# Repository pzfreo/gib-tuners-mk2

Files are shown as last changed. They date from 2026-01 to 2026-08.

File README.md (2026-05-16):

# gib-tuners

Parametric CAD project for historic guitar tuner restoration using build123d.

## Overview

This project generates 5-gang tuning machine assemblies (right-hand and left-hand variants) based on the engineering specification in `spec.md`. The design uses a "sandwich" assembly approach where all components can be inserted and retained without soldering.

## Installation

```bash
pip install -e .
```

Or for development:

```bash
pip install -e ".[dev]"
```

## Usage

### Build assemblies

```bash
# Production scale (1:1), both hands
python scripts/build_all.py --scale 1.0 --hand both

# 2x prototype for FDM printing
python scripts/build_all.py --scale 2.0 --tolerance prototype_fdm

# Just right-hand at production tolerance
python scripts/build_all.py --hand right

# Validate geometry without building
python scripts/build_all.py --validate-only
```

### Build frame only

```bash
python scripts/build_frame.py
python scripts/build_frame.py --scale 2.0 --hand left
```

### Visualize (requires OCP viewer)

```bash
python scripts/visualize.py
python scripts/visualize.py --component frame
python scripts/visualize.py --component tuner --scale 2.0
```

## Project Structure

```
gib-tuners-mk2/
├── src/gib_tuners/
│   ├── config/          # Dataclasses and parameters
│   ├── components/      # Individual parts (frame, peg_head, etc.)
│   ├── assembly/        # Assemblies (tuner unit, gang assembly)
│   ├── features/        # Reusable CAD operations
│   ├── export/          # STEP/STL export
│   └── utils/           # Mirroring, validation
├── scripts/             # CLI tools
├── tests/               # Test suite
├── reference/           # Reference STEP/DXF files
└── output/              # Generated files (gitignored)
```

## Key Files

- `spec.md` - Master engineering specification
- `7mm-globoid.json` - Gear calculator parameters
- `ARCHITECTURE.md` - Design documentation
- `CLAUDE.md` - Claude Code guidance

## Testing

```bash
pytest tests/
pytest tests/test_validation.py  # Spec Section 9 checks
```

## License

This project is released under the **Open Community License (OCL v1)** — a
non-commercial, share-alike license for open hardware and software. See
[`LICENSE`](./LICENSE) for the full text, or the canonical source at
[OpenCommunityLicence/OpenCommunityLicence](https://github.com/OpenCommunityLicence/OpenCommunityLicence).

In short:

- **Non-commercial users** may freely use, copy, modify, and hack the
  designs and code. If you redistribute your derivatives, you **must**
  release them under OCL or another non-commercial share-alike license
  that grants downstream users the same rights.
- **Commercial / business users** may use and modify the designs solely
  for their own internal production. Replicating, reselling, or
  otherwise commercialising the product or its components (other than
  internal right-to-repair) requires a **separate commercial license**
  from the copyright holder.
- Automated text and data mining of this repository is **not permitted**
  without explicit prior permission.

For commercial licensing enquiries, contact the copyright holder listed
in [`LICENSE`](./LICENSE).

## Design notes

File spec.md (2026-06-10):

# **Master Engineering Specification: Historic Tuner Restoration**

## **1\. System Overview**

* **Product:** 5-Gang Tuning Machine Assembly (Historic Reproduction).
* **Variants:** Right Hand (RH) and Left Hand (LH).
* **Mechanism:** Single-start Worm Drive (Sandwich Assembly).
  * **RH Unit:** Right-Hand (Clockwise) Thread.
  * **LH Unit:** Left-Hand (Counter-Clockwise) Thread.
  * *Goal:* Symmetrical tuning action (turning knobs "up" towards the headstock tip always tightens the string).
* **Manufacturing Strategy:**
  * **Frame:** Subtractive machining from **10.35mm² Brass Box Section** (1.0mm walls).
  * **Peg Head + Worm:** Investment cast as single piece, finish-machined.
  * **String Post:** Swiss Screw Machining (Auto-Lathe).
  * **Wheel:** Custom generated (separate, mates with string post).
* **Repairability:** Fully disassembleable (no soldered lids).
* **Design Constraint:** External frame geometry (outline, cutouts, mounting holes) is fixed to match historic appearance. Internal components (worm, wheel, posts) may be adjusted for function.

---

## **1a\. Parametric Build Configuration**

The build123d script shall support the following parameters:

### **Frame Parameters**
| Parameter | Default | Description |
|---|---|---|
| `box_outer` | 10.0mm | Outer dimension of square tube |
| `wall_thickness` | 1.0mm | Wall thickness (c13-10 production value, set in `config/c13-10/tuner_config.json`) |
| `housing_length` | 16.2mm | Length of each rigid box section |
| `end_length` | 10.0mm | Length from frame end to first/last housing edge (symmetric) |
| `num_housings` | 5 | Number of tuner positions (1 to N) |
| `tuner_pitch` | 27.2mm | Center-to-center spacing between adjacent tuners |
| `total_length` | *computed* | = 2 * end_length + housing_length + (num_housings - 1) * pitch |

**Note:** `total_length` is computed from the other parameters, ensuring symmetric ends regardless of the number of housings.

### **Tolerance Profiles**
| Profile | Bearing Holes | Clearance Holes | Use Case |
|---|---|---|---|
| `production` | +0.05mm (reamed) | +0.20mm | Machined brass, 100N rated |
| `prototype_resin` | +0.10mm | +0.20mm | 1:1 resin print validation |
| `prototype_fdm` | +0.20mm | +0.30mm | 2:1 FDM functional test |

*Bearing holes are derived: shaft diameter + bearing_clearance (0.05mm). Clearance holes: worm entry = shoulder + clearance, wheel inlet (5.1mm).*

### **Scale Parameter**
| Parameter | Default | Description |
|---|---|---|
| `scale` | 1.0 | Geometry scale factor (use 2.0 for FDM prototype) |

*Note: When `scale=2.0`, all dimensions are doubled. The script outputs both RH and LH variants at the specified scale.*

## **2\. Component A: The Reinforced Frame**

* **Material:** CZ121 Brass Box Section (10.0mm x 10.0mm x 1.0mm wall).
* **Total Length:** 145.0mm.
* **Internal Cavity:** 8.0mm x 8.0mm (10.0mm outer - 2×1.0mm walls).
* **End Length:** 10.0mm from frame end to first/last housing edge (symmetric ends).
* **Topology:**
  * **5x Rigid Housings:** 16.2mm long sections of full box profile to resist gear tension.
  * **Connectors:** Walls milled away between housings, leaving only the **Mounting Plate** (1.0mm thick) at Z=0 to connect the unit.
  * **Tuner Pitch:** 27.2mm center-to-center spacing between adjacent tuners.
* **Hand Identification:** "R" or "L" etched on inside surface of mounting plate (3mm tall, 0.3mm deep) near frame end at Y=2mm. Visible from below when looking into mechanism cavity.

### **Coordinate System**

```
     PLAYER'S VIEW (looking down at installed tuner)
     ================================================

        ↑ Posts stick up into air (+Z direction)
        |
   ─────┴─────  Z=0: Mounting plate (TOP, visible from above)
   │ mechanism │     - Mounting screw holes
   │  cavity   │     - Post bearing holes (posts emerge upward)
   │    ●────→ │     - "R"/"L" etching on INSIDE (Z=-1.1 surface)
   └───────────┘  Z=-10.0: Bottom (embedded in headstock)
        |              - Wheel inlet hole ONLY (for assembly)
        ↓
     [WOOD CAVITY]

   Z-axis convention:
   - Z=0        : Mounting plate surface (visible, sits on headstock)
   - Z=-1.0     : Inside surface of mounting plate (where "R"/"L" goes)
   - Z=-9.0     : Inside surface of bottom plate
   - Z=-10.0    : Bottom surface (inside wood cavity)
```

| Item | Z Location | Notes |
|---|---|---|
| Mounting plate surface | Z=0 | Visible from above |
| Mounting holes | Z=0 to Z=-1.1 | Drilled through top plate |
| Post bearing holes | Z=0 to Z=-1.1 | ø = post bearing_diameter + bearing_clearance |
| "R"/"L" etching | Z=-1.1 | Inside surface of mounting plate |
| Worm entry (RH) | RIGHT side (+X) | ø = peg shoulder_diameter + bearing_clearance |
| Peg bearing (RH) | LEFT side (-X) | ø = peg shaft_diameter + bearing_clearance |
| Wheel inlet | Z=-10.0 | Bottom plate, for assembly |

### **Mounting Holes**

* **Quantity:** 6 holes
* **Diameter:** ø3.0mm (clearance for mushroom-head bolts)
* **Location:** Bottom plate, in the gap sections between housings

| Hole # | Y Position (from frame start) | Description |
|---|---|---|
| 1 | 5.0mm | Before Housing 1 (centered in 0-10mm gap) |
| 2 | 31.7mm | Between Housing 1 & 2 |
| 3 | 58.9mm | Between Housing 2 & 3 |
| 4 | 86.1mm | Between Housing 3 & 4 |
| 5 | 113.3mm | Between Housing 4 & 5 |
| 6 | 140.0mm | After Housing 5 (centered in 135-145mm gap) |

### **Housing Positions (Symmetric)**

Housing positions are calculated to ensure symmetric 10mm ends:
- First center = (total_length - (num_housings - 1) * pitch) / 2 = (145 - 108.8) / 2 = 18.1mm

| Housing # | Center Y Position | Description |
|---|---|---|
| 1 | 18.1mm | First tuner |
| 2 | 45.3mm | Second tuner |
| 3 | 72.5mm | Third tuner (frame center) |
| 4 | 99.7mm | Fourth tuner |
| 5 | 126.9mm | Fifth tuner |

### **The "Sandwich" Drilling Pattern (Per Housing)**

To enable assembly without soldering:

1. **Bottom Face (Wheel Inlet):** ø5.1mm through-hole.
   * *Function:* Allows M2 washer/screw access for post retention. Wheel slides in sideways from open frame end.
2. **Top Face (Post Bearing):** bearing_diameter + bearing_clearance through-hole (reamed).
   * *Function:* Acts as the journal bearing for the String Post (5.0mm shaft, +0.05mm clearance).
3. **Side Faces (Worm Axle):** Asymmetric through-holes.
   * **Entry Side:** shoulder_diameter + bearing_clearance (shoulder must clear worm tip).
   * **Bearing Side:** shaft_diameter + bearing_clearance (reamed).
   * *Note:* For RH frame, entry is on RIGHT side (+X). LH frame is mirrored.
   * *Retention:* Cap (8.5mm) sits against frame exterior, cannot pass through entry hole.

## **3\. Component B: The Gear Set**

* **Constraint:** Wheel slides in sideways from open frame end (worm must be installed first for globoid meshing).
* **Module:** **0.6** (M0.6)
* **Pressure Angle:** **20°**

**IMPORTANT:** All gear parameters (ratio, center distance, diameters, tooth counts) are defined in `config/<profile>/worm_gear.json`. The JSON file is the **source of truth** for gear geometry. Do not hardcode gear values in code or tests—always load from the JSON.

### **1\. Worm (Driver) - Integral to Peg Head**

The worm thread is cast/machined as part of the peg head assembly (not a separate gear).

* **Reference geometry:** `config/<profile>/worm_m0.6_z1.step` (for tooth profile)
* **Parameters:** Loaded from `config/<profile>/worm_gear.json` → `worm` section
* **Hand:** Right (LH variant uses left-hand worm)
* **Material:** Brass (cast with peg head)

Key parameters from JSON:
- `tip_diameter_mm` - Outer diameter
- `pitch_diameter_mm` - For center distance calculation
- `type` - Cylindrical or globoid

*Note: Worm STEP file provides reference geometry for machining the thread on the cast peg head shaft.*

### **2\. Worm Wheel (Driven) - Separate Part**

* **Source:** `config/<profile>/wheel_m0.6_z<N>.step` (N = tooth count from JSON)
* **Parameters:** Loaded from `config/<profile>/worm_gear.json` → `wheel` section
* **Bore:** DD cut (from `features.wheel` in JSON)
* **Material:** Brass

Key parameters from JSON:
- `num_teeth` - Tooth count (determines ratio)
- `tip_diameter_mm` - Outer diameter
- `pitch_diameter_mm` - For center distance calculation
- `features.wheel.bore_diameter_mm` - DD cut bore diameter

The wheel is a separate component that slides onto the string post and enables sandwich assembly.

### **DD Cut Bore Interface (Wheel Only)**

DD cut parameters are defined in `config/<profile>/worm_gear.json` → `features.wheel`:
- `bore_diameter_mm` - Bore diameter (mates with string post DD section)
- `anti_rotation` - Type of anti-rotation feature (ddcut)

The DD cut is created by milling two parallel flats on the string post shaft.

### **Center Distance Calculation**

Center distance is defined in `config/<profile>/worm_gear.json` → `assembly.centre_distance_mm`.

Formula: CD = (Worm PD + Wheel PD) / 2 (may vary with profile shift)

### **Assembly Parameters**

All assembly parameters are loaded from `config/<profile>/worm_gear.json` → `assembly` section:
- `centre_distance_mm` - Worm-to-wheel axis distance
- `pressure_angle_deg` - Standard 20°
- `backlash_mm` - Configurable backlash
- `ratio` - Gear ratio (equals wheel tooth count for single-start worm)

## **4\. Component C: The Peg Head Assembly**

The peg head, shaft, and worm thread are cast as a single brass piece, then finish-machined. This provides maximum strength and eliminates the need for a separate worm gear.

### **Peg Head Geometry (from Onshape model)**

| Dimension | Variable | Value | Description |
|---|---|---|---|
| Ring OD | headouterd | 12.5mm | Outer diameter of peg head ring |
| Ring Bore | headinnerd | 9.8mm | Inner bore diameter (finger grip) |
| Ring Width | headthicknessattop | 2.4mm | Width of ring at outer edge (after face cuts) |
| Bore Offset | headinneroffset | 0.25mm | Bore center offset from ring center |
| Chamfer | smoothedges | 0.3mm | Edge chamfer on ring faces |
| Button Diameter | capd | 8.0mm | Decorative end button |
| Button Height | capl | 1.0mm | Height of decorative button |

*Note: The peg head ring is created using a revolved profile construction. The hollow bore (~9.8mm) provides finger grip for fine tuning.*

### **Ring Construction (Reference STEP)**

The peg head geometry is imported from a reference STEP file (`reference/peghead-and-shaft.step`) exported from Onshape, then combined with a new shaft and worm thread.

**Construction steps:**
1. **Import peg head STEP:** Contains ring, pip, join, cap, and shoulder
2. **Cut at Z=0:** Keep only Z ≤ 0 (peg head portion), discard original shaft
3. **Add new shaft:** 4.5mm diameter (bearing section)
4. **Add worm thread:** Import from `config/<profile>/worm_m0.6_z1.step`, position at Z=0
5. **Add M2 tap hole:** At shaft end for retention screw

**Reference STEP orientation:** Shaft along Z, peg head at Z ≤ 0
**Assembly orientation:** Rotated -90° around Y so shaft is along X, pip at -X

### **Integral Shaft + Worm (Combined from STEP files)**

The peg head and worm are combined from reference STEP files with a new shaft section.

| Section | Diameter | Length | Z Position | Description |
|---|---|---|---|---|
| Peg head | - | - | Z ≤ 0 | Imported from STEP (ring, pip, cap, shoulder) |
| Worm thread | 7.0mm OD / 4.5mm shaft | 7.7mm | Z = 0 to 7.7 | From `manufacturing.worm_length_mm` in JSON |
| Bearing shaft | 4.5mm | 1.3mm | Z = 7.7 to 9.0 | Through frame wall to outer face + 0.15mm protrusion (constant 1.3mm) |
| M2 tap hole | 1.6mm | 3mm deep | At Z = 9.0 | Retention screw |

**Total shaft length:** 9.0mm (from Z=0 to Z=9.0)

**Key dimensions:**
- Worm length from `manufacturing.worm_length_mm` in JSON (7.7mm)
- Shaft diameter (4.5mm) < worm root (4.75mm) → worm fits over shaft
- Shaft (4.0mm) fits in peg bearing hole (shaft + clearance) → 0.05mm clearance
- Cap (8.5mm) > worm entry hole (shoulder + clearance) → stops push-in

### **Worm Thread Geometry**

The worm thread is imported from `config/<profile>/worm_m0.6_z1.step`:

All worm parameters are loaded from `config/<profile>/worm_gear.json` → `worm` section:

* **Type:** From `worm.type` (cylindrical or globoid)
* **Outer Diameter (tip):** From `worm.tip_diameter_mm`
* **Pitch Diameter:** From `worm.pitch_diameter_mm`
* **Root Diameter:** From `worm.root_diameter_mm` (shaft must be ≤ this)
* **Shaft Diameter:** 4.5mm (from tuner_config.json, must be < worm root)
* **Length:** From `manufacturing.worm_length_mm` (7.7mm)
* **Lead:** From `worm.lead_mm` (π × module)
* **Lead Angle:** From `worm.lead_angle_deg`

### **Shaft Retention**

* **Push-in prevention:** Cap (8.5mm) sits against frame exterior, cannot pass through entry hole
* **Pull-out prevention:** M2 × 4mm pan head screw + washer on bearing shaft end
  * Washer: 5.5mm OD, 2.7mm ID, 0.5mm thick (larger than peg bearing hole)
  * Screw head OD: ~3.8mm (holds washer in place)
  * Total protrusion: ~1.8mm beyond shaft end

### **Peg Head Assembly Sequence**

1. Cast peg head with integral shaft (rough form)
2. Finish-turn shaft to 4.5mm bearing diameter
3. Machine worm thread (reference STEP geometry)
4. Tap M2 hole in shaft end
5. Insert assembly through frame (worm enters entry hole, shaft exits bearing hole)
6. Place washer (5.5mm OD) on shaft end
7. Thread M2 × 4mm pan head screw into shaft end to retain

### **Disassembly for Repair**

1. Remove M2 screw from shaft end
2. Slide peg head + worm assembly out through entry hole
3. Replace entire peg head assembly if needed
4. Reassemble

### **Manufacturing**

**Investment cast + finish machine:**
1. Investment cast peg head + shaft + rough worm form in brass
2. Finish-turn shaft sections to final dimensions
3. Machine globoid worm thread (single-point or form tool)
4. Tap M2 hole in shaft end

*Note: The worm thread may be cast near-net-shape and only require cleanup, or may be machined from a plain shaft section depending on casting capability.*

## **5\. Component D: The String Post (Vertical)**

* **Manufacturing:** Swiss Sliding Head Lathe (Swiss Auto) or manual lathe.
* **Stock:** 8.0mm round brass/steel bar.
* **Cap:** Decorative 7.5mm cap with 0.25mm fillet edges and 3 concentric V-grooves (0.33mm wide/deep, outer OD 6mm).
* **Top Section:** 6.0mm visible post (runs in the Top Face hole).
* **Frame Bearing:** 5.0mm shaft (runs in ø5.05mm frame hole).
* **Gear Interface:** DD cut section (bore dia minus 0.1mm clearance) for slip-fit rotational location in wheel bore. Compression retention via M2 washer+screw.
* **Retention:** M2 tap bore in bottom of DD section for nut + washer.
* **String Hole:** ø1.5mm cross-hole, centered in visible post (2.75mm from frame top).

### **String Post Dimensions (Bottom to Top)**

| Section | Diameter | Length | Description |
|---|---|---|---|
| DD cut (wheel interface) | bore_dia - `dd_shaft_clearance` | *derived* | = `wheel.face_width` - `dd_cut_clearance` |
| M2 tap bore | ø1.6mm | 4mm deep | Tapped hole in bottom of DD for retention |
| Frame bearing | 5.0mm | *derived* | = `wall_thickness + axial_play` (1.1mm) |
| Visible post | 6.0mm | 5.5mm | Above frame, aesthetic |
| String hole | ø1.7mm | through | Cross-drilled, centered in post (2.75mm from frame) |
| Cap | 7.5mm | 1.0mm | 0.25mm fillet top/bottom, 3× V-grooves (0.33mm, outer OD 6mm) |

**Derived lengths:**
- `bearing_length` = `wall_thickness` (1.0mm) + `post_bearing_axial_play` (0.1mm) = **1.1mm**
- `dd_cut_length` = `wheel.face_width` - `dd_cut_clearance` (e.g. 7.7 - 0.5 = **7.2mm**)

**Total length:** cap + post + bearing + DD = 1.0 + 5.5 + 1.1 + dd_cut_length (e.g. **14.8mm**)

### **DD Cut Shaft Interface**

The string post DD cut section provides rotational location in the wheel's DD bore. The shaft DD is undersized by `dd_shaft_clearance` (0.1mm) for a slip fit; compression from the M2 washer+screw provides retention force. DD bore dimensions are loaded from `features.wheel.bore_diameter_mm` in `worm_gear.json`:

* **Bore diameter:** from JSON `bore_diameter_mm` (e.g. 3.5mm)
* **Shaft diameter:** bore_diameter - `dd_shaft_clearance` (e.g. 3.4mm)
* **Flat depth:** 0.5mm (each side)
* **Shaft across flats:** bore AF - `dd_shaft_clearance` (e.g. 2.4mm)
* **Length:** = `wheel.face_width` - `dd_cut_clearance` (e.g. 7.6 - 0.5 = 7.1mm)
* **Bottom gap:** `dd_cut_clearance` (0.5mm) — compression travel for washer clamping

### **M2 Tap Bore Retention**

The DD section has an M2 tapped hole drilled up from the bottom:

* **Tap drill:** ø1.6mm (for M2 thread)
* **Depth:** 4mm (for standard M2 × 4mm screw)
* **Hardware:** M2 × 4mm machine screw + M2 washer (~5mm OD)

An M2 screw threads into the tap bore from below, with a washer to retain the wheel.

### **String Post Retention**

* **Pull-up prevention:** 7.5mm cap cannot pass through 5.05mm frame hole
* **Pull-down prevention:** M2 screw + washer in tap bore
  * Washer OD: ~5mm (larger than DD bore from JSON)
  * Screw holds washer in place
* **Wheel retention:** Bearing shoulder above wheel, M2 screw + washer below wheel

### **String Post Assembly Sequence**

**Assembly Constraints:**
- Worm MUST be installed first (required for globoid meshing, recommended for cylindrical)
- Wheel OD (from JSON) cannot fit through post bearing hole - insert separately

1. Install peg head (worm) first - secure with M2 screw + washer
2. Slide wheel sideways into cavity from open frame end (meshes with worm)
3. Insert string post from above through bearing hole (ø5.05mm)
4. DD section engages wheel bore, creating the sandwich
5. Tap M2 thread into post (stronger with wheel supporting the DD section)
6. Thread M2 screw + washer through bottom hole (ø5.1mm) into tap bore

## **5a. Post/Wheel/Frame Sandwich Mechanism**

The string post and wheel rotate as a unit. The frame is NOT clamped between them—instead, the frame floats with axial clearance.

### Clamping Mechanism

When the M2 retention screw is tightened:
1. Screw pulls wheel upward toward post
2. Wheel rises until it contacts the **5mm→3.5mm shoulder** on the post
3. Post shoulder (6mm→5mm) rests on frame top surface
4. Frame floats between these two reference points with axial play

### Cross-Section (Y-Z plane through post axis)

```
                    ┌─────────────────┐
                    │   POST (6mm)    │
POST SHOULDER ══════╧═════════════════╧══════  ← rests on frame top (Z=0)
─────────────────────────────────────────────  FRAME TOP SURFACE
░░░░░░░░░░░░░░░░░░░░│░░░░░░░░░░░░░░░░░░░░░░░  wall (1.0mm)
─────────────────────│───────────────────────  CAVITY CEILING (Z=-1.0)
                     │ bearing (5mm Ø)
                     │    ↕ axial_play        ← FREE GAP (frame floats here)
    ─────────────────┼───────────────────────  CLAMP SHOULDER (Z=-1.2)
                     │ DD section (3.5mm)     ↑
                ┌────┴────┐                   │ wheel pulled up by screw
                │  WHEEL  │                   │
                │         │                   │
        ────────┴─────────┴────────           ← CAVITY FLOOR (5.1mm inlet hole)
                     │
                   [M2 screw + washer from below]
```

**Note:** Wheel sits in cavity (wheel OD from JSON > 5.1mm inlet hole). The 5.1mm inlet hole provides access for M2 screw + washer to retain the post. Wheel is constrained by clamp shoulder above and cavity floor below.

### Parametric Constraints

| Parameter | Formula | Value |
|---|---|---|
| `wall_thickness` | design choice | 1.0mm (c13-10, via tuner_config.json) |
| `post_bearing_axial_play` | design choice | 0.1mm |
| `wheel.face_width` | from gear config | 7.7mm |
| `dd_shaft_clearance` | design choice | 0.1mm |
| `dd_cut_clearance` | design choice | 0.5mm |
| `bearing_length` | `wall_thickness + axial_play` | 1.1mm |
| `dd_cut_length` | `wheel.face_width - dd_cut_clearance` | 7.2mm |

**Key points:**
- `axial_play` is a design choice (0.1mm provides free rotation)
- Wheel sits in cavity (wheel OD from JSON > 5.1mm hole); enters sideways from open frame end
- DD cut is 0.1mm shorter than wheel to ensure screw clamps wheel to shoulder
- Bearing length > wall thickness ensures axial play exists

### Why This Works

- **Axial play** allows free rotation without binding
- **Bearing section > wall** positions the clamp shoulder inside cavity
- **DD cut = wheel width** ensures full anti-rotation engagement
- **Frame floats** on the bearing with clearance, never clamped

## **6\. Manufacturing Process (Step-by-Step)**

### **Phase 1: Frame Machining (Mill/Drill)**

1. **Cut Stock:** Cut 10.0mm Box section to 145mm.
2. **Mill Profile:** Clamp stock. Mill away the Top and Side walls in the "Gap" sections to create the 5 isolated boxes.
3. **Drill Vertical:**
   * Drill & ream post bearing holes on Top Face (bearing_diameter + bearing_clearance).
   * Drill **ø5.1mm** wheel inlet holes on Bottom Face (M2 washer access).
   * Drill **ø3.2mm** mounting holes on Bottom Plate at specified Y positions.
4. **Drill Horizontal (Asymmetric):**
   * Drill worm entry holes on one side (shoulder_diameter + bearing_clearance).
   * Drill & ream peg shaft bearing holes on opposite side (shaft_diameter + bearing_clearance).
5. **Finish:** Deburr internal edges.

### **Phase 2: Wheel Production**

The wheel is manufactured from STEP file generated by gear calculator:

* **Source:** `config/<profile>/wheel_m0.6_z<N>.step` (N = tooth count from JSON)
* Tooth count and width from `worm_gear.json`
* DD cut bore from `features.wheel.bore_diameter_mm` (built into STEP)

*Note: Worm is integral to peg head casting - see Phase 3.*

### **Phase 3: Peg Head + Worm Production**

Investment cast peg head with integral shaft and worm thread:

1. Investment cast peg head + shaft + rough worm form in brass
2. Finish-turn shaft to 4.5mm bearing diameter
3. Machine worm thread (reference `config/<profile>/worm_m0.6_z1.step` for geometry)
4. Tap M2 hole in shaft end

*Note: Casting the worm integral with the shaft provides maximum strength.*

### **Phase 4: String Post Production**

1. Turn from **8mm brass/steel bar:**
   * 7.5mm cap (1mm high, 0.25mm fillet, 3× V-grooves)
   * 6mm visible post (5.5mm high)
   * 5mm frame bearing section (1.1mm, through frame + axial play)
   * DD cut gear interface (bore_dia - 0.1mm clearance, slip fit in wheel bore)
   * M2 tap bore (~4mm deep, for screw retention)
2. Mill DD flats on shaft section (undersized for slip fit)
3. Tap M2 hole in bottom
4. Cross-drill ø1.7mm string hole (2.75mm from frame top), chamfer both entries (0.3mm)

### **Phase 5: Assembly (The "Sandwich" Logic)**

**Assembly order: Worm → Wheel → Post** (worm must be in place first for globoid meshing).

1. **Install Peg Head (Worm):** Slide **Peg Head + Worm** through **Entry Hole**. The ø4.0mm shaft passes through opposite **Bearing Hole**.
2. **Secure Peg Head:** Place **5.5mm washer** on shaft end, thread **M2 × 3mm pan head screw** to retain.
3. **Insert Wheel:** Slide **Worm Wheel** sideways into cavity from open frame end. Wheel OD (from JSON) cannot fit through post bearing hole - must insert separately.
4. **Insert Post:** Slide **String Post** from above through **Top Hole**. DD section engages wheel bore.
5. **Tap Post:** Drill and tap M2 hole in post (stronger with wheel supporting DD section).
6. **Secure Post:** Thread **M2 × 3mm screw + washer** through **Bottom Hole** (ø5.1mm) into post tap bore.
7. **Complete:** Peg head secured with M2 screw + washer, post secured with M2 screw + washer.

## **7\. The Left Hand (LH) Variant**

* **Geometry:** The LH Frame is a **Mirror Image** of the RH Frame.  
* **Functional Inversion:**  
  * **Worm:** Uses **Left-Hand (CCW) Thread**.  
  * **Wheel:** Uses **Left-Hand Helix**.  
  * **Result:** Turning the knob in the *symmetrical* direction relative to the headstock produces the *same* tensioning result (tightening). This mimics high-end historic instruments.

## **8\. Derived Dimensions for Manufacture**

* **Center Distance (CD):** Distance from Worm Axis to Post Axis.
  * Loaded from `config/<profile>/worm_gear.json` → `assembly.centre_distance_mm`
  * Formula: CD = (Pitch Dia Worm + Pitch Dia Wheel) / 2 (may vary with profile shift)
* **Vertical Alignment:** (using Section 2 coordinate system: Z=0 at mounting plate)
  * Internal Cavity: Z = -1.0mm (ceiling) to Z = -9.0mm (floor), height = 8.0mm.
  * Worm Axis Height: **Z = -5.0mm** (Centered in cavity).
  * Worm Clearance: 8.0mm cavity - 7.0mm worm OD = **1.0mm total** (0.5mm top/bottom).
  * Wheel Pitch Plane: **Z = -5.0mm** (Must align with worm).
* **Horizontal Hole Offset:**
  * Post Axis (top/bottom holes): X = 0 (centered on frame width).
  * Worm Axis (side holes): Offset from post axis by **CD** (= `assembly.centre_distance_mm` from JSON).
  * *Note:* Frame is 10.0mm wide, internal cavity is 8.0mm. Worm axis at X = CD from post axis places the side holes off-center.

### **Y-Axis Offset for Worm/Wheel Engagement**

The worm and wheel axes are offset from the housing center along Y to achieve proper center distance while centering the mechanism within each housing. This also provides a preload mechanism where string tension takes up backlash.

```
     HOUSING (16.2mm along Y)
     ========================

     Y=0 end (toward nut/bridge)              Y=145 end
     String pulls this way ←
       |                                           |
       |    POST        WORM                       |
       |      │    CD      │                       |
       |      │<---------->│                       |
       |      ●            ●                       |
       |   -CD/2       +CD/2                       |
       |      from housing center                  |
       |                                           |

     String tension pulls post toward -Y.
     Post pivots at top bearing, wheel (at bottom) swings +Y into worm.
```

| Item | Y Position | Notes |
|---|---|---|
| Housing center | housing_y | Computed from frame parameters |
| Post axis | housing_y - CD/2 | Offset toward -Y (nut end) |
| Worm axis | housing_y + CD/2 | Offset toward +Y (bridge end) |
| Center distance (CD) | from JSON | `assembly.centre_distance_mm` in worm_gear.json |
| Extra backlash | configurable | Parameter for additional play beyond gear design |

**Preload mechanism:** String tension pulls the string post toward -Y (toward the nut/bridge). The post pivots at its top bearing, causing the wheel (at the bottom of the post) to swing toward +Y, pushing into the worm and taking up backlash.

**Both RH and LH variants:** Use the same offset directions (post toward -Y, worm toward +Y from housing center).

---

## **9\. Geometry Validation Checklist**

Before manufacturing, verify (values loaded from `worm_gear.json`):

- [x] Worm OD fits within internal cavity height (8.0mm) with clearance
- [x] Worm OD passes through entry hole with clearance
- [x] Peg head shaft (4.5mm) fits in bearing hole (shaft + clearance) ✓ 0.05mm clearance (reamed)
- [x] Wheel OD enters sideways from open frame end (worm first for globoid) ✓
- [x] Post shaft (5.0mm) fits in top bearing hole (5.05mm) ✓ 0.05mm clearance (reamed)
- [x] Post cap (7.5mm) stops pull-through top hole (5.05mm) ✓
- [x] Peg head cap (8.5mm) stops pull-in through entry hole ✓
- [x] M2 screw + washer (5.5mm OD) stops peg pull-out through bearing hole ✓
- [x] Center distance (from JSON) fits within frame geometry ✓
- [x] Sandwich assembly sequence verified ✓
- [x] Worm integral to peg head casting ✓
- [x] DD cut bore in wheel (from JSON) for string post ✓
- [x] M2 thread passes through wheel DD across-flats ✓
- [x] M2 washer retains wheel (larger than DD bore) ✓
- [x] Custom wheel STEP file generated ✓

### **Gear Mesh Validation**

All gear parameters are validated from `config/<profile>/worm_gear.json`:

| Parameter | Check |
|---|---|
| Module | Worm and wheel must match (0.6) |
| Center Distance | Loaded from `assembly.centre_distance_mm` |
| Pressure Angle | Standard 20° |
| Ratio | Equals `wheel.num_teeth` for single-start worm |
| Worm Type | From `worm.type` (cylindrical or globoid) |

### **Hardware List (per tuner)**

| Item | Specification | Qty |
|---|---|-----|
| Peg head + worm | Cast brass, integral worm (type from JSON), 4.5mm shaft | 1 |
| Worm wheel | Custom STEP from `config/<profile>/`, M0.6, params from JSON | 1 |
| Peg retention screw | M2 × 4mm pan head | 1 |
| Peg retention washer | 5.5mm OD, 2.7mm ID, 0.5mm thick | 1 |
| Post retention screw | M2 × 4mm pan head | 1 |
| Post retention washer | M2 washer (~5mm OD, ~2.2mm ID) | 1 |

### **Source Files**

| File | Description |
|---|---|
| `reference/peghead-and-shaft.step` | Complete peg head + shaft reference geometry (from Onshape) |
| `config/<profile>/worm_m0.6_z1.step` | Worm reference geometry (for machining cast shaft) |
| `config/<profile>/wheel_m0.6_z<N>.step` | Worm wheel (N = tooth count from JSON) |
| `config/<profile>/worm_gear.json` | **Source of truth** for all gear parameters |

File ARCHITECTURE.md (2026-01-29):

# Architecture Documentation

## System Overview

This project generates parametric CAD models for historic 5-gang guitar tuning machines. The design uses a "sandwich" assembly approach where all components can be inserted and retained without soldering.

## Component Hierarchy

```
GangAssembly (5 tuners)
├── Frame (single piece)
│   ├── 5x Rigid Housings (full box profile)
│   ├── 4x Connectors (bottom plate only)
│   └── 6x Mounting Holes
│
└── 5x TunerUnit
    ├── PegHead (cast with integral worm)
    │   ├── Ring head (finger grip)
    │   ├── Shaft (3.8mm bearing surface)
    │   ├── Worm thread (globoid, integral)
    │   └── M2 retention screw + washer
    │
    ├── StringPost (Swiss screw machined)
    │   ├── Decorative cap (7.5mm)
    │   ├── Visible post (6.0mm)
    │   ├── Frame bearing (4.0mm)
    │   ├── DD cut interface (3.0mm)
    │   ├── E-clip groove (2.5mm shaft)
    │   └── String hole (1.5mm cross-drilled)
    │
    └── WormWheel (separate, mates with post)
        ├── 12 teeth, M0.5
        ├── DD cut bore (3.0mm)
        └── 6.0mm face width
```

## Data Flow

```
7mm-globoid.json ──┐
                   │
spec.md ───────────┼──► parameters.py ──► components/*.py ──► assembly/*.py ──► export/
                   │         │
tolerances.py ─────┘         │
                             ▼
                      features/*.py
                    (DD cuts, drilling)
```

## Design Decisions

### 1. Frozen Dataclasses

All parameter classes are frozen (`@dataclass(frozen=True)`) to ensure:
- Thread safety
- Hashability for caching
- Clear separation between configuration and CAD operations

### 2. Tolerance Profiles

Three profiles support the manufacturing workflow:
- `production`: +0.05mm holes for machined brass
- `prototype_resin`: +0.10mm for 1:1 resin validation prints
- `prototype_fdm`: +0.20mm for 2:1 FDM functional tests

### 3. Scale Factor

The `BuildConfig.scale` parameter allows generating enlarged prototypes:
- Scale 1.0: Production dimensions
- Scale 2.0: Double-size for FDM printing (easier to print, test fit)

All dimensions are multiplied by scale except tolerances.

### 4. Left/Right Hand Mirroring

The LH variant is a geometric mirror of RH, with:
- Mirrored frame geometry
- Left-hand worm thread (counter-clockwise)
- Left-hand wheel helix

This ensures symmetrical tuning action on the instrument.

### 5. Sandwich Assembly

The design enables full disassembly without soldering:

1. **Peg Head**: Retained by shoulder (pull-in) and M2 screw+washer (pull-out)
2. **String Post**: Retained by cap (pull-up) and E-clip (pull-down)
3. **Wheel**: Slides onto DD cut, retained by E-clip below

### 6. DD Cut Interface

Double-D cuts provide anti-rotation between wheel and string post:
- 3.0mm nominal diameter
- 0.6mm flat depth each side
- 1.8mm across flats

## Frame Geometry

The frame is machined from 10.35mm square brass tube:

```
         ┌─────────────────────────────────────────────────────────────┐
         │  Housing 1    Housing 2    Housing 3    Housing 4    Housing 5  │
         │    15.1mm      42.3mm       69.5mm       96.7mm      123.9mm    │
         │  ┌───────┐   ┌───────┐   ┌───────┐   ┌───────┐   ┌───────┐    │
  Side ──│  │       │   │       │   │       │   │       │   │       │    │── Side
         │  └───────┘   └───────┘   └───────┘   └───────┘   └───────┘    │
         │      ○           ○           ○           ○           ○        │
         │    4.5mm      31.7mm      58.9mm      86.1mm     113.3mm  140.5mm│
         └─────────────────────────────────────────────────────────────┘
                                  Bottom Plate
                              (mounting holes shown)
```

### Per-Housing Drilling Pattern

```
                    Top (ø4.2mm post bearing)
                           │
                    ┌──────┴──────┐
                    │             │
    Entry ──────────│    ○        │────────── Bearing
    (ø6.2mm)        │    │        │           (ø4.0mm)
                    │    │5.5mm   │
                    │    ▼        │
                    └──────┬──────┘
                           │
                    Bottom (ø8.0mm wheel inlet)
```

## Validation (Spec Section 9)

Automated checks verify:
- Component clearances (worm fits in cavity, wheel fits through hole)
- Retention geometry (caps larger than holes)
- Center distance calculation
- Gear mesh compatibility (module, pressure angle)

## File Outputs

```
output/
├── rh/
│   ├── frame.step
│   ├── peg_head.step
│   ├── string_post.step
│   ├── wheel.step
│   └── assembly.step
└── lh/
    ├── frame.step
    ├── peg_head.step
    ├── string_post.step
    ├── wheel.step
    └── assembly.step
```

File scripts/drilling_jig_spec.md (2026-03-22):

# Drilling Jig Specification

## Overview

Two-part clamshell jig for drilling all 26 holes in a 5-gang right-hand brass tuner frame. The clamshell wraps around the frame from the top and sides (inverted U cross-section). A removable base plate closes the bottom and provides guide holes for wheel inlet drilling.

All gear-dependent dimensions (center distance, worm Z position, drill diameters, etc.) are read from the JSON file for the selected gear definition. Uses the same `--gear` argument and config loading as `build.py` (`resolve_gear_config()` + `create_default_config()`).

Example values below are for the **bh11-cd** gear profile (M0.6, 11T, CD=5.6mm, globoid worm).

## Usage

```bash
python scripts/drilling_jig.py --gear bh11-cd
python scripts/drilling_jig.py --gear balanced
python scripts/drilling_jig.py --list-gears
```

## Parts

| Part | Description |
|---|---|
| Clamshell | Solid block with pocket from below. Stepped M14 bushing pockets (blind M14 + smaller bore) on top and sides. Printed mounting hole guides. End walls act as end stops. Extended walls enclose side bushings with 5mm minimum rim. |
| Base plate | Flat plate with raised lip, bolted to clamshell bottom. Lip pushes frame flush against pocket ceiling. Printed guide holes for wheel inlet drilling. |

## Clamshell Dimensions (bh11-cd)

| Parameter | Value | Description |
|---|---|---|
| Width (X) | 40.0mm | Total external width |
| Length (Y) | 155.0mm | Frame length + 2 x 5mm end walls |
| Height (Z) | 30.9mm | 14mm top slab + 16.9mm channel depth |
| Channel width | 10.3mm | 10mm frame + 0.3mm clearance |
| Channel depth | 16.9mm | Frame height (10mm) + wall extension (6.9mm) |
| Channel length | 145.0mm | Matches frame length |
| Side wall thickness | ~14.85mm | (40 - 10.3) / 2 |
| Top slab thickness | 14.0mm | 10mm bushing engagement + 4mm structure |
| End wall thickness | 5.0mm | End stops for frame Y registration |
| Wall extension | 6.9mm | Walls extend below frame to enclose side bushings |

### Wall Extension Derivation

The wall extension ensures 5mm minimum rim below the side bushing bottom edge:

```
bushing_bottom_z = worm_z - BUSHING_OD/2 = -4.9 - 7.0 = -11.9mm
wall_extension = abs(bushing_bottom_z) - frame_outer + BUSHING_RIM
               = 11.9 - 10.0 + 5.0 = 6.9mm
channel_depth = frame_outer + wall_extension = 10.0 + 6.9 = 16.9mm
```

This is computed dynamically per gear profile.

## Base Plate Dimensions (bh11-cd)

| Parameter | Value | Description |
|---|---|---|
| Width (X) | 40.0mm | Matches clamshell |
| Length (Y) | 155.0mm | Matches clamshell |
| Thickness (Z) | 8.0mm | Structural base |
| Lip width (X) | 10.0mm | Matches frame outer, fits inside 10.3mm channel |
| Lip length (Y) | 145.0mm | Matches frame length |
| Lip height (Z) | 6.9mm | Matches wall extension |

The lip fits inside the clamshell pocket and pushes the frame flush against the pocket ceiling. Bolt holes are in the outer flanges (outside the lip).

## Gear Parameters (bh11-cd Profile)

| Parameter | Value | Notes |
|---|---|---|
| Center distance | 5.6mm | Worm-to-wheel axis distance |
| CD/2 | 2.8mm | Axis offset from housing center |
| Worm Z position | -4.9mm | Aligned mode for globoid worm |
| Post axis Y offset | -CD/2 | Toward nut end (-Y) |
| Worm axis Y offset | +CD/2 | Toward bridge end (+Y) |

### Worm Z Derivation

For the bh11-cd globoid profile with virtual hobbing (aligned mode):

```
face_width = 7.6mm (wheel width)
dd_cut_length = face_width - dd_clearance = 7.6 - 0.1 = 7.5mm
bearing_length = wall_thickness + axial_play = 1.1 + 0.1 = 1.2mm
post_z_offset = -(dd_cut_length + bearing_length) = -8.7mm
worm_z = post_z_offset + face_width/2 = -8.7 + 3.8 = -4.9mm
```

## Stepped Bushing Pocket Design

Side bushing pockets use a stepped (blind pocket + bore) design to ensure structural integrity:

```
Side wall cross-section (X direction):
outer face |<-- 10mm M14 pocket -->|<-- 4.85mm bore -->| inner face
X=+/-20    |      dia 14mm         |   dia 7.05/4.05   | X=+/-5.15
```

- **Outer pocket:** dia 14mm x 10mm deep from outer wall face. M14 bushing threads into this pocket.
- **Inner bore:** Drill diameter (7.05mm for worm entry, 4.05mm for peg bearing) through remaining 4.85mm of wall to channel face.

This gives full wall containment around the M14 bushing body. Only the smaller drill bore penetrates to the channel interior.

Top face bushing pockets are through-holes (dia 14mm through 14mm top slab) since the full slab depth exceeds the 10mm bushing engagement.

## Bushing Positions (bh11-cd)

All Y values from frame start (Y=0). Housing centers: 18.1, 45.3, 72.5, 99.7, 126.9mm.

### Post Bearing Bushings (top face, M14, dia 4.05mm bore)

Drill vertically from above through the mounting plate.

| # | X (mm) | Y (mm) | Bore |
|---|---|---|---|
| PB1 | 0 | 15.3 | dia 4.05mm |
| PB2 | 0 | 42.5 | dia 4.05mm |
| PB3 | 0 | 69.7 | dia 4.05mm |
| PB4 | 0 | 96.9 | dia 4.05mm |
| PB5 | 0 | 124.1 | dia 4.05mm |

Y = housing_center - CD/2. Adjacent spacing = 27.2mm.

### Worm Entry Bushings (right wall, M14 stepped, dia 7.05mm bore)

Drill horizontally from +X side through housing wall.

| # | Y (mm) | Z (mm) | Bore |
|---|---|---|---|
| WE1 | 20.9 | -4.9 | dia 7.05mm |
| WE2 | 48.1 | -4.9 | dia 7.05mm |
| WE3 | 75.3 | -4.9 | dia 7.05mm |
| WE4 | 102.5 | -4.9 | dia 7.05mm |
| WE5 | 129.7 | -4.9 | dia 7.05mm |

Y = housing_center + CD/2. Z = worm axis position.

### Peg Bearing Bushings (left wall, M14 stepped, dia 4.05mm bore)

Drill horizontally from -X side. Same Y,Z positions as worm entry.

| # | Y (mm) | Z (mm) | Bore |
|---|---|---|---|
| PeB1 | 20.9 | -4.9 | dia 4.05mm |
| PeB2 | 48.1 | -4.9 | dia 4.05mm |
| PeB3 | 75.3 | -4.9 | dia 4.05mm |
| PeB4 | 102.5 | -4.9 | dia 4.05mm |
| PeB5 | 129.7 | -4.9 | dia 4.05mm |

## Printed Guide Holes

### Mounting Holes (top face, dia 3.0mm)

Drill vertically from above through the mounting plate at gap positions.

| # | X (mm) | Y (mm) |
|---|---|---|
| MH1 | 0 | 5.0 |
| MH2 | 0 | 31.7 |
| MH3 | 0 | 58.9 |
| MH4 | 0 | 86.1 |
| MH5 | 0 | 113.3 |
| MH6 | 0 | 140.0 |

### Wheel Inlet Holes (base plate, dia 5.1mm)

Drill vertically from below through housing bottom wall.

| # | X (mm) | Y (mm) |
|---|---|---|
| WI1 | 0 | 15.3 |
| WI2 | 0 | 42.5 |
| WI3 | 0 | 69.7 |
| WI4 | 0 | 96.9 |
| WI5 | 0 | 124.1 |

Y positions match post bearing holes (at post axis).

## Bushing Clearance (bh11-cd)

| Check | Value | Status |
|---|---|---|
| Top bushing pitch | 27.2mm | 13.2mm gap between M14 bodies |
| Side bushing pitch | 27.2mm | 13.2mm gap between M14 bodies |
| Side bushing Z span | +2.1 to -11.9mm | Fully enclosed by extended walls (wall bottom at -16.9mm) |
| Rim below side bushings | 5.0mm | -16.9 - (-11.9) = 5.0mm minimum rim |
| Rim above side bushings | 2.1mm into 14mm top slab | Bushing top at Z=+2.1, contained within top slab |
| Side wall X containment | 10mm M14 pocket in 14.85mm wall | 4.85mm solid wall behind bushing (bore only) |
| Top slab thickness | 14.0mm | Exceeds 10mm bushing engagement |

## Fastener Layout

### Base Plate to Clamshell (4x M3)

| Bolt | X (mm) | Y (mm) | Notes |
|---|---|---|---|
| B1 | +12.6 | 5.0 | Right flange, near front |
| B2 | +12.6 | 140.0 | Right flange, near rear |
| B3 | -12.6 | 5.0 | Left flange, near front |
| B4 | -12.6 | 140.0 | Left flange, near rear |

- Clamshell: M3 heat-set inserts (dia 5.0mm x 4.0mm deep) in wall bottom faces
- Base plate: M3 clearance holes (dia 3.4mm) with counterbore (dia 5.5mm x 3.5mm deep) from below

Bolt X positions are centered in the outer flanges (outside the base plate lip).

## Coordinate System (bh11-cd)

Same as frame code (`frame.py`):

```
Z = +14.0   Top of clamshell (drill entry for top holes)
Z =  0.0    Pocket ceiling / frame mounting plate (Z=0 datum)
Z = -4.9    Worm/peg axis (side bushing centers)
Z = -10.0   Frame bottom
Z = -16.9   Wall bottoms / pocket opening / lip bottom
Z = -16.9   Base plate top surface
Z = -24.9   Base plate bottom surface

Y = -5.0    Clamshell front face
Y =  0.0    Frame start / pocket start (front end stop)
Y = 145.0   Frame end / pocket end (rear end stop)
Y = 150.0   Clamshell rear face

X = -20.0   Clamshell left face (peg bearing bushings enter from here)
X = -5.15   Left channel wall
X =  0.0    Frame/channel center
X = +5.15   Right channel wall
X = +20.0   Clamshell right face (worm entry bushings enter from here)
```

### Cross-Section (X-Z plane at a side bushing Y position)

```
Z=+14  +------------------------------------------+
       |              TOP SLAB (14mm)              |
Z=0    +--------+                       +----------+  <- pocket ceiling
       |        |      pocket           |          |
       |  LEFT  |    (10.3mm wide)      |  RIGHT   |
       |  WALL  |                       |  WALL    |
       | [bore] |   *bushing center     | [bore]   |  <- Z=-4.9
       |  4.05  |      frame (10mm)     |  7.05    |
Z=-10  |        |  +-----------------+  |          |  <- lip top / frame bottom
       |  5mm   |  |   BASE LIP      |  |  5mm     |
       |  rim   |  |   (6.9mm tall)   |  |  rim     |
Z=-16.9+--------+  |                 |  +----------+  <- wall bottom / lip bottom
       +-----------+                 +-------------+
       |           +-----------------+             |
       |           BASE PLATE (8mm)                |
Z=-24.9+-----------+-----------------+-------------+
```

## Drilling Workflow

### Step 1: Top and Side Holes (clamshell only, no base plate)

1. Place clamshell upside down on bench (pocket opening facing up)
2. Drop brass frame into pocket (mounting plate faces down into pocket ceiling)
3. Flip clamshell right-side up (frame held by gravity + pocket fit)
4. Drill 5x post bearing holes through top bushings (dia 4.05mm, vertical)
5. Drill 6x mounting holes through top guides (dia 3.2mm, vertical)
6. Clamp jig on side, drill 5x worm entry holes through right wall bushings (dia 7.05mm, horizontal)
7. Flip, drill 5x peg bearing holes through left wall bushings (dia 4.05mm, horizontal)

### Step 2: Bottom Holes (with base plate)

8. Bolt base plate to clamshell bottom (4x M3 bolts)
9. Flip jig upside down
10. Drill 5x wheel inlet holes through base plate guides (dia 5.1mm, vertical)

## Hardware BOM (bh11-cd)

| Item | Qty | Description |
|---|-----|---|
| M14 drill bushing, dia 4.05mm bore | 10 | Post bearing (5) + peg bearing (5) |
| M14 drill bushing, dia 7.05mm bore | 5 | Worm entry |
| M3 socket head cap screw (5.5mm head) | 4 | Base plate attachment (through 8mm plate + 6.9mm lip clearance) |
| M3 heat-set insert (dia 5.0mm x 4.0mm) | 4 | In clamshell wall bottoms |

Note: Bushing bore diameters are config-dependent. Values above are for bh11-cd. Use `--gear` to see values for other profiles.

## Manufacturing Notes

- **3D printing (FDM/SLA):** Print clamshell with top face down for best bushing pocket surface finish. Print base plate flat (lip facing up).
- **Bushing installation:** M14 bushings thread into blind pockets from the outer face. For 3D-printed jigs, tap the holes with an M14 tap, or print slightly undersized (13.8mm) for press-fit with Loctite.
- **Stepped pockets:** The blind M14 pocket seats the bushing. The smaller bore behind it guides the drill into the frame. This design keeps the full M14 body enclosed in wall material.
- **Drill bushing bore clearance:** The bushing bore should be 0.05-0.1mm larger than the drill bit for free spinning. Bushing bores listed above are the nominal drill diameters.
- **Air gap:** Between bushing bore exit and brass frame face, there is approximately 4.85mm of unsupported drill length (side walls) or 4mm (top slab). Acceptable for guided drilling and reaming.

## Handedness

This jig is for **right-hand** frames only:
- Worm entry bushings on **+X** (right) wall
- Peg bearing bushings on **-X** (left) wall

A left-hand variant would swap these sides. This can be added as a parameter in a future revision.

## Config Profiles

| Profile | CD (mm) | Worm Z (mm) | Wall Extension (mm) | Worm Bore |
|---|---|---|---|---|
| bh11-cd | 5.6 | -4.9 | 6.9 | dia 7.05mm |
| balanced | 5.9 | -5.0 | 7.0 | dia 7.05mm |

## Comparison with Cutting Jig

| Aspect | Cutting Jig | Drilling Jig |
|---|---|---|
| Purpose | Saw cuts for housings/gaps | Drill all 26 holes |
| Parts | Body + moveable end stop | Clamshell + base plate (with lip) |
| Frame hold-down | Internal plugs in cavity | Clamshell pocket + base plate lip |
| End stops | Fixed plug + moveable stop | Pocket end walls (fixed) |
| Precision features | Saw guide slots (1mm wide) | M14 stepped bushing pockets |
| Channel width | 10.3mm | 10.3mm (same) |
| Channel depth | 10.0mm | 16.9mm (extended for bushing enclosure) |
| Hardware | M3 heat-set + bolt | 15x M14 bushings + 4x M3 |
| Config | Gear-profile driven (--gear) | Gear-profile driven (--gear) |

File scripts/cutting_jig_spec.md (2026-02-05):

# Cutting Jig Specification

Cutting jig for brass frame manufacturing. Holds brass box section stock and guides saw cuts to create the frame housings and gaps.

All frame dimensions (outer size, wall thickness, housing length, pitch, etc.) are read from the JSON for the selected gear definition. Uses the same `--gear` argument and config loading as `build.py`.

## Usage

```bash
python scripts/cutting_jig.py --gear bh11-cd
python scripts/cutting_jig.py --gear balanced
python scripts/cutting_jig.py --list-gears
```

## Overview

The jig consists of two parts:
1. **Main jig body** - U-channel to hold brass, with saw guide slots (open top for saw access)
2. **Moveable end stop** - Adjustable stop with plug to secure brass

The cutting jig has an open top so the slitting saw can reach the brass. Locating plugs fit inside the brass tube's inner cavity to hold it down - one fixed at Y=0 and one on the moveable end stop at Y=frame_length.

Example values below are for the default frame parameters (10mm outer, 1.1mm wall, 5 housings, 145mm length).

## Jig Body Dimensions

| Parameter | Value | Description |
|---|---|---|
| Length | 185mm | Frame (145mm) + end stop (10mm) + travel (30mm) |
| Width | 30mm | Provides ~9.85mm thick side walls |
| Height | 18mm | Channel (10mm) + floor (8mm) |
| Channel width | 10.3mm | Frame outer (10mm) + 0.3mm clearance |
| Channel depth | 10mm | Matches frame outer dimension |
| Floor thickness | 8mm | Solid base for rigidity |
| End stop length | 10mm | Fixed stop at Y=0 |

## Brass Frame Parameters (from config)

| Parameter | Value | Source |
|---|---|---|
| Outer dimension | 10mm | `frame.box_outer` |
| Wall thickness | 1.1mm | `frame.wall_thickness` |
| Inner dimension | 7.8mm | Derived: outer - 2 x wall |
| Frame length | 145mm | Derived: `frame.total_length` |
| Housing length | 16.2mm | `frame.housing_length` |
| Tuner pitch | 27.2mm | `frame.tuner_pitch` |
| Num housings | 5 | `frame.num_housings` |

## Saw Slots

| Parameter | Value | Description |
|---|---|---|
| Slot width | 1mm | For slitting saw blade |
| Saw kerf | 1mm | Material removed by cut |
| Partial cut depth | 8.9mm | Leaves 1.1mm bottom wall (frame_outer - wall) |
| Full cut depth | 10mm | Cuts through entire brass (frame_outer) |

### Gap Computation

Gaps are computed dynamically from housing centers and housing length:

```
housing_centers = [18.1, 45.3, 72.5, 99.7, 126.9]  (from config)
half_housing = 16.2 / 2 = 8.1

gaps = [
    (0.0, 10.0),       # Before first housing
    (26.2, 37.2),       # Gap 1-2
    (53.4, 64.4),       # Gap 2-3
    (80.6, 91.6),       # Gap 3-4
    (107.8, 118.8),     # Gap 4-5
    (135.0, 145.0),     # After last housing
]
```

### Slot Positions (kerf-compensated)

Slots are offset by 0.5mm (half kerf) so the kerf falls into the gap regions, preserving housing dimensions.

| Slot Center | Kerf Start | Kerf End | Purpose | Depth |
|---|---|---|---|---|
| 9.5 | 9.0 | 10.0 | Start of H1 | 8.9mm |
| 26.7 | 26.2 | 27.2 | End of H1 | 8.9mm |
| 36.7 | 36.2 | 37.2 | Start of H2 | 8.9mm |
| 53.9 | 53.4 | 54.4 | End of H2 | 8.9mm |
| 63.9 | 63.4 | 64.4 | Start of H3 | 8.9mm |
| 81.1 | 80.6 | 81.6 | End of H3 | 8.9mm |
| 91.1 | 90.6 | 91.6 | Start of H4 | 8.9mm |
| 108.3 | 107.8 | 108.8 | End of H4 | 8.9mm |
| 118.3 | 117.8 | 118.8 | Start of H5 | 8.9mm |
| 135.5 | 135.0 | 136.0 | End of H5 | 8.9mm |
| 145.5 | 145.0 | 146.0 | Length cut | 10mm |

### Housing Sections (after cutting)

| Housing | Y Start | Y End | Length |
|---|---|---|---|
| H1 | 10.0 | 26.2 | 16.2mm |
| H2 | 37.2 | 53.4 | 16.2mm |
| H3 | 64.4 | 80.6 | 16.2mm |
| H4 | 91.6 | 107.8 | 16.2mm |
| H5 | 118.8 | 135.0 | 16.2mm |

## Fixed End Plug

Located at Y=0 on the jig, extends into brass tube to hold it down.

| Parameter | Value | Description |
|---|---|---|
| Size | 7.7mm x 7.7mm | Fits in 7.8mm inner cavity (0.05mm clearance per side) |
| Length | 3mm | Extends into brass (Y=0 to Y=3) |
| Z position | Z=-5 | Centered in brass inner cavity |

## Moveable End Stop

Sits inside the jig channel on the channel floor, with plug extending into the brass tube.

| Parameter | Value | Description |
|---|---|---|
| Body size (X) | 9.9mm | Fits in 10.3mm channel with clearance |
| Body size (Y) | 25mm | For rigidity |
| Body height | 10mm | Sits on channel floor (Z=-10) to jig top (Z=0) |
| Plug size | 7.7mm x 7.7mm | Fits in brass inner cavity (0.05mm clearance per side) |
| Plug length | 5mm | Extends into brass tube (in -Y direction) |
| Plug Z position | Z=-5 | Centered in brass inner cavity |
| Bolt hole | 3.4mm | M3 clearance, vertical through body |
| Counterbore | 5.5mm x 3.5mm | M3 socket head recess |

## Hardware

| Item | Specification | Location |
|---|---|---|
| Heat-set insert | M3, 5.0mm OD, 4.0mm deep | Jig floor at Y=157.5mm |
| Bolt | M3 socket head cap screw (5.5mm head, 3.0mm tall) | Through end stop, channel floor, into insert |
| Bolt clearance hole | 3.4mm | Through channel floor at Y=157.5mm |

## Coordinate System

- **Y=0**: Fixed end stop face (brass butts against this)
- **Y=145**: Frame end (moveable end stop position)
- **Z=0**: Jig top surface (brass sits flush)
- **Z=-10**: Channel floor (brass bottom)
- **Z=-18**: Jig bottom

## Manufacturing Notes

1. Jig is designed for 3D printing (FDM/SLA)
2. Heat-set insert installed from jig bottom
3. Partial cuts (8.9mm) leave bottom wall for rigidity during cutting
4. Full cut at Y=145.5 separates frame from waste stock

## Files

- `cutting_jig.py` - Parametric CAD script (reads gear definition JSON via --gear)
- `output/{gear}/cutting_jig_prototype.step` - Jig body geometry
- `output/{gear}/cutting_jig_end_stop.step` - End stop geometry

## Comparison: Cutting Jig vs Drilling Jig

| Feature | Cutting Jig | Drilling Jig |
|---|---|---|
| Top | Open (saw access) | Closed (clamshell with drill bushings) |
| Brass hold-down | Internal plugs (7.7mm) | Clamshell pocket + base plate lip |
| Y location | Fixed plug + moveable end stop | Pocket end walls (fixed) |
| Z location | Plugs in brass inner cavity | Lip pushes frame against ceiling |
| Channel depth | 10mm (frame height) | 16.9mm (extended for bushing enclosure) |
| Config | --gear (reads JSON) | --gear (reads JSON) |
| Hardware | M3 heat-set + bolt | 15x M14 bushings + 4x M3 |

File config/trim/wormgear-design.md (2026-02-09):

# Worm Gear Design Specification

## Overview

| Parameter | Value |
|---|---|
| Gear Ratio | 11:1 |
| Module | 0.600 mm |
| Centre Distance | 6.035 mm |
| Hand | right |
| Profile | ZA |
| Worm Type | globoid |
| Pressure Angle | 20.0° |

## Worm Gear (Driving)

| Dimension | Value |
|---|---|
| Number of Starts | 1 |
| Tip Diameter (OD) | 7.000 mm |
| Pitch Diameter | 5.800 mm |
| Root Diameter | 4.300 mm |
| Lead | 1.885 mm |
| Lead Angle | 5.91° |
| Addendum | 0.600 mm |
| Dedendum | 0.750 mm |
| Thread Thickness | 0.942 mm |

**Recommended Length:** 12.0 mm

## Worm Wheel (Driven)

| Dimension | Value |
|---|---|
| Number of Teeth | 11 |
| Tip Diameter (OD) | 8.400 mm |
| Pitch Diameter | 6.600 mm |
| Root Diameter | 5.700 mm |
| Throat Diameter | 7.200 mm |
| Min OD at Throat | 7.500 mm |
| Helix Angle | 84.09° |
| Addendum | 0.900 mm |
| Dedendum | 0.450 mm |
| Profile Shift | 0.500 |

**Recommended Face Width:** 7.2 mm

## Assembly & Performance

| Parameter | Value |
|---|---|
| Centre Distance | 6.035 mm |
| Backlash | 0.000 mm |
| Estimated Efficiency | 65.7% |
| Self-Locking | Yes |

## Manufacturing Notes

- **Profile Type:** ZA (straight flanks - standard for CNC machining)
- **Wheel Generation:** Virtual hobbing (72 steps)
- **Worm Type:** Globoid

## Validation

**Status:** ❌ Design has errors

### Errors

- **CONTACT_RATIO_TOO_LOW**: Calculated contact ratio 0.36 < 1.0. Teeth will not maintain continuous contact.
  - *Suggestion*: Increase wheel teeth count or lead angle for smoother operation. DIN 3975 §7.4 recommends contact ratio >= 1.2
- **GEOMETRIC_INTERFERENCE**: Worm and wheel geometries interfere (clearance: -0.31mm)
  - *Suggestion*: Check calculator inputs - this geometry is impossible

### Warnings

- **TEETH_VERY_LOW**: Wheel has only 11 teeth. This is unusual for worm gears.
  - *Suggestion*: Consider higher ratio or multi-start worm for better contact ratio
- **THROAT_REDUCTION_SMALL**: Throat reduction (0.17mm) is less than 0.3x module (0.18mm)
  - *Suggestion*: May result in minimal hourglass effect and reduced wheel contact
- **WHEEL_BORE_THIN_RIM**: Wheel rim is thin (1.10mm) with bore 3.5mm
  - *Suggestion*: Consider reducing bore for adequate strength

### Information

- Wheel has 11 teeth with profile shift 0.50 to avoid undercut
- Drive is self-locking (backdrive prevented)
- Throat reduction: 0.17mm (0.3x module, hourglass depth ~0.33mm)
- Globoid worm provides better contact area with wheel
- Recommended: wheel width 7.20mm, worm length 11.97mm

## Notes

- All dimensions in millimeters unless otherwise noted
- Efficiency estimate assumes steel worm on bronze wheel with lubrication
- Self-locking determination is approximate - verify with actual materials
- Throat diameter is for enveloping (throated) wheel design
- Recommended dimensions are guidelines based on contact ratio requirements

---
*Generated by Wormgear Calculator*

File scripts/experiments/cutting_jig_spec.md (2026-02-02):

# Cutting Jig Specification

Cutting jig for brass frame manufacturing. Holds brass box section stock and guides saw cuts to create the frame housings and gaps.

## Overview

The jig consists of two parts:
1. **Main jig body** - U-channel to hold brass, with saw guide slots (open top for saw access)
2. **Moveable end stop** - Adjustable stop with plug to secure brass

The cutting jig has an open top so the slitting saw can reach the brass. Locating plugs (7.7mm square) fit inside the brass tube's inner cavity to hold it down - one fixed at Y=0 and one on the moveable end stop at Y=145.

## Jig Body Dimensions

| Parameter | Value | Description |
|---|---|---|
| Length | 185mm | Frame (145mm) + end stop (10mm) + travel (30mm) |
| Width | 30mm | Provides 9.85mm thick side walls |
| Height | 18mm | Channel (10mm) + floor (8mm) |
| Channel width | 10.3mm | Brass (10mm) + 0.3mm clearance |
| Channel depth | 10mm | Brass sits flush with jig top |
| Floor thickness | 8mm | Solid base for rigidity |
| End stop length | 10mm | Fixed stop at Y=0 |

## Brass Frame Parameters

| Parameter | Value | Description |
|---|---|---|
| Outer dimension | 10mm | Square box section |
| Wall thickness | 1.1mm | Brass tube walls |
| Inner dimension | 7.8mm | 10 - 2×1.1mm |
| Frame length | 145mm | Total frame length |

## Saw Slots

| Parameter | Value | Description |
|---|---|---|
| Slot width | 1mm | For slitting saw blade |
| Saw kerf | 1mm | Material removed by cut |
| Partial cut depth | 8.9mm | Leaves 1.1mm bottom wall |
| Full cut depth | 10mm | Cuts through entire brass |

### Slot Positions (kerf-compensated)

Slots are offset by 0.5mm (half kerf) so the kerf falls into the gap regions, preserving housing dimensions.

| Slot Center | Kerf Start | Kerf End | Purpose | Depth |
|---|---|---|---|---|
| 9.5 | 9.0 | 10.0 | Start of H1 | 8.9mm |
| 26.7 | 26.2 | 27.2 | End of H1 | 8.9mm |
| 36.7 | 36.2 | 37.2 | Start of H2 | 8.9mm |
| 53.9 | 53.4 | 54.4 | End of H2 | 8.9mm |
| 63.9 | 63.4 | 64.4 | Start of H3 | 8.9mm |
| 81.1 | 80.6 | 81.6 | End of H3 | 8.9mm |
| 91.1 | 90.6 | 91.6 | Start of H4 | 8.9mm |
| 108.3 | 107.8 | 108.8 | End of H4 | 8.9mm |
| 118.3 | 117.8 | 118.8 | Start of H5 | 8.9mm |
| 135.5 | 135.0 | 136.0 | End of H5 | 8.9mm |
| 145.5 | 145.0 | 146.0 | Length cut | 10mm |

### Housing Sections (after cutting)

| Housing | Y Start | Y End | Length |
|---|---|---|---|
| H1 | 10.0 | 26.2 | 16.2mm |
| H2 | 37.2 | 53.4 | 16.2mm |
| H3 | 64.4 | 80.6 | 16.2mm |
| H4 | 91.6 | 107.8 | 16.2mm |
| H5 | 118.8 | 135.0 | 16.2mm |

## Fixed End Plug

Located at Y=0 on the jig, extends into brass tube to hold it down.

| Parameter | Value | Description |
|---|---|---|
| Size | 7.7mm × 7.7mm | Fits in 7.8mm inner cavity (0.05mm clearance per side) |
| Length | 3mm | Extends into brass (Y=0 to Y=3) |
| Z position | Z=-5 | Centered in brass inner cavity (Z=-8.9 to Z=-1.1) |

## Moveable End Stop

Sits inside the jig channel on the channel floor, with plug extending into the brass tube.

| Parameter | Value | Description |
|---|---|---|
| Body size (X) | 9.9mm | Fits in 10.3mm channel with clearance |
| Body size (Y) | 25mm | For rigidity |
| Body height | 10mm | Sits on channel floor (Z=-10) to jig top (Z=0) |
| Plug size | 7.7mm × 7.7mm | Fits in brass inner cavity (0.05mm clearance per side) |
| Plug length | 5mm | Extends into brass tube (in -Y direction) |
| Plug Z position | Z=-5 | Centered in brass inner cavity |
| Bolt hole | 5.5mm | M5 clearance, vertical through body |

## Hardware

| Item | Specification | Location |
|---|---|---|
| Heat-set insert | M5, 6.4mm OD | Jig floor at Y=157.5mm |
| Bolt | M5 | Through end stop, channel floor, into insert |
| Bolt clearance hole | 5.5mm | Through channel floor at Y=157.5mm |

## Coordinate System

- **Y=0**: Fixed end stop face (brass butts against this)
- **Y=145**: Frame end (moveable end stop position)
- **Z=0**: Jig top surface (brass sits flush)
- **Z=-10**: Channel floor (brass bottom)
- **Z=-18**: Jig bottom

## Manufacturing Notes

1. Jig is designed for 3D printing (FDM/SLA)
2. Heat-set insert installed from jig bottom
3. Partial cuts (8.9mm) leave bottom wall for rigidity during cutting
4. Full cut at Y=145.5 separates frame from waste stock

## Files

- `cutting_jig.py` - Parametric CAD script
- `output/cutting_jig_prototype.step` - Jig body geometry
- `output/cutting_jig_end_stop.step` - End stop geometry

## Comparison: Cutting Jig vs Drilling Jig

| Feature | Cutting Jig | Drilling Jig |
|---|---|---|
| Top | Open (saw access) | Lid (drill bushings) |
| Brass hold-down | Internal plugs (7.7mm) | Lid clamps from above |
| Y location | Fixed plug + moveable end stop | End stops |
| Z location | Plugs in brass inner cavity | Lid pressure |
| Lid thickness | N/A | 10mm (drill bushing depth) |

### Reusable Parameters for Drilling Jig
- Channel width: 10.3mm
- Channel depth: 10mm
- Floor thickness: 8mm
- Side wall thickness: ~10mm
- Heat-set inserts: M5, 6.4mm OD

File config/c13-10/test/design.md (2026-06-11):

# Worm Gear Design Specification

## Overview

| Parameter | Value |
|---|---|
| Gear Ratio | 13:1 |
| Module | 0.500 mm |
| Centre Distance | 6.250 mm |
| Hand | right |
| Profile | ZI |
| Worm Type | cylindrical |
| Pressure Angle | 20.0° |

## Worm Gear (Driving)

| Dimension | Value |
|---|---|
| Number of Starts | 1 |
| Tip Diameter (OD) | 7.000 mm |
| Pitch Diameter | 6.000 mm |
| Root Diameter | 4.750 mm |
| Lead | 1.571 mm |
| Lead Angle | 4.76° |
| Addendum | 0.500 mm |
| Dedendum | 0.625 mm |
| Thread Thickness | 0.785 mm |

**Recommended Length:** 7.7 mm

## Worm Wheel (Driven)

| Dimension | Value |
|---|---|
| Number of Teeth | 13 |
| Tip Diameter (OD) | 7.600 mm |
| Pitch Diameter | 6.500 mm |
| Root Diameter | 5.550 mm |
| Addendum | 0.550 mm |
| Dedendum | 0.475 mm |
| Profile Shift | 0.300 |

**Recommended Face Width:** 7.7 mm

## Assembly & Performance

| Parameter | Value |
|---|---|
| Centre Distance | 6.250 mm |
| Backlash | 0.000 mm |
| Self-Locking | No |

## Manufacturing Notes

- **Profile Type:** ZI
- **Wheel Generation:** Helical approximation
- **Worm Type:** Cylindrical
## Notes

- All dimensions in millimeters unless otherwise noted
- Efficiency estimate assumes steel worm on bronze wheel with lubrication
- Self-locking determination is approximate - verify with actual materials
- Throat diameter is for enveloping (throated) wheel design
- Recommended dimensions are guidelines based on contact ratio requirements

---
*Generated by Wormgear Calculator*

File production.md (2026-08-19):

# Production Build Guide

This document records exactly how to generate the CNC files for the 5-gang tuning machine assembly.

## Build Command

```bash
python scripts/build.py --hand both --gear c13-10 -n 5 --label-frames no
```

| Flag | Value | Reason |
|---|---|---|
| `--hand both` | RH + LH | Generate both variants in one run |
| `--gear c13-10` | c13-10 | Production gear profile (M0.5, 13-tooth, cylindrical worm) |
| `-n 5` | 5 housings | Full 5-gang assembly, 145mm frame |
| `--label-frames no` | No label etch | Omit L/R etch; with labels on, RH and RH frames differ in size |

Output goes to `output/` by default (STEP + STL for each component).

## Output Files

| File | Description |
|---|---|
| `frame_rh_5gang.step` | Right-hand frame |
| `frame_lh_5gang.step` | Left-hand frame (mirror of RH — must be same file size) |
| `peg_head_rh.step` | Right-hand peg head with worm |
| `peg_head_lh.step` | Left-hand peg head (mirrored, left-hand worm helix) |
| `string_post.step` | String post (symmetric — one file for both hands) |
| `wheel_rh.step` | Right-hand worm wheel |
| `wheel_lh.step` | Left-hand worm wheel (mirrored) |

## Validation Before Sending

Run `scripts/check_production.py` to confirm the new build contains exactly the expected changes:

```bash
# After building to output/:
python scripts/check_production.py

# Or against a specific directory:
python scripts/check_production.py --baseline sent/ptype/ --new sent/fixedv2/
```

The script checks each component against the `sent/ptype/` baseline:

| Component | Check |
|---|---|
| frame LH + RH | Identical file sizes (labels off), mounting holes ≈ 3.2mm, volume/bbox unchanged |
| string_post | String hole ≈ 1.7mm, chamfer faces present, volume/bbox unchanged |
| peg_head LH + RH | Pip stalk ≥ 1.4mm (reinforced), volume/bbox unchanged |

Expected output: `RESULT: PASS — all checks passed`

Interactively, `WARN` (a check flagged something) and `SKIP` (a component's file
was missing, so nothing was compared) both exit 0 — they are advisory. Pass
`--strict` to exit non-zero on either, which is how the release workflow gates:
a labelled-frame build surfaces as `WARN`, and a build that emitted no files
surfaces as `SKIP`, and neither may ship.

## Gear Profile: c13-10

Located in `config/c13-10/`. Key parameters:

| Parameter | Value |
|---|---|
| Gear module | M0.5 |
| Worm starts | 1 |
| Wheel teeth | 13 |
| Ratio | 13:1 |
| Pressure angle | 20° |
| Centre distance | 6.25mm |
| Worm type | Cylindrical (ZI) |
| Worm tip diameter | 7.0mm |
| Worm root diameter | 4.75mm |
| Wheel tip diameter | 7.6mm |
| Wheel bore | 3.5mm (DD cut) |
| Peg shaft diameter | 4.5mm (overridden in `tuner_config.json`) |
| Frame wall thickness | 1.0mm (overridden in `tuner_config.json`) |

## What Changed Since First Prototype Send (sent/ptype, Feb 2026)

| Change | Commit | Effect on files |
|---|---|---|
| Pip stalk reinforcement 1.0mm → 1.5mm | PR #76 | `peg_head_*.step` slightly larger |
| String hole 1.5mm → 1.7mm + chamfers | PR (Mar 2026) | `string_post.step` larger |
| Mounting holes 3.0mm → 3.2mm | PR (Mar 2026) | `frame_*.step` slightly changed |

## Cutting a Release

`.github/workflows/release.yml` packages the production geometry and the drawing
suite into a GitHub release. Push a version tag to run it:

```bash
git tag -a v0.2.1 -m "Production pack"
git push origin v0.2.1
```

The workflow runs the test suite, then in parallel:

| Job | Does |
|-----|---|
| `build` | Production build (STEP + STL), asserts every expected file exists, then `check_production.py --strict` against the `sent/ptype` baseline |
| `drawings` | The 5 A3 sheets + `tuner_drawings.pdf` + `drawings_dxf_svg.zip` |
| `release` | Flattens both artifact sets and creates the release (24 assets) |

The release is created as a **draft** so the notes can be reviewed first. Publish it with:

```bash
gh release edit v0.2.1 --draft=false
```

Boilerplate notes live in `.github/release-notes.md`; `--generate-notes` appends
the commit/PR list since the previous tag. To publish automatically instead, drop
the `--draft` flag from the workflow's final step.

`workflow_dispatch` runs the same build and validation from any branch but skips
the release step — use it to dry-run the asset pack before tagging.

The workflow warns (but does not fail) if the tag does not match `version` in
`pyproject.toml`, so bump that in the release commit.

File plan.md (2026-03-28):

# Plan: Add Decorative Engraving to Frame Top Plate

## What
Add a simplified rope-border engraving around all 4 edges of the frame's top surface (Z=0). Based on the original vintage tuner: two thin border lines with a diagonal hatching pattern between them, ~1mm inset from the frame edge.

## Design

### Engraving geometry
- **Inset from edge:** 1.0mm (outer border line center)
- **Border band width:** ~1.5mm (outer line at 1.0mm, inner line at 2.5mm from edge)
- **Groove depth:** 0.2mm (shallow engraving into Z=0 surface)
- **Groove width:** ~0.2mm (V-groove or thin rectangular cut)
- **Rope pattern:** Diagonal hatching lines between the two borders at ~45°, spaced ~1mm apart — reads as a simplified rope/twist at this scale

### Frame top surface coordinates
- X: -5.0 to +5.0 (10mm wide)
- Y: 0 to 145.0 (for 5-gang)
- Z=0 is the top surface

### Engraving path (rectangular loop)
- Outer border: rectangle at X=[-4.0, 4.0], Y=[1.0, 144.0]
- Inner border: rectangle at X=[-2.5, 2.5], Y=[2.5, 142.5]
- Diagonal fills between borders on each of the 4 sides

### Obstacles to avoid
- Mounting holes (6 positions along centerline) — engraving goes around them since border is along the edge, not the center. No conflict.
- Post holes — also on centerline. No conflict with edge border.

## Implementation

### Step 1: Add `EngravingParams` dataclass to `parameters.py`
New frozen dataclass with:
- `inset: float = 1.0` — distance from frame edge to outer border
- `band_width: float = 1.5` — width of decorative band
- `depth: float = 0.2` — groove depth
- `groove_width: float = 0.2` — groove line width
- `hatch_spacing: float = 1.0` — diagonal line spacing
- `enabled: bool = True` — toggle engraving on/off

Add `engraving: EngravingParams` field to `FrameParams`.

### Step 2: Add `_create_engraving()` function in `frame.py`
New private function that:
1. Creates two rectangular groove loops (outer and inner borders) as thin Box cuts
2. Creates diagonal hatch lines between the borders on each of the 4 sides
3. Returns the combined engraving solid to subtract from the frame

For each border line (outer and inner):
- 4 thin Box cuts forming a rectangle (top, bottom, left, right edges)

For diagonal hatching on each side:
- Generate angled line segments between the two borders
- Each line is a thin rotated Box or extruded path
- ~45° angle, spaced by `hatch_spacing`

### Step 3: Integrate into `create_frame()`
- Call `_create_engraving()` after the text label (line ~230)
- Subtract from frame: `frame = frame - engraving`
- Before `check_shape_quality()`

### Step 4: Test and visualize
- Run `python scripts/viz.py -n 1 --gear c13` to verify single-housing appearance
- Run existing tests to confirm no regressions
- Export STEP and verify bounding box unchanged (10×145×10)

## Files modified
1. `src/gib_tuners/config/parameters.py` — add `EngravingParams` dataclass
2. `src/gib_tuners/components/frame.py` — add `_create_engraving()` and call it

## Risk
- Many small boolean cuts could slow OCCT or produce NME edges. If so, we can reduce hatch density or simplify further.
- Diagonal hatches near corners need care to avoid overlapping with the border lines.

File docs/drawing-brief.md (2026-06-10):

# Technical Drawing Session Brief

## What This Is

A session brief for producing fabrication-ready engineering drawings for the **gib-tuners-mk2** parametric CAD project. Use this to resume work after a context reset.

---

## Project: gib-tuners-mk2

Parametric build123d project for historic guitar tuner restoration. Generates 5-gang tuning machine assemblies (RH and LH variants).

**Production gear profile:** `c13-10` — cylindrical worm, M0.5 module, 13-tooth wheel, 20° PA.

**Production build command:**
```bash
python scripts/build.py --hand both --gear c13-10 -n 5 --label-frames no
```

**Key source files:**
- `src/gib_tuners/config/parameters.py` — all component dataclasses
- `src/gib_tuners/config/defaults.py` — `create_default_config()`, `resolve_gear_config()`
- `src/gib_tuners/components/frame.py` — `create_frame(config, label=False)`
- `src/gib_tuners/components/string_post.py` — `create_string_post(config)`
- `src/gib_tuners/components/wheel.py` — `load_wheel(step_path)`
- `src/gib_tuners/components/peg_head.py` — `create_peg_head(config, include_worm=False)`
- `config/c13-10/worm_gear.json` — gear parameters (source of truth for gear dims)

---

## Drawing Goal

One A4 engineering drawing per component, plus one general arrangement (GA). Outputs: SVG (review) and DXF (fabrication).

**Sheets planned:**
| Sheet | Component | DWG# |
|---|---|---|
| GIB-TUN-FR-RH | Frame — 5-gang RH — A3 2:1 | scripts/frame_drawing.py |
| GIB-TUN-SP | String Post — A3 10:1 | scripts/string_post_drawing.py |
| GIB-TUN-WW-RH | Worm Wheel — A3 10:1 | scripts/wheel_drawing.py |
| GIB-TUN-PH-RH | Peg Head (RH) — A3 5:1 | scripts/peg_head_drawing.py |
| GIB-TUN-GA-RH | General Arrangement (1 station) — A3 5:1 | scripts/assembly_drawing.py |
| PDF | All sheets combined | scripts/drawings/make_pdf.py |

**Output directory:** `drawings/`

---

## Drawing Conventions

- A4 landscape (297 × 210 mm), margin 10 mm
- ISO, **third-angle projection** (top above front, right-side to the right)
- Metric, ISO 2768-m general tolerance in title block
- Scale: appropriate per component (frame 1:1, small parts 3:1 or 5:1)
- Black part geometry, blue annotations (two SVG layers)

**View layout (third-angle):**
```
      [TOP VIEW]      [ISO]
[FRONT VIEW] [END VIEW]
```

---

## Architecture: Build from Source, Not STEP Files

**CRITICAL DECISION:** Drawings must be generated from live build123d geometry (`create_frame(cfg)`, `create_string_post(cfg)`, etc.), NOT from exported STEP files. This ensures dimensions stay in sync when parameters change.

Each drawing script follows this pattern:
```python
from gib_tuners.config.defaults import create_default_config, resolve_gear_config
from gib_tuners.config.parameters import Hand
from gib_tuners.components.frame import create_frame

gear_paths = resolve_gear_config("c13-10")
cfg = create_default_config(
    gear_json_path=gear_paths.json_path,
    config_dir=gear_paths.config_dir,
    hand=Hand.RIGHT,
)
part = create_frame(cfg, label=False)
# All dimension values come from cfg, never hard-coded
```

Run scripts with `uv run python scripts/drawings/frame.py`.

---

## MCP Server Setup

The `build123d-mcp` server is configured in `.mcp.json` (project root):

```json
{
  "mcpServers": {
    "build123d-mcp": {
      "command": "uv",
      "args": [
        "tool", "run", "--upgrade", "--python", "3.12",
        "build123d-mcp",
        "--allow-imports", "gib_tuners,dacite"
      ],
      "env": {
        "PYTHONPATH": "/app/workspaces/pzfreo/gib-tuners-mk2/src"
      }
    }
  }
}
```

**After restarting Claude Code**, verify with:
```python
# In MCP execute():
from gib_tuners.config.defaults import create_default_config, resolve_gear_config
from gib_tuners.config.parameters import Hand
from gib_tuners.components.frame import create_frame
gear_paths = resolve_gear_config("c13-10")
cfg = create_default_config(gear_json_path=gear_paths.json_path, config_dir=gear_paths.config_dir)
part = create_frame(cfg, label=False)
show(part, "frame")
print("gib_tuners import OK")
```

---

## Coordinate Systems (DO NOT GUESS — CHECK WITH view_axes())

Always call `view_axes()` before `project_to_viewport()`. Confirmed mappings for each component:

### Frame (bbox: X=10, Y=145, Z=10)
- Z=0: mounting plate (top), Z=-10: bottom
- Y=0: one end, Y=145: other end
- **Front** (from -X, up=Z): `world_Y → page_X ×-1`, `world_Z → page_Y ×+1`
- **Top/plan** (from +Z, up=+X): `world_Y → page_X ×-1`, `world_X → page_Y ×+1`
- **End** (from +Y, up=Z): `world_X → page_X ×-1`, `world_Z → page_Y ×+1`

### String Post (bbox: X=7.5, Y=7.5, Z=14.8)
- Z=0: bottom of DD section, Z=14.8: top of cap
- Shaft axis = Z (vertical in drawing)
- **Front** (from -Y, up=Z): `world_X → page_X ×+1`, `world_Z → page_Y ×+1`

### Peg Head — IMPORTANT: ROTATE FIRST
`create_peg_head()` returns shaft along Z. Apply `part.rotate(Axis.Y, 90)` before projecting.
After rotation: shaft along +X, head at -X.
- **Front** (from -Y, up=Z): `world_X → page_X ×+1`, `world_Z → page_Y ×+1`
- **End** (from -X, up=Z): `world_Y → page_X ×+1`, `world_Z → page_Y ×+1`

---

## Key Dimensions (for reference — always read from cfg)

| Parameter | Value | Source |
|---|---|---|
| Frame outer | 10.0 mm | `cfg.frame.box_outer` |
| Wall thickness | 1.0 mm | `cfg.frame.wall_thickness` (c13-10, via tuner_config.json) |
| Total length (5-gang) | 145.0 mm | `cfg.frame.total_length` |
| Housing length | 16.2 mm | `cfg.frame.housing_length` |
| End length | 10.0 mm | `cfg.frame.end_length` |
| Tuner pitch | 27.2 mm | `cfg.frame.tuner_pitch` |
| Post bearing hole | 5.05 mm | `cfg.frame.post_bearing_hole` |
| Worm entry hole | ~7.2 mm | `cfg.frame.worm_entry_hole` |
| Peg bearing hole | 4.55 mm | `cfg.frame.peg_bearing_hole` |
| Mounting hole | 3.2 mm | `cfg.frame.mounting_hole` |
| Worm Z (c13-10) | -5.0 mm | `calculate_worm_z(cfg)` (centred) |
| Cap diameter (post) | 7.5 mm | `cfg.string_post.cap_diameter` |
| Post diameter | 6.0 mm | `cfg.string_post.post_diameter` |
| Wheel tip diameter | 7.6 mm | `cfg.gear.wheel.tip_diameter` |
| Wheel bore | 3.5 mm | `cfg.gear.wheel.bore.diameter` |
| Wheel face width | 7.7 mm | `cfg.gear.wheel.face_width` |
| Peg head ring OD | 12.5 mm | `cfg.peg_head.ring_od` |
| Peg head cap OD | 8.5 mm | `cfg.peg_head.cap_diameter` |
| Peg head shoulder | 7.0 mm | `cfg.peg_head.shoulder_diameter` |
| Gear module | M0.5 | `cfg.gear.worm.module` |
| Gear teeth | 13 | `cfg.gear.wheel.num_teeth` |

---

## What Works / What Doesn't (lessons learned)

### ✓ What works
- `view_axes()` — essential, use it before every `project_to_viewport()`
- `render_drawing(svg_path, save_to='/tmp/foo.png')` — fast preview
- `Dimension(p1, p2, side, distance, draft, label)` — clean when part is large enough
- `place_dims(specs, draft)` — auto-tiers stacked dims
- `Leader(tip, elbow, label, draft)` — keep to ≤3 per sheet
- `TechnicalDrawing()` — good title block but watch subtitle length (overflows silently)
- `lint_drawing(items)` — catches label-vs-measured errors and leader-through-text

### ✗ Known problems / workarounds

**Scale:** No native scale support. If you scale geometry with `part.scale(N)` before projecting, every Dimension fails lint's label-vs-measured check. **Workaround:** Accept lint warnings for scaled drawings, or wait for issue #147 fix.

**`set_page()` / `annotate()` not in package:** These are MCP session builtins only. Standalone scripts can't use page-bounds checking. **Workaround:** Visual check via `render_drawing()`. Issue #148 filed.

**lint_drawing() false positives for stacked dims:** Checks full bounding boxes including witness lines — flags valid stacked dimensions as overlapping. **Workaround:** Ignore `annotation_overlap` warnings that come from `place_dims()` output; fix real overlaps (leader-through-label, actual label collisions). Issue #149 filed.

**Small parts are tiny at 1:1:** String post (7.5 mm), wheel (7.6 mm) are unreadably small on A4. Need scale. Issue #147 covers this.

**`gib_tuners` not on MCP allowlist by default:** Now fixed in `.mcp.json` — but requires Claude Code restart to take effect.

---

## Issues Filed on build123d-mcp

| # | Title | Status |
|---|---|---|
| [#147](https://github.com/pzfreo/build123d-mcp/issues/147) | Native drawing scale (N:1) support | Open |
| [#148](https://github.com/pzfreo/build123d-mcp/issues/148) | `set_page()` / `annotate()` as package exports | Open |
| [#149](https://github.com/pzfreo/build123d-mcp/issues/149) | lint false positives from witness-line bboxes | Open |
| [#150](https://github.com/pzfreo/build123d-mcp/issues/150) | Project-local packages via PYTHONPATH + allowlist | Open |
| [#151](https://github.com/pzfreo/build123d-mcp/issues/151) | TechnicalDrawing subtitle overflow not caught by lint | Open |

---

## Current State (branch: technical-diagrams)

- Old drawing attempts removed: `scripts/drawings.py`, `scripts/freecad_drawing.py`, `src/gib_tuners/export/drawing_export.py`
- New scripts in `scripts/drawings/`: `frame.py`, `string_post.py`, `wheel.py`, `peg_head.py`
- `build123d-drafting-helpers>=0.2.0` added to `pyproject.toml` dependencies
- SVG outputs in `drawings/` (rough first pass, needs isometrics + scale + lint cleanup)
- `assembly_ga.py` and `make_pdf.py` not yet written

---

## Next Steps (in order)

1. **Restart Claude Code** so the MCP server picks up the new `.mcp.json` (gib_tuners allowlist)
2. **Verify** `gib_tuners` is importable in MCP `execute()` (test snippet above)
3. **Add isometric view** to every sheet — camera at approx `(1, -1, 0.5)` normalised, `up=(0, 0, 1)`, placed top-right of the sheet
4. **Handle scale** — decide approach once issue #147 is addressed, or use `part.scale(N)` and accept lint warnings with a `[N:1]` note in the title
5. **Write `assembly_ga.py`** — 1-gang GA showing all four components in position, centre distance annotated
6. **Write `make_pdf.py`** — assemble all SVGs into a single PDF using `pypdf` or `reportlab`
7. **Commit** everything on `technical-diagrams` branch, open PR

---

## Preferred Workflow (once gib_tuners is importable in MCP)

```
execute() in MCP session:
  → import gib_tuners component
  → build geometry
  → scale if needed (part.scale(N))
  → project_to_viewport() for each view
  → Dimension / Leader annotations
  → set_page() + annotate() (session builtins)
  → lint_drawing() — full check including page bounds
  → export() SVG + DXF

Then: render_drawing(svg_path, save_to='/tmp/preview.png') to eyeball
Then: transcribe to standalone script in scripts/drawings/
```

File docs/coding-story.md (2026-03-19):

# Building the Gib Tuners: A Coding Story

This project set out to create a fully parametric CAD model of a 5-gang worm-drive tuning machine for historic guitar restoration, written entirely in Python using build123d. The goal was to produce manufacturing-ready STEP files for brass components that replicate the look and feel of original 19th-century tuners while being practical to machine in small batches. Almost the entire codebase — 69 merged PRs over two weeks — was written with Claude Code as a coding partner.

## Getting the geometry right

The first challenge was simply getting parts to fit inside a 10mm brass box section. The frame, string post, worm wheel, and peg head all occupy the same tiny cavity, and every dimension is coupled. Change the gear module and the center distance shifts, which moves the worm entry hole, which changes how much wall is left for the M2 tap hole. Early on, we bounced between 10mm and 10.35mm outer dimensions and between 1.0mm and 1.1mm wall thickness before discovering that 1.1mm was non-negotiable — it's what the brass stock actually measures.

Positioning the worm-wheel mesh was fiddly. The worm sits perpendicular to the frame, spanning the full cavity width, while the wheel rotates on the string post axis below it. Getting the center distance, the mesh rotation angle (14.75°), and the Z-alignment right took several iterations with interference checking to validate each step.

## Fighting OCCT's boolean engine

The hardest technical problem was boolean fusion of the peg head. This component is built by unioning four overlapping solids: a reference STEP peg head, a core shaft, a bearing shaft, and a worm STEP imported from an external gear calculator. OCCT's boolean kernel produced degenerate zero-volume artifacts (returning `ShapeList` instead of `Solid`), phantom 734mm³ interference from disjoint compounds, and 29-nanometre non-manifold edges at worm thread termination points. We tried every OCCT healing tool available — `ShapeFix_Shape`, `ShapeFix_Solid`, `BRepBuilderAPI_Sewing`, `ShapeUpgrade_UnifySameDomain`, `BRepAlgoAPI_Defeaturing`, fuzzy booleans, STEP round-trips — and none removed the NME edges without destroying the solid. The solution was pragmatic: filter zero-volume artifacts after fusion, apply `ShapeFix_Shape` for topology repair, and classify NME edges by arc length so sub-micron artifacts are logged silently rather than triggering false warnings.

A subtler boolean bug appeared later: when the core shaft radius exactly equalled the worm root radius (2.375mm), coincident surfaces caused OCCT to consume the worm teeth during fusion, losing 70mm³ of volume. A 0.1mm undercut on the core shaft fixed it.

## The gear profile journey

The gear profile went through a full circle. We started with M0.5/13:1, switched to M0.6/10:1 for a stronger peg shaft, explored globoid worms for better meshing, then came back to cylindrical M0.5/13:1 (the c13 profile) once we found that profile shift +0.3 gave strong enough tooth roots while keeping manufacturing simple. Along the way we generated eleven distinct gear configurations, each with its own STEP files, geometry analysis, and parameter JSON. The external gear calculator tool drove the gear geometry; the CAD code had to adapt to whatever it produced.

## From CAD to workshop

Once the virtual assembly worked, the focus shifted to manufacturing tooling. We designed parametric 3D-printed jigs — a cutting jig for sawing the brass stock to length, and a two-part clamshell drilling jig for all 26 holes in a 5-gang frame. Real-world printing immediately exposed issues: M5 hardware was too large, heat-set inserts fell out of nominal-sized pockets (needed 0.3mm interference), and the frame length tolerance required a clamping plug with 4mm of travel. Each fix came from testing a physical print and feeding the result back into the parametric model.

## What worked about the process

Working with an AI coding partner on a CAD project was surprisingly effective for the exploratory, iterative style this kind of engineering demands. The parametric architecture — frozen dataclasses, derived dimensions, config-driven gear profiles — made it safe to change one parameter and have everything propagate. Interference checking after every build caught problems that would otherwise only surface at the bench. And the ability to spin up new gear profiles, jig variants, or export formats in single sessions kept the design space open rather than locking in too early.

The main friction points were spatial reasoning (positioning components in 3D required explicit coordinate checks rather than trusting intuition) and OCCT's boolean behaviour (which is genuinely unpredictable with complex imported geometry). Both were managed by building incrementally — one component at a time, one housing before five — and never moving forward until the current step was visually verified.

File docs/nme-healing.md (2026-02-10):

# Non-Manifold Edge (NME) Healing

## What are Non-Manifold Edges?

A non-manifold edge is an edge shared by more than two faces. In a valid solid (manifold), every edge is shared by exactly two faces. NMEs make geometry ambiguous for CNC toolpath generation and can cause issues in downstream CAD/CAM software.

## Why NMEs occur in this project

The peg head component is built by boolean-fusing four overlapping solids:

1. Peg head reference STEP (ring, pip, cap, shoulder)
2. Core shaft cylinder
3. Bearing shaft cylinder
4. Worm reference STEP

These parts have overlapping boundaries by design (0.1mm overlap for reliable boolean fusion). OCCT's boolean engine produces 4 non-manifold edges at the worm thread termination points (where the helical thread surface intersects the flat end-faces of the worm). These are ~29nm arc-length circular arcs — numerical noise from the boolean kernel, far below any manufacturing tolerance.

## The healing pipeline

### _heal_shape() in peg_head.py

The `_heal_shape()` function applies two operations:

1. **ShapeList consolidation** — filters out zero-volume degenerate artifacts that OCCT's boolean engine produces alongside the main solid
2. **ShapeFix_Shape** — repairs topology issues (shell orientation, wire defects)

```python
from OCP.ShapeFix import ShapeFix_Shape

fixer = ShapeFix_Shape(shape)
fixer.SetPrecision(0.01)
fixer.Perform()
healed = fixer.Shape()
```

### check_shape_quality() in validation.py

The quality checker distinguishes between:
- **Significant NMEs** (>1 micron arc length) — raises a warning, indicates a real topology problem
- **Degenerate NMEs** (sub-micron arc length) — logged as info only, harmless boolean kernel artifacts

This prevents false alarms from the ~29nm thread termination artifacts while still catching genuine problems.

## Where healing is applied

In `src/gib_tuners/components/peg_head.py`, `_heal_shape()` is called at two points:

1. **After the 4-part fusion** (peg head + core shaft + bearing shaft + worm) — consolidates ShapeList result and fixes topology
2. **After the tap hole subtraction** — handles any artifacts from the boolean cut

## Known residual NMEs

4 degenerate NME edges (~29nm arc length each) persist after healing. These are at:
- Z=0.65mm (worm thread start) — 2 edges
- Z=6.95mm (worm thread end) — 2 edges

These are intrinsic to OCCT's boolean kernel when fusing worm thread geometry and cannot be removed by any standard OCCT healing approach (ShapeFix_Shape, ShapeFix_Solid, BRepBuilderAPI_Sewing, ShapeUpgrade_UnifySameDomain, BRepAlgoAPI_Defeaturing, fuzzy boolean) without destroying solid geometry.

At 29nm, these are:
- 3,400x smaller than the tightest manufacturing tolerance (0.1mm)
- Invisible to any CNC toolpath generator
- Correctly handled by the STL export pipeline (pymeshfix)

## How to verify

Build the peg head and check that no NME **warning** appears:

```bash
python scripts/build.py --gear c13 --hand right --format step --components peg_head
```

The build output should not show "non-manifold edges detected" warnings. The 4 degenerate NMEs are logged silently in the ShapeQualityResult issues list but do not trigger warnings.

```python
from gib_tuners.utils.validation import check_shape_quality

result = check_shape_quality(peg_head_part, "peg_head")
# result.non_manifold_edges == 4 (degenerate, sub-micron)
# No warning is emitted for degenerate edges
```

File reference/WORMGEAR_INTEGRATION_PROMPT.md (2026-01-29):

# Prompt for Worm Gear Project: Add Mesh Alignment Analysis

## Context

When generating worm and wheel STEP files, the wheel teeth have an arbitrary starting orientation. For proper meshing visualization, the wheel needs to be rotated to align teeth with worm thread valleys.

## Feature Request

Add mesh alignment analysis to the worm gear generator that:

1. **Calculates optimal wheel rotation** to minimize interference with the worm
2. **Reports interference volume** at the optimal rotation
3. **Outputs axis markers** for visualization (thin cylinders showing true axis positions)
4. **Includes mesh data in output** (rotation angle, interference volume, tolerance status)

## Algorithm

The mesh alignment algorithm works by:

1. Testing wheel rotations from 0° to one tooth pitch (360°/num_teeth) in 1° steps
2. At each angle, computing the boolean intersection volume between wheel and worm
3. Refining around the minimum with 0.1° steps
4. Returning the angle with minimum (ideally zero) interference

Key insight: The mesh pattern repeats every tooth pitch, so we only need to search within one tooth's angular span.

## Implementation

Here's the core mesh alignment code to integrate:

```python
from dataclasses import dataclass
from build123d import Axis, Location, Part, Cylinder, Align

@dataclass
class MeshAnalysisResult:
    optimal_rotation_deg: float
    interference_volume_mm3: float
    within_tolerance: bool
    tooth_pitch_deg: float
    message: str

def calculate_mesh_rotation(
    wheel: Part,
    worm: Part,
    num_teeth: int,
    coarse_step: float = 1.0,
    fine_step: float = 0.1,
) -> float:
    """Find wheel rotation that minimizes collision with worm.

    Args:
        wheel: Wheel Part centered at origin with axis along Z
        worm: Worm Part positioned at correct center distance (axis along X)
        num_teeth: Number of teeth on the wheel
        coarse_step: Step size for initial search
        fine_step: Step size for refinement

    Returns:
        Optimal rotation angle in degrees
    """
    tooth_angle = 360.0 / num_teeth
    best_rotation = 0.0
    min_interference = float("inf")

    # Coarse search
    for angle in [i * coarse_step for i in range(int(tooth_angle / coarse_step) + 1)]:
        rotated_wheel = wheel.rotate(Axis.Z, angle)
        try:
            intersection = rotated_wheel & worm
            interference = intersection.volume if hasattr(intersection, "volume") else 0
        except Exception:
            interference = 0
        if interference < min_interference:
            min_interference = interference
            best_rotation = angle

    # Fine search around best angle
    fine_range = int(coarse_step / fine_step)
    for d in range(-fine_range, fine_range + 1):
        angle = (best_rotation + d * fine_step) % tooth_angle
        rotated_wheel = wheel.rotate(Axis.Z, angle)
        try:
            intersection = rotated_wheel & worm
            interference = intersection.volume if hasattr(intersection, "volume") else 0
        except Exception:
            interference = 0
        if interference < min_interference:
            min_interference = interference
            best_rotation = angle

    return best_rotation

def find_optimal_mesh_rotation(
    wheel: Part,
    worm: Part,
    center_distance: float,
    num_teeth: int,
    backlash_tolerance_mm3: float = 1.0,
) -> MeshAnalysisResult:
    """Find optimal wheel rotation and analyze mesh quality.

    Args:
        wheel: Wheel Part centered at origin with axis along Z
        worm: Worm Part centered at origin with axis along Z
        center_distance: Distance between axes in mm
        num_teeth: Number of wheel teeth
        backlash_tolerance_mm3: Maximum acceptable interference

    Returns:
        MeshAnalysisResult with rotation and interference data
    """
    tooth_pitch = 360.0 / num_teeth

    # Position worm: rotate -90° Y (axis along X), offset by center_distance in Y
    worm_positioned = worm.rotate(Axis.Y, -90)
    worm_positioned = worm_positioned.locate(Location((0, center_distance, 0)))

    # Calculate optimal rotation
    optimal_rotation = calculate_mesh_rotation(wheel, worm_positioned, num_teeth)

    # Check interference at optimal rotation
    wheel_rotated = wheel.rotate(Axis.Z, optimal_rotation)
    try:
        intersection = wheel_rotated & worm_positioned
        interference = intersection.volume if hasattr(intersection, "volume") else 0.0
    except Exception:
        interference = 0.0

    within_tolerance = interference <= backlash_tolerance_mm3

    if interference == 0.0:
        message = "Perfect mesh - no interference"
    elif within_tolerance:
        message = f"Good mesh - {interference:.4f}mm³ interference"
    else:
        message = f"Warning - {interference:.4f}mm³ exceeds tolerance"

    return MeshAnalysisResult(
        optimal_rotation_deg=optimal_rotation,
        interference_volume_mm3=interference,
        within_tolerance=within_tolerance,
        tooth_pitch_deg=tooth_pitch,
        message=message,
    )

def create_axis_markers(center_distance: float, length: float = 10.0) -> dict[str, Part]:
    """Create axis marker cylinders for visualization.

    These show the true axis positions (important because gear bounding
    boxes shift with rotation due to asymmetric tooth positions).
    """
    wheel_axis = Cylinder(radius=0.2, height=length,
                          align=(Align.CENTER, Align.CENTER, Align.CENTER))

    worm_axis = Cylinder(radius=0.2, height=length,
                         align=(Align.CENTER, Align.CENTER, Align.CENTER))
    worm_axis = worm_axis.rotate(Axis.Y, 90)
    worm_axis = worm_axis.locate(Location((0, center_distance, 0)))

    return {"wheel_axis": wheel_axis, "worm_axis": worm_axis}
```

## Output Format

When generating gears, include mesh alignment data in the output:

```json
{
  "mesh_alignment": {
    "optimal_rotation_deg": 14.0,
    "interference_volume_mm3": 0.0,
    "within_tolerance": true,
    "tooth_pitch_deg": 27.69,
    "message": "Perfect mesh - no interference"
  }
}
```

## Visualization

When exporting STEP files or showing preview, include:

1. **Wheel** rotated by `optimal_rotation_deg` around Z axis
2. **Worm** positioned at `(0, center_distance, 0)` with axis along X
3. **Wheel axis marker** (red cylinder at origin, along Z)
4. **Worm axis marker** (blue cylinder at Y=center_distance, along X)

The axis markers are essential because gear bounding boxes appear to shift when rotated (different teeth define the box limits), but the true axes remain fixed.

## Integration Points

1. **After gear generation**: Run mesh analysis on the generated wheel and worm
2. **STEP export**: Apply optimal rotation to wheel before export, or include rotation in metadata
3. **JSON output**: Add `mesh_alignment` section to output data
4. **Visualization**: Include axis markers in preview/export

## Test Case

For a 13-tooth M0.5 wheel with 1-start worm at 5.75mm center distance:
- Expected tooth pitch: 27.69°
- Expected optimal rotation: ~14° (varies with STEP geometry)
- Expected interference: 0.0mm³ (perfect mesh)

Without rotation, typical interference is ~2mm³ (teeth collide with worm threads).

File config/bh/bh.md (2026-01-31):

# Worm Gear Design Specification

## Overview

| Parameter | Value |
|---|---|
| Gear Ratio | 10:1 |
| Module | 0.600 mm |
| Centre Distance | 5.900 mm |
| Hand | right |
| Profile | ZI |
| Worm Type | globoid |
| Pressure Angle | 25.0° |

## Worm Gear (Driving)

| Dimension | Value |
|---|---|
| Number of Starts | 1 |
| Tip Diameter (OD) | 7.000 mm |
| Pitch Diameter | 5.800 mm |
| Root Diameter | 4.300 mm |
| Lead | 1.885 mm |
| Lead Angle | 5.91° |
| Addendum | 0.600 mm |
| Dedendum | 0.750 mm |
| Thread Thickness | 0.942 mm |

**Recommended Length:** 12.0 mm

## Worm Wheel (Driven)

| Dimension | Value |
|---|---|
| Number of Teeth | 10 |
| Tip Diameter (OD) | 7.200 mm |
| Pitch Diameter | 6.000 mm |
| Root Diameter | 4.500 mm |
| Throat Diameter | 6.600 mm |
| Helix Angle | 84.09° |
| Addendum | 0.600 mm |
| Dedendum | 0.750 mm |

**Recommended Face Width:** 7.2 mm

## Assembly & Performance

| Parameter | Value |
|---|---|
| Centre Distance | 5.900 mm |
| Backlash | 0.000 mm |
| Estimated Efficiency | 64.8% |
| Self-Locking | Yes |

## Manufacturing Notes

- **Profile Type:** ZI
- **Wheel Generation:** Virtual hobbing (72 steps)
- **Worm Type:** Globoid

## Validation

**Status:** ❌ Design has errors

### Errors

- **CONTACT_RATIO_TOO_LOW**: Calculated contact ratio 0.33 < 1.0. Teeth will not maintain continuous contact.
  - *Suggestion*: Increase wheel teeth count or lead angle for smoother operation. DIN 3975 §7.4 recommends contact ratio >= 1.2

### Warnings

- **TEETH_UNDERCUT_RISK**: Wheel has 10 teeth, minimum is 12 for 25.0° pressure angle
  - *Suggestion*: Use profile shift coefficient ≥ 0.18 to avoid undercut (current: 0.00)
- **TEETH_VERY_LOW**: Wheel has only 10 teeth. This is unusual for worm gears.
  - *Suggestion*: Consider higher ratio or multi-start worm for better contact ratio
- **WHEEL_BORE_THIN_RIM**: Wheel rim is thin (0.62mm) with bore 3.2mm
  - *Suggestion*: Consider reducing bore for adequate strength

### Information

- Drive is self-locking (backdrive prevented)
- ZI profile selected - involute helicoid for high precision hobbed gears
- Throat reduction: 0.12mm (hourglass depth ~0.23mm)
- Globoid worm provides better contact area with wheel
- Recommended: wheel width 7.20mm, worm length 11.97mm

## Notes

- All dimensions in millimeters unless otherwise noted
- Efficiency estimate assumes steel worm on bronze wheel with lubrication
- Self-locking determination is approximate - verify with actual materials
- Throat diameter is for enveloping (throated) wheel design
- Recommended dimensions are guidelines based on contact ratio requirements

---
*Generated by Wormgear Calculator*

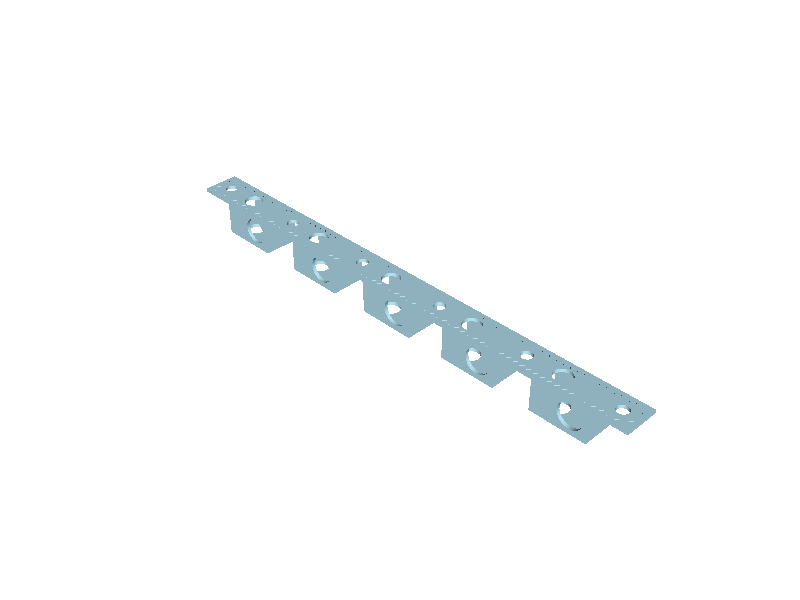
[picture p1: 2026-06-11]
sent/fixedv2/frame_rh_iso.png

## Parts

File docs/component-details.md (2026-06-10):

# Component Details — 5-Gang Instrument Tuning Machines

All dimensions in **mm** | Tolerances in brackets where critical

**Config: c13-10** 

---

## Overview

One tuner set = 1 RH (right-hand) + 1 LH (left-hand) assembly.
Each assembly has **5 tuning stations**.
LH is a mirror of RH.

### Parts per assembly

| Part | Qty | Material | Identical LH/RH? |
|---|-----|---|---|
| Frame | 1 | Brass (CZ121) | No — mirrored |
| String post | 5 | Brass (CZ121) | Yes — same part |
| Peg head + worm | 5 | Brass (CZ121) | thread direction L & R|
| Worm wheel | 5 | Phosphor bronze (PB102) | helix direction L & R|
| M2 x 4mm pan head screw | 10 | Stainless steel | Yes |
| M2.5 washer (5.5mm OD) | 5 | Stainless steel | Yes |
| M2 washer (~5mm OD) | 5 | Stainless steel | Yes |

### Hardware (buy, not manufactured)

| Item | Size | Qty per assembly |
|---|---|---|
| Pan head screw | M2 x 3mm | 10 (5 peg + 5 post) |
| Washer (peg retention) | M2.5 (ID 2.7, OD 5.5, t=0.5) | 5 |
| Washer (post retention) | M2 (ID ~2.2, OD ~5.0, t=0.5) | 5 |
| Mounting bolt | M3 mushroom head | 6 |

---

## 1. Frame

Square brass tube with machined openings. 5 rigid box sections connected by a flat mounting plate (top wall).

### Dimensions

| Parameter | Value |
|---|---|
| Cross-section (outer) | 10.0 x 10.0 |
| Wall thickness | 1.0 |
| Internal cavity | 8.0 x 8.0 |
| Total length | 145.0 |
| Housing length | 16.2 (each box section) |
| End length | 10.0 (solid ends, each side) |
| Tuner pitch | 27.2 (centre-to-centre) |
| Number of housings | 5 |

### Holes (5 of each, one per housing)

| Hole | Face | Diameter | Tolerance |
|---|---|---|---|
| Post bearing | Top | 5.05 | H7 (reamed) |
| Wheel inlet | Bottom | 5.1 | +0.1 |
| Worm entry | Right side (RH) | 7.05 | +0.1 |
| Peg bearing | Left side (RH) | 4.55 | H7 (reamed) |
| Mounting | Bottom plate | 3.2 | +0.1 |

Mounting holes: 6 total, in gaps between housings and at ends.

**LH frame:** Worm entry and peg bearing holes swap sides.

---

## 2. String Post

Turned brass part. Multi-diameter shaft with cap on top. **Same part for RH and LH.**

### Sections (top to bottom)

| Section | Diameter | Length | Notes |
|---|---|---|---|
| Cap | 7.5 | 1.0 | Fillet 0.25R top+bottom, 0.3 chamfer |
| Visible post | 6.0 | 5.5 | String hole here |
| Frame bearing | 5.0 (h7) | 1.1 | Passes through top wall |
| DD section | 3.4 / AF 2.4 | 7.2 | Wheel interface (slip fit in 3.5 / AF 2.5 bore) |
| **Total** | | **14.8** | |

### Features

| Feature | Detail |
|---|---|
| String hole | 1.7 dia, cross-drilled, 2.75 from bearing shoulder |
| DD flats | 2 flats, 0.5 deep, across-flats = 2.4 |
| M2 tap hole | Bottom of DD, 1.6 drill, 4.0 deep |
| Cap grooves | 3 concentric V-grooves, 0.33 wide x 0.33 deep, outer at 6.0 dia |

---

## 3. Peg Head + Worm

Decorative ring with integral worm shaft. **RH and LH have opposite thread direction.**

### Key dimensions

| Feature | Dimension |
|---|---|
| Ring outer diameter | 12.5 |
| Ring bore | 9.8 (offset 0.25 from centre) |
| Cap diameter | 8.5 |
| Cap length | 1.0 |
| Shoulder diameter | 7.0 |
| Shaft diameter | 4.5 (h7) |

### Worm thread

| Parameter | Value |
|---|---|
| Module | 0.5 |
| Type | Cylindrical |
| Starts | 1 |
| Pitch diameter | 6.0 |
| Tip diameter | 7.0 |
| Root diameter | 4.75 |
| Lead (axial advance per rev) | 1.571 |
| Lead angle | 4.76 deg |
| Worm length | 7.7 |
| Pressure angle | 20 deg |

### Shaft sections (from ring outward)

| Section | Diameter | Length | Notes |
|---|---|---|---|
| Worm | 7.0 tip / 4.75 root | 7.7 | Threaded |
| Bearing | 4.5 (h7) | 1.3 | Passes through frame wall |
| **Total shaft** | | **9.0** | |

### Features

| Feature | Detail |
|---|---|
| M2 tap hole | End of shaft, 1.6 drill, 3.0 deep |
| Pip (decorative) | 2.1 dia x 1.2 long, on ring face |
| Edge chamfer | 0.3 all edges |

Worm thread is integral to the peg shaft. No pins or setscrews used. Shaft must be concentric to worm pitch diameter within 0.01mm.

### Procedural peg head geometry

A parametric alternative to the STEP-imported head geometry exists in
`src/gib_tuners/components/peg_head_procedural.py`. It builds the ring, pip,
cap, shoulder, and gear shaft entirely from build123d revolve/spline/boolean
operations — no STEP file dependency.

This produces the **head body only** (Z=0 at shoulder datum, shaft in +Z,
ring/pip in -Z). The worm, bearing shaft, and tap hole are added separately
by the existing peg head pipeline.

Origin: reverse-engineered from `reference/peghead7mm.step` via the
`step-fingerprint` project. Validated by 43 geometric fingerprint tests
(`tests/test_peg_head_procedural.py`) covering volume, surface area, bbox,
inertia, face inventory, 20 cross-sections, and 15x12 radial profiles.

Known intentional differences from the reference STEP:
- Ringshaft uses a smooth spline (reference used cone+cylinder)
- No small boss cylinder on shaft tip (replaced by worm in assembly)
- Pip fillets drawn as arcs in the 2D revolve profile (exact torus surfaces)

## 4. Worm Wheel

Gear with DD bore. **RH and LH have opposite helix direction.**

### Dimensions

| Parameter | Value |
|---|---|
| Module | 0.5 |
| Number of teeth | 13 |
| Pitch diameter | 6.5 |
| Tip diameter | 7.6 |
| Root diameter | 5.55 |
| Face width | 7.7 |
| Profile shift | +0.3 |
| Pressure angle | 20 deg |

**Tip reduction (0.2): Tooth tips shortened 0.2mm to prevent interference with
  worm root. Already applied — the 7.6 tip diameter includes this reduction.**

### Bore (DD cut)

| Parameter | Value |
|---|---|
| Bore diameter | 3.5 |
| Across flats | 2.5 |
| Flat depth | 0.5 (each side) |

---

## 5. Assembly — Gear Mesh

| Parameter | Value |
|---|---|
| Centre distance | 6.25 |
| Gear ratio | 13:1 |
| Worm axis to wheel axis | 90 deg, offset 6.25 |
| Worm Z position (in frame) | -5.0 (below frame top) |

---

## 7. Critical Tolerances

| Feature | Tolerance | Why |
|---|---|-----|
| Post bearing dia (5.0) | h7 (-0 / -0.012) | Must rotate freely in frame |
| Peg shaft dia (4.5) | h7 (-0 / -0.012) | Must rotate freely in frame |
| Frame bearing holes | H7 (+0.012 / +0) | Match shaft tolerances |
| DD flats (post + wheel) | +/- 0.02 | Anti-rotation fit |
| Housing pitch (27.2) | +/- 0.05 | Alignment across 5 stations |
| Worm pitch diameter (6.0) | +/- 0.02 | Gear mesh quality |
| Centre distance (6.25) | +/- 0.02 | Gear mesh quality |

---

## 8. File List

| File | Description |
|---|---|
| `frame_rh_5gang.step` | Right-hand frame |
| `frame_lh_5gang.step` | Left-hand frame |
| `string_post.step` | String post (same for both hands) |
| `peg_head_rh.step` | Peg head + worm, right-hand thread |
| `peg_head_lh.step` | Peg head + worm, left-hand thread |
| `wheel_rh.step` | Worm wheel, right-hand helix |
| `wheel_lh.step` | Worm wheel, left-hand helix |

STL versions also available (same names, `.stl` extension).

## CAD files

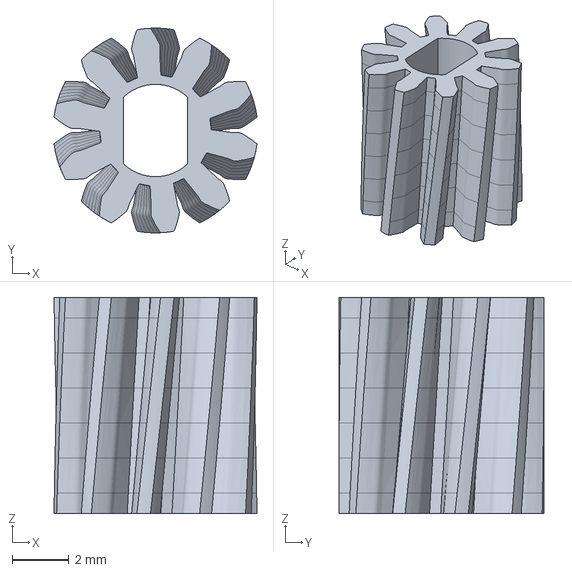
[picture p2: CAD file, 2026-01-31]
config/balanced/wheel_m0.6_z10.step
7.14 x 7.20 x 7.60 mm

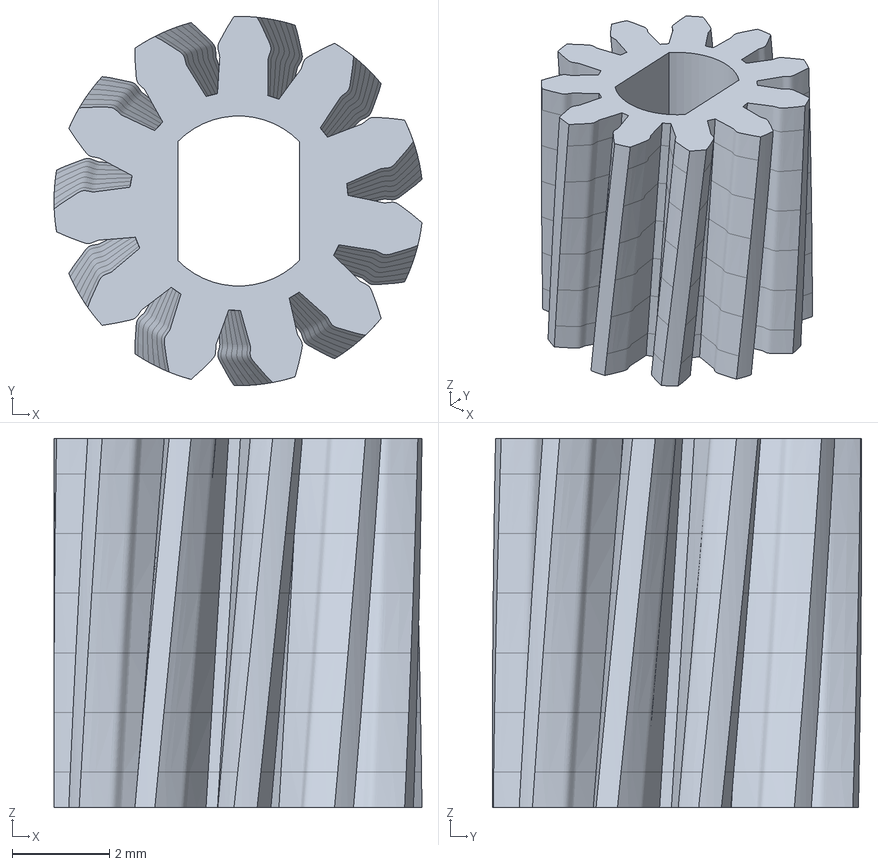
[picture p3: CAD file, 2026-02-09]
config/c11/wheel_m0.6_z11.step
7.57 x 7.60 x 7.60 mm

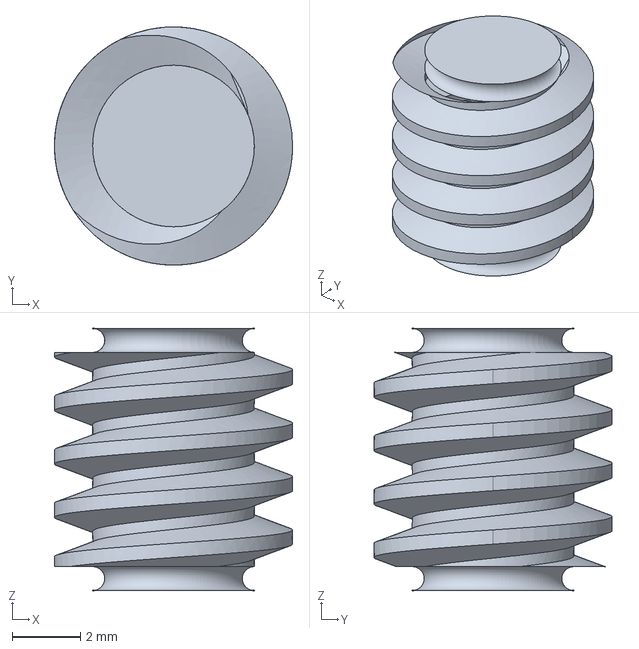
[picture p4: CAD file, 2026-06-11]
config/c13-10/test/worm_m0.5_z1.step
7.00 x 7.00 x 7.70 mm

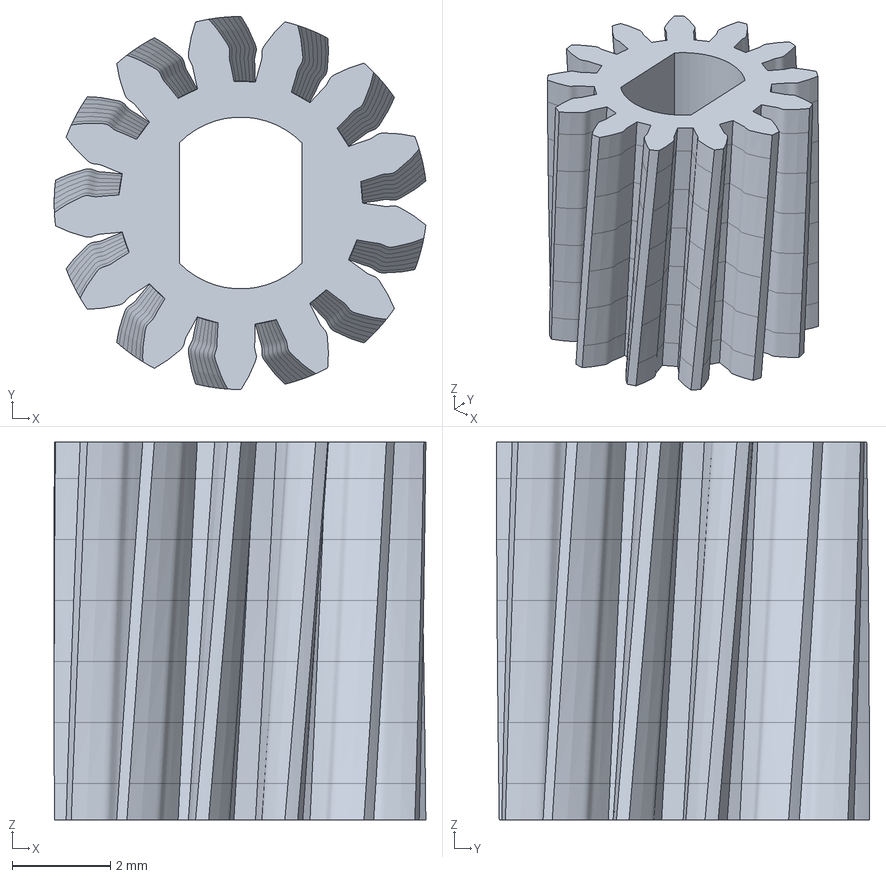
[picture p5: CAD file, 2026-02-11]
config/c13-10/wheel_m0.5_z13.step
7.57 x 7.60 x 7.70 mm

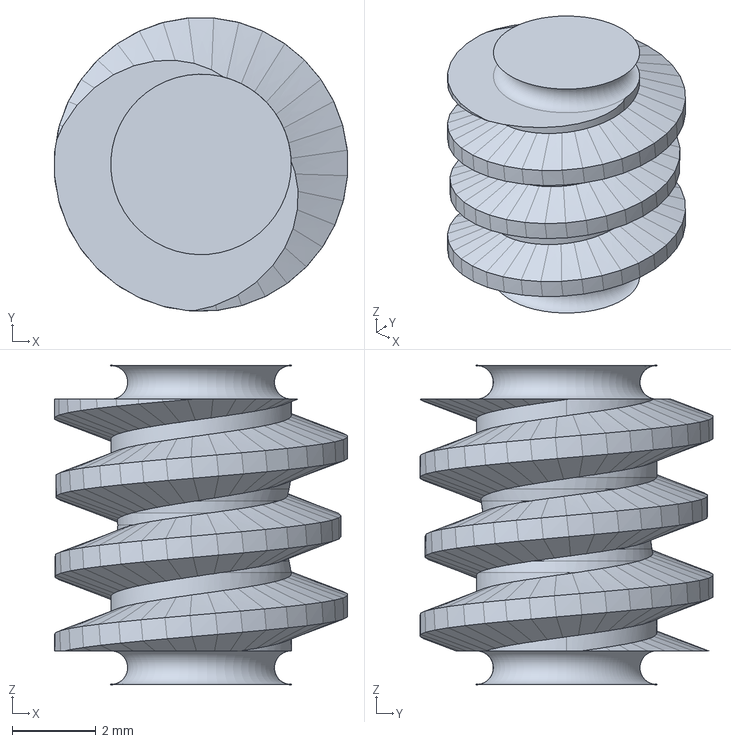
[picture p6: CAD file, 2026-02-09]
config/trim/worm_m0.6_z1.step
6.99 x 6.99 x 7.60 mm

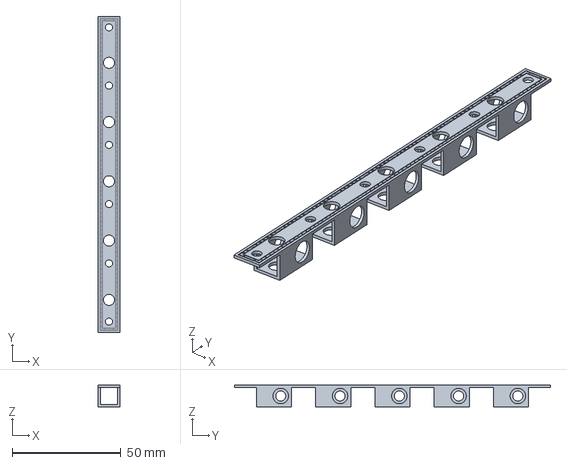
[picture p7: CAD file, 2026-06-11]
sent/fixedv2/frame_rh_5gang.step
10.0 x 145.0 x 10.0 mm

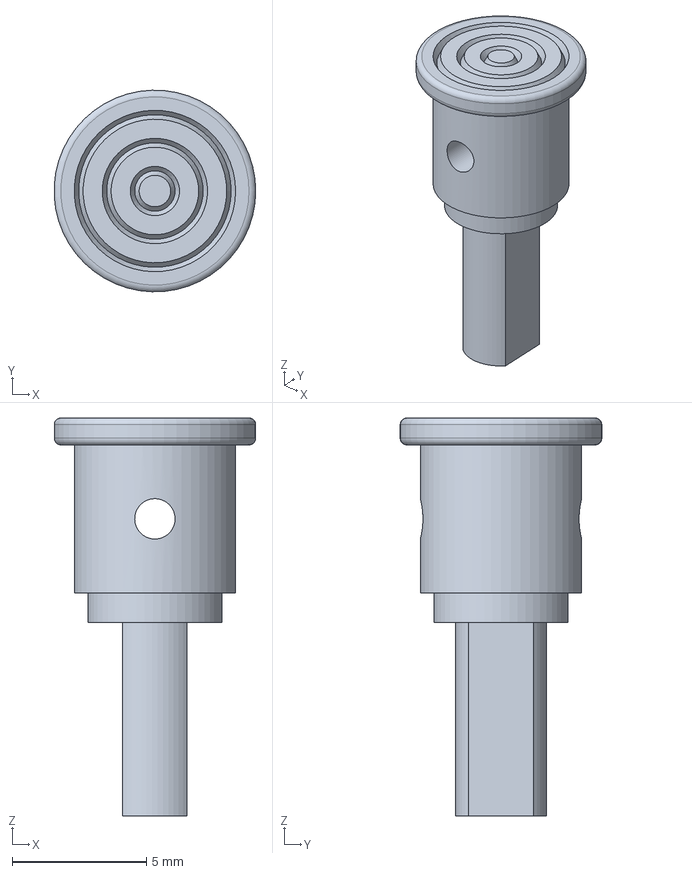
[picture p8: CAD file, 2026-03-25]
sent/ptype/string_post.step
7.49 x 7.50 x 14.8 mm

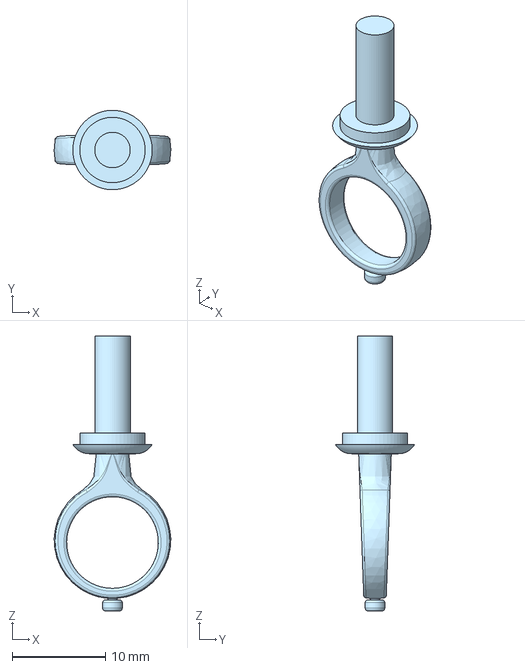
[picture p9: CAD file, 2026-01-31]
reference/peghead7mm.step
12.5 x 8.50 x 29.4 mm

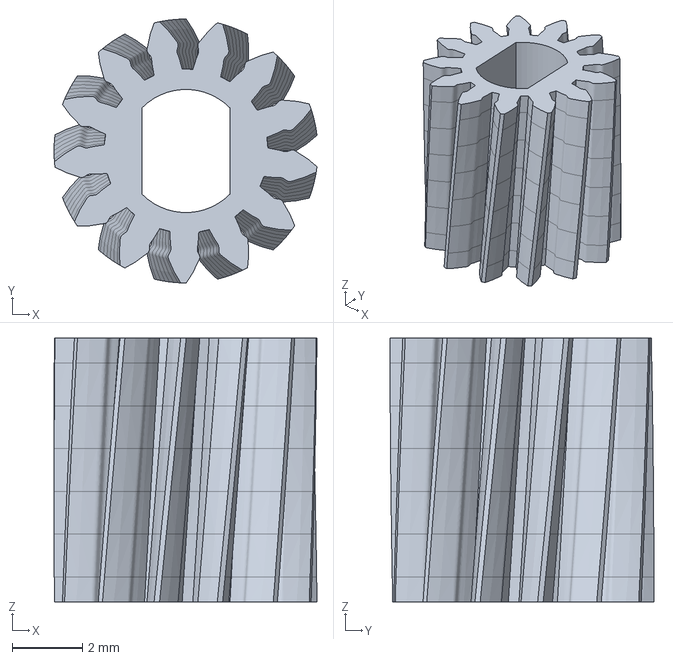
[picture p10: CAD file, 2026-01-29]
reference/wheel_m0.5_z13.step
7.47 x 7.50 x 7.50 mm

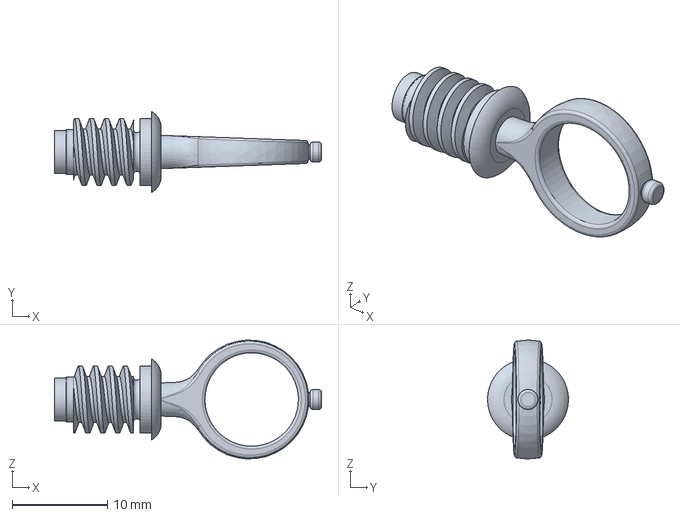
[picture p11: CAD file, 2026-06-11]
sent/fixedv2/peg_head_rh.step
28.0 x 8.50 x 12.5 mm

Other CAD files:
sent/fixedv2/senttomeicy/wheel_rh.step
config/c13-10/test/wheel_m0.5_z13.step
sent/fixedv2/senttomeicy/frame_lh_5gang.step
sent/fixedv2/wheel_lh.step
sent/ptype/frame_rh_5gang.step
sent/fixedv2/senttomeicy/peg_head_lh.step
sent/ptype/wheel_lh.step
config/archive/bh/worm_m0.6_z1.step
config/archive/bh11-cd/worm_m0.6_z1.step
config/archive/bh11/worm_m0.6_z1.step
config/archive/c13/wheel_m0.5_z13.step
config/bh/worm_m0.6_z1.step
config/bh11-cd-fx/worm_m0.6_z1.step
config/bh11-cd/worm_m0.6_z1.step
config/bh11/worm_m0.6_z1.step
config/c13-10/test/wheel_m0.5_z13.3mf
config/c13-10/test/wheel_m0.5_z13.stl
config/c13-10/test/worm_m0.5_z1.stl
config/c13/wheel_m0.5_z13.step
reference/peg.dxf
reference/peghead-and-shaft.step
reference/pegsmall.dxf
reference/rhframe.step
reference/worm.step
reference/worm_m0.5_z1.step
sent/fixedv2/frame_lh_5gang.step
sent/fixedv2/peg_head_lh.step
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

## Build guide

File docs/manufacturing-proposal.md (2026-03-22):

# Manufacturing Proposal: 10–20 Pairs of 5-Gang Tuners

**Constraint:** Frames, posts, and pegs must be brass or look like brass.

**Recommended gear profile: c13** (`config/c13/`). Cylindrical worm, M0.5, 13-tooth wheel, 20° pressure angle, profile shift +0.3. Every component falls into standard job-shop territory — no 5-axis milling, no investment casting required.

| Parameter | Value |
|---|---|
| Gear module | M0.5 |
| Worm type | Cylindrical |
| Wheel teeth | 13 |
| Ratio | 13:1 |
| Pressure angle | 20° |
| Centre distance | 6.25mm |
| Wheel profile shift | +0.3 |
| Wheel rim thickness | 1.02mm |

Key advantages of c13 over earlier profiles (cyl11, bh11-cd-fx):
- **Finer pitch (M0.5 vs M0.6):** smoother feel, finer adjustment resolution
- **13:1 ratio:** higher reduction for more precise tuning
- **1.02mm rim thickness:** significantly more robust than cyl11's 0.8mm, reducing hobbing risk
- **Profile shift +0.3:** stronger tooth roots, better load distribution
- **Standard manufacturing:** all components machinable with conventional CNC and hobbing

---

## Bill of Materials (per pair = 1 RH + 1 LH)

| Component | Per pair | 10 pairs | 20 pairs | Notes |
|---|---|---|---|---|
| Frame | 2 | 20 | 40 | 1 RH + 1 LH (mirrored) |
| Peg head + worm | 10 | 100 | 200 | 5 RH-thread + 5 LH-thread |
| Worm wheel | 10 | 100 | 200 | 5 RH-helix + 5 LH-helix |
| String post | 10 | 100 | 200 | Symmetric — identical for both hands |
| M2 x 4mm pan head screw | 20 | 200 | 400 | Peg + post retention |
| M2.5 washer (5.5mm OD) | 10 | 100 | 200 | Peg shaft retention |
| M2 washer (~5mm OD) | 10 | 100 | 200 | Post retention |
| Mounting bolts (mushroom head) | 12 | 120 | 240 | 6 per frame |

**Total custom parts: 32 per pair, 640 for 20 pairs.**

---

## Component 1: Frame — CNC Mill from Stock Box Section

**The easiest component. The stock material does most of the work.**

- **Material:** CZ121 (CW614N) free-machining brass box section, 10mm x 10mm, 1.1mm wall
- **Stock length:** 145mm per frame (cut from 1m or 2m bars)
- **Tooling cost:** Nil beyond standard cutters + one soft-jaw fixture

### Operations (single-setup on 4-axis mill or 3-axis with indexing)

1. Cut bar to 145mm (saw)
2. Mill away top + side walls between housings, leaving 5 rigid boxes connected by the 1.1mm mounting plate
3. Drill + ream 5x post bearing holes — top face, ø5.05mm (H7)
4. Drill 5x wheel inlet holes — bottom face, ø5.1mm
5. Drill 5x worm entry holes — one side face, ø7.1mm
6. Drill + ream 5x peg bearing holes — opposite side face, ø4.55mm (H7)
7. Drill 6x ø3.2mm mounting holes in bottom plate (in gaps between housings)
8. Engrave "R" or "L" on inside surface (laser or engraving cutter)
9. Deburr all edges

**LH frame** is the same program with entry/bearing holes swapped sides. Same fixture, flip the workpiece.

**Critical tolerances:** Reamed bearing holes ±0.01mm, housing pitch 27.2mm ±0.05mm.

**Estimated cycle:** ~15–20 min per frame once fixtured.

**Recommendation:** Straightforward job-shop CNC work. Any precision machining house with 3-axis mills can do this. The box section provides outer dimensions and wall thickness for free.

---

## Component 2: String Post — Swiss Screw Machining

**Classic multi-diameter turned part. A Swiss lathe shop will barely blink at this.**

- **Material:** CZ121 brass round bar, ø8mm
- **All 200 posts are identical** (symmetric for both hands)

### Dimensions (bottom to top)

| Section | Diameter | Length |
|---|---|---|
| DD cut (wheel interface) | ø3.5mm, AF 2.5mm | 7.1mm |
| Frame bearing | ø5.0mm | 1.2mm |
| Visible post | ø6.0mm | 5.5mm |
| Cap | ø7.5mm | 1.0mm |
| **Total** | | **14.8mm** |

### Operations

1. **Swiss lathe (primary):** Turn all 4 diameters, form cap fillet (0.25mm R), part off
2. **Secondary ops (transfer or bench mill):**
   - Mill 2x DD flats (0.5mm deep, forming AF 2.5mm)
   - Cross-drill ø1.7mm string hole (2.75mm from bearing shoulder), chamfer both entries (0.3mm)
   - Tap M2 blind hole from bottom (4mm deep)
   - Cut 3x concentric V-grooves on cap face (0.33mm wide/deep, outer ø6mm)

**Critical tolerances:** ø5.0mm bearing h7 (−0/−0.012mm), DD flats ±0.02mm.

**Estimated cycle:** ~2 min on Swiss lathe + 3–4 min secondary ops.

**Recommendation:** Send to a Swiss-lathe house. At 100–200 qty the setup cost amortises well. The DD flats and cross-hole require a secondary op station or a separate milling setup. V-grooves on the cap could be done on the lathe with a form tool. Same part regardless of gear profile.

---

## Component 3: Peg Head + Worm — CNC Lathe + Mill

**A cylindrical worm thread can be single-point cut on a standard CNC lathe. This opens up a pure-machining route, eliminating investment casting.**

- **Material:** CZ121 free-machining brass, ø14mm bar
- **Geometry source:** `reference/peghead-and-shaft.step` (ring) + cylindrical thread from worm_gear.json
- **Two variants needed:** RH worm (50–100 pcs) and LH worm (50–100 pcs)

### Key Dimensions

| Feature | Dimension |
|---|---|
| Shaft (bearing section) | ø4.5mm |
| Shoulder (entry hole interface) | ø7.0mm |
| Worm pitch diameter | 6.0mm |
| Worm tip diameter | 7.0mm |
| Worm root diameter | 4.75mm |
| Worm length | 7.6mm |
| Worm thread | M0.5, single-start, lead 1.57mm |
| Cap | ø8.5mm (must be > 7.1mm entry hole) |

**Process (CNC lathe with live tooling, or lathe + mill):**

1. **Lathe — main profile:** Turn shaft ø4.5mm, shoulder, and outer ring envelope from ø14mm bar
2. **Mill — ring features:** Mill the offset bore (ø9.8mm, 0.25mm offset), pip, and cap using live tooling or transfer to mill
3. **Lathe — worm thread:** Single-point cut cylindrical worm, M0.5, single-start, 7.6mm long. Standard threading cycle on CNC lathe.
4. **Drill + tap:** M2 hole in shaft end, 4mm deep
5. **Finish:** Chamfer edges (0.3mm), light polish

**Critical tolerances:**
- Shaft ø4.5mm: h7 (−0/−0.012mm)
- Worm pitch diameter 6.0mm: ±0.02mm
- Cap ø8.5mm: ±0.1mm (must be > 7.1mm entry hole)

**Estimated cycle:** ~8–12 min per piece.
**Estimated cost:** £8–15 per piece (pure CNC, no casting tooling).

---

## Component 4: Worm Wheel — Standard Gear Hobbing

**With a cylindrical worm, the wheel has involute teeth that can be cut with an off-the-shelf M0.5 hob.**

- **Material:** Phosphor bronze PB102 (C51000) — recommended for wear; or CZ121 brass
- **Key dims:** 13 teeth, M0.5, 7.6mm OD, 7.6mm face width, ø3.5mm DD bore, profile shift +0.3
- **Two variants:** RH-helix and LH-helix (reverse hob rotation)

**Process:**
1. Turn blank from ø10mm bar: face to 7.6mm width, bore ø3.5mm with DD flats
2. **Hob teeth** with standard M0.5 gear hob on a hobbing machine (set hob for +0.3 profile shift)
3. Deburr tooth edges

**Alternative methods (all viable for cylindrical teeth):**
- **Wire EDM:** Cut tooth profiles from pre-bored blanks. Good accuracy, no hob needed.
- **CNC gear milling:** Single end mill, indexing each tooth gap. Slower but no special tooling.

**Rim thickness:** 1.02mm (root ø5.55mm to bore ø3.5mm). Robust for bronze at guitar tuner loads. Comfortable margin for hobbing.

**Estimated cost:** £2–5 per piece (hobbed), £3–5 per piece (wire EDM).

---

## Manufacturing Strategy Summary

| Component | Process | Material | Qty (20 pairs) | Est. unit cost |
|---|---|---|---|---|
| Frame | CNC mill from box section | CZ121 brass box 10x10x1.1 | 40 | £20–30 |
| String post | Swiss lathe + secondary ops | CZ121 brass bar ø8mm | 200 | £5–8 |
| Peg head + worm | CNC lathe + live tooling | CZ121 brass bar ø14mm | 200 | £8–15 |
| Worm wheel | Gear hobbing (M0.5 hob) | PB102 phosphor bronze | 200 | £2–5 |
| Hardware | Buy-in | Stainless/brass | ~800 pcs | £0.10–0.30 ea |

---

## Rough Cost Estimate (20 pairs)

| | Unit cost | Qty | Subtotal |
|---|---|-----|---|
| Frames | £25 | 40 | £1,000 |
| String posts | £6.50 | 200 | £1,300 |
| Peg heads | £12 | 200 | £2,400 |
| Wheels | £3.50 | 200 | £700 |
| Hardware | £0.20 | 800 | £160 |
| Setup/tooling (amortised) | | | ~£800 |
| **Total** | | | **~£6,360** |
| **Per pair** | | | **~£320** |

For 10 pairs: ~£400/pair.

---

## Recommended Execution Plan

### Phase 0 — Prototype Validation (before committing to batch)

1. Build 2x-scale FDM prints for fit checking (`python scripts/build.py --gear c13 --scale 2.0 --tolerance prototype_fdm`)
2. Build 1x-scale resin prints for dimensional validation
3. CNC 1 pilot peg head to validate lathe program and worm thread
4. Machine 2–3 pilot string posts to validate Swiss lathe program
5. Hob 2–3 pilot wheels to validate tooth mesh with pilot worm
6. CNC 1 pilot frame to validate fixturing and hole positions
7. Assemble 1 complete pilot unit — verify fit, rotation, backlash

### Phase 1 — Material Procurement

- CZ121 brass box section 10x10x1.1mm wall (~3m for 20 pairs)
- CZ121 brass bar ø8mm (~4m for 200 posts)
- CZ121 brass bar ø14mm (~4m for 200 peg heads)
- PB102 phosphor bronze bar ø10mm (~2m for 200 wheels)
- M0.5 gear hob (off-the-shelf, or verify gear shop has one)

### Phase 2 — Parallel Production

- **Stream A:** Frame machining (CNC shop, 2–3 weeks)
- **Stream B:** String post turning (Swiss lathe shop, 1–2 weeks)
- **Stream C:** Peg head turning + worm threading (CNC lathe shop, 2–3 weeks)
- **Stream D:** Wheel blanking + hobbing (gear shop, 1–2 weeks)

**Total lead time: ~3–4 weeks** (all streams in parallel, no casting bottleneck).

### Phase 3 — Assembly & QC

- Assembly per spec Section 6 (worm → wheel → post sandwich; order flexible with cylindrical)
- Function test each unit (smooth rotation, no binding, backlash check)
- Pair and package RH + LH sets

---

## Key Risks and Mitigations

| Risk | Impact | Mitigation |
|---|---|---|
| Zero backlash with manufacturing variation | Tight spots, rough feel | Add 0.02–0.05mm backlash in JSON; verify on pilot |
| Box section wall variation | Bearing hole tolerance blown | Source measured/certified stock; verify incoming dims |
| DD fit too tight or loose | Wheel slips or won't assemble | Validate with pilot parts before full batch |
| Peg head ring complexity on CNC | Poor surface finish in bore | May need casting for ring only; worm still CNC |
| LH worm thread | Left-hand threading less common | Most CNC lathes support it; verify with shop |
| M0.5 hob availability | Delays if not in stock | Source early; M0.5 is standard metric, widely available |

---

## Brass Appearance Options

The spec calls for brass on all visible parts. For the wheels specifically:

1. **Phosphor bronze (PB102)** — Recommended. Warm golden colour, superior wear against brass worm (dissimilar metals reduce galling). Virtually indistinguishable from brass when installed. Standard in watchmaking and precision gear applications.

2. **CZ121 brass** — Same material as frame and posts. Visually identical. Slightly worse wear (brass on brass) but acceptable at guitar tuner loads (~80N string tension).

3. **Nickel silver (NS106)** — Silver-brass appearance. Only for instruments with nickel hardware. Not recommended for historic brass-look reproduction.

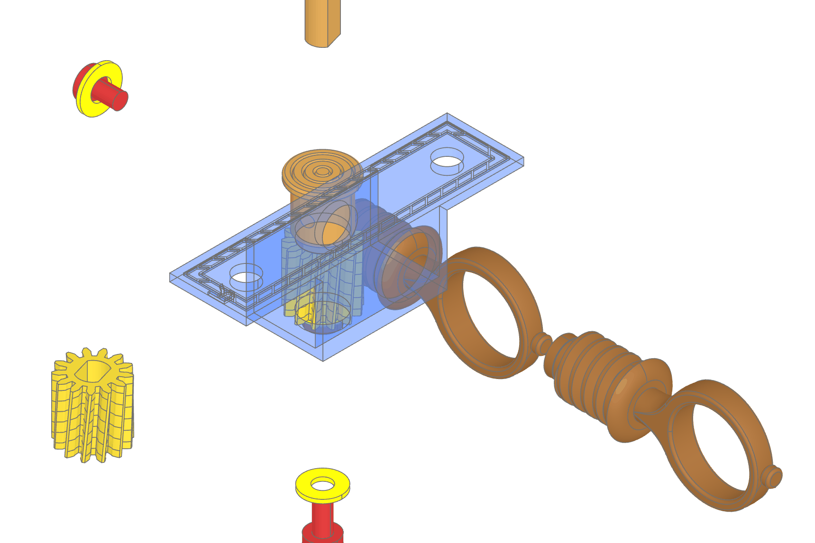
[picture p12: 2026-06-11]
assembly.gif

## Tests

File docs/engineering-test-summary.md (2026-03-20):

# Engineering Validation Tests: Summary for Engineers

This document describes the geometric and physical validation tests applied to the parametric tuner model. It is written for engineers evaluating the design, not for software developers. All tests operate on the 3D solid model or the parametric configuration and verify that the design meets manufacturing and functional requirements.

The test suite currently contains **114 tests** across 10 test modules. All pass on the c13 gear profile.

---

## What is Being Tested

The CAD model generates a 5-gang worm-drive tuning machine assembly from parametric inputs. The test suite verifies that:

- Components fit together with correct clearances
- No two solid parts occupy the same space
- Gear geometry is consistent and meshes correctly
- Rotating components clear the frame at all angles
- Wall thicknesses are sufficient after all machining operations
- Retention hardware provides adequate engagement and overlap
- The assembly can be physically built in the intended sequence
- LH and RH variants are exact mirrors of each other

The tests fall into six categories: **clearance and fit**, **gear engagement**, **rotation clearance**, **wall thickness and structural integrity**, **retention hardware**, and **LH/RH symmetry**.

---

## 1. Clearance and Fit

These verify that shafts fit through their respective holes with the designed bearing clearance, and that retention features (caps, washers) are larger than the holes they must not pass through.

| Check | What is verified | Acceptance |
|---|---|---|
| Post bearing in frame | 5.0mm shaft through 5.05mm hole | 0.05mm diametral clearance |
| Peg shaft in bearing hole | 4.0mm shaft through 4.05mm hole | 0.05mm diametral clearance |
| Worm tip through entry | Worm OD through entry hole | Entry hole > worm OD + 0.04mm |
| DD shaft in wheel bore | Post DD (2.4mm AF) in wheel DD (2.5mm AF) | 0.1mm across-flats clearance |
| M2 tap through DD bore | 1.6mm tap drill inside 2.5mm AF | Tap drill < across-flats |
| Washer through wheel inlet | 4.9mm washer through 5.1mm hole | 0.2mm clearance |
| Post cap vs bearing hole | 7.5mm cap, 5.05mm hole | Cap cannot pull through |
| Peg cap vs entry hole | 8.5mm cap, 7.2mm entry | Cap prevents push-in |
| Washer vs peg bearing | 5.5mm washer, 4.05mm hole | Washer prevents pull-out |

### Component Position Tests

These build the full 3D assembly and measure bounding box positions to verify that components are placed at the correct coordinates.

| Check | What is verified | Tolerance |
|---|---|---|
| Frame centre | Bounding box centre matches expected (X~0, Y~total_length/2, Z~-box_outer/2) | 0.5mm |
| String post Y-position | Post at housing_y - CD/2 | 0.5mm |
| Wheel Y-position | Wheel co-axial with post | 1.0mm |
| Peg head Y-position | Peg at housing_y + CD/2 | 2.0mm (asymmetric cap shifts bbox) |
| Peg head Z-position | Peg shaft at worm axis height | 2.0mm |

### Component Containment Tests

These verify that internal parts stay within the frame cavity boundaries.

| Check | What is verified | Tolerance |
|---|---|---|
| Wheel X-extent | Wheel bbox within +/- half cavity width | 0.1mm |
| Wheel Z-extent | Wheel below mounting plate ceiling, above frame floor | 0.1mm |

### Pairwise Non-Intersection (Interference Check)

Every pair of solid components in the assembly is tested for geometric interference using boolean intersection. If the intersection volume exceeds the threshold, the test fails.

| Pair type | Threshold | Rationale |
|---|---|---|
| General pairs | 0.01 mm^3 | Components must not occupy the same space |
| Gear mesh (wheel + peg/worm) | 0.1 mm^3 | Tiny contact volume acceptable at theoretical mesh point |
| Intentional overlaps (DD shaft in wheel, hardware on shafts) | Skipped | These are designed to mate |

For a 5-gang assembly, pairwise interference is checked across all housings. Total interference must remain below 0.5 mm^3.

### Boolean Operation Verification

These confirm that machining operations (drilling, milling, DD cutting) actually remove material from the solid model.

| Check | What is verified | Acceptance |
|---|---|---|
| Frame drilling | Drilled frame volume < solid box volume | >30% volume reduction (cavity + all holes) |
| DD flat cuts | DD flats remove positive volume from cylindrical shaft | Flat depth > 0, removal > 0.1mm^3 |

### Frame Geometry Tests

| Check | What is verified | Acceptance |
|---|---|---|
| Z-orientation | Mounting plate at Z=0, bottom at Z=-10mm | Within 0.01mm |
| Wheel inlet holes | At least 5 holes penetrate the bottom face (one per housing) | Face count at Z=-box_outer >= 5 |

---

## 2. Gear Engagement and Centre Distance

These tests validate that the worm and wheel mesh correctly and that the centre distance is consistent throughout the assembly.

### Worm Engagement

| Check | What is verified | Acceptance |
|---|---|---|
| Worm length vs face width | Worm thread length >= wheel face width | Full tooth contact across entire face |
| Worm axis Z-alignment | Worm axis Z-position aligns with wheel centre Z | Offset < half wheel height (geometric, from assembled model) |

The worm is integral to the peg head casting, so the geometric check verifies that the worm axis (computed from config) falls within the wheel's Z-extent in the assembled model. This ensures the thread covers the full tooth face.

### Centre Distance

| Check | What is verified | Acceptance |
|---|---|---|
| Effective CD consistency | Assembly effective_cd matches config CD minus extra_backlash | Within 0.01mm |
| Post Y-position from assembly | String post bbox centre Y matches expected housing_y - CD/2 | Within 0.5mm |
| Post hole within housing | Post bearing hole Y-position within housing Y-extent | For all 5 housings |
| Worm entry within housing | Worm entry hole edges within housing Y-extent | For all 5 housings |
| CD in reasonable range | Centre distance from JSON within 4-8mm | Sanity check |
| CD vs pitch diameters | CD consistent with (worm_PD + wheel_PD) / 2 | Within 1mm (profile shift) |

### Wheel in Cavity

| Check | What is verified | Acceptance |
|---|---|---|
| Wheel OD vs cavity width | wheel.tip_diameter < frame.box_inner | >= 0.3mm clearance |
| Wheel OD vs cavity (diagonal) | Wheel fits even on square cavity diagonal | OD < box_inner (always true for circle in square) |

---

## 3. Rotation Clearance

These tests verify that all rotating components can turn freely without fouling the frame or adjacent parts.

### Wheel Rotation

| Check | What is verified | Acceptance |
|---|---|---|
| Tip circle vs cavity X | Wheel tip diameter < cavity width | Parametric |
| Tip circle vs cavity Z | Wheel tip diameter < cavity height | Parametric |
| Swept volume (geometric) | Wheel rotated at 45-degree increments, boolean intersection with frame | < 0.05 mm^3 at every angle |

The geometric swept-volume test builds a 1-gang assembly, then rotates the wheel solid about its axis (the string post Z-axis) at 45-degree increments through 360 degrees. At each position, the boolean intersection volume with the frame is computed. This catches cases where individual teeth might clip the cavity wall even though the tip circle fits.

### Worm Rotation

| Check | What is verified | Acceptance |
|---|---|---|
| Clearance per side | (cavity - worm_OD) / 2 | >= 0.2mm per side |
| Clears top and bottom plates | Worm top edge below cavity ceiling, bottom edge above cavity floor | Worm centred at -box_outer/2 |

For a cylindrical worm the tip diameter is constant, so a parametric check is sufficient. The test verifies the worm centred at frame midpoint does not touch the inner surfaces of the top or bottom plates.

### Peg Cap Clearance

| Check | What is verified | Acceptance |
|---|---|---|
| Clears adjacent housing | Cap swept circle does not overlap the next housing | Gap >= 0 for all adjacent pairs |
| Clears frame end (last peg) | Last peg cap edge does not extend beyond frame total_length | cap_y + radius <= total_length |
| Clears frame start (first peg) | First peg cap edge does not extend before Y=0 | cap_y - radius >= 0 |

The peg head cap (8.5mm diameter) sits outside the frame on the worm entry side. When rotated, it sweeps a circle. These tests verify the swept circle does not intrude into the next housing or beyond the frame ends. This matters because the connector sections between housings have their side walls milled away and the cap must not catch on the remaining structure.

### Multi-Gang Spacing

| Check | What is verified | Acceptance |
|---|---|---|
| Housing centre spacing | All inter-housing Y-spacings equal tuner_pitch | Within 0.01mm (parametric) |
| Assembly component spacing | String post Y-spacings in 5-gang assembly match tuner_pitch | Within 0.5mm (geometric, from bbox) |

---

## 4. Wall Thickness and Structural Integrity

These tests verify that sufficient material remains after all machining operations (drilling, milling, DD cutting). Wall thickness failures can lead to part breakage under string tension or during assembly.

### DD Section (Most Marginal)

| Check | What is verified | Acceptance |
|---|---|---|
| Wall to tap bore | (across_flats - tap_bore_diameter) / 2 | >= 0.4mm **(currently 0.45mm)** |
| Advisory margin | Warn if wall drops below 0.5mm | Warning only (currently fires) |
| Diameter exceeds tap bore | DD full diameter > tap drill diameter | Concentricity requirement |

The DD section of the string post is the most structurally marginal dimension in the entire design. A 3.5mm shaft has two 0.5mm flats milled off it (leaving 2.5mm across flats), and a 1.6mm M2 tap bore runs axially through the centre. The remaining wall between the flat surface and the tap bore is only **0.45mm** — just 0.05mm above the hard minimum of 0.4mm.

### Worm Entry Hole

| Check | What is verified | Acceptance |
|---|---|---|
| Wall above and below hole | (box_outer - entry_hole) / 2 | >= 1.0mm per side |
| Does not breach plates | Hole top edge below top plate inner surface | Hole at frame midpoint Z |

The worm entry hole (7.2mm) is the largest hole drilled through a 10mm housing side face, leaving only 1.4mm per side. The test verifies the hole does not break through into the top or bottom plates.

### Other Hole Walls

| Check | What is verified | Acceptance |
|---|---|---|
| Peg bearing hole wall | (box_outer - 4.05mm) / 2 | >= 2.5mm per side |
| Post bearing hole wall | (box_outer - 5.05mm) / 2 | >= 2.0mm per side |

### Gear Component Walls

| Check | What is verified | Acceptance |
|---|---|---|
| Wheel hub (bore to root) | (root_diameter - bore_diameter) / 2 | >= 0.5mm |
| Worm root to shaft | shaft_diameter <= worm.root_diameter | Thread form complete at transition |

The wheel hub wall check verifies there is enough material between the DD bore and the base of the teeth. The worm root check ensures the bearing shaft diameter does not exceed the thread root — otherwise the thread form would be incomplete where the worm transitions to the bearing section.

### Housing Integrity After Drilling

| Check | What is verified | Acceptance |
|---|---|---|
| Frame volume vs analytical | Actual frame volume > 50% of hollow shell estimate | Holes not overlapping |
| Hole area vs face area | Each hole area < 50% of its face area | No single hole dominates a face |

These catch the case where two holes drilled from different faces might break through into each other inside the housing, creating an unintended passage and weakening the structure.

---

## 5. Retention Hardware

These tests verify that the M2 screws and washers provide adequate mechanical retention for the peg head and string post assemblies.

### Thread Engagement

| Check | What is verified | Acceptance |
|---|---|---|
| String post M2 engagement | thread_length >= 2 * M2 diameter (2D rule) | >= 4.0mm **(currently 4.0mm — at minimum)** |
| Peg head M2 engagement | tap_depth vs 2D rule | Advisory warning **(currently 3.0mm, below 4.0mm rule)** |
| Thread within DD section | thread_length <= dd_cut_length | Thread does not extend beyond DD |

The 2D rule of thumb states that thread engagement should be at least twice the major diameter for reliable retention in brass. The string post meets this exactly at 4.0mm. The peg head is below the rule at 3.0mm, but this is acceptable because string tension provides the primary retention force for the peg — the screw only prevents the peg from sliding out when no string is installed.

### Washer Overlap

| Check | What is verified | Acceptance |
|---|---|---|
| Peg washer overlap | (washer_OD - bearing_hole) / 2 | >= 0.4mm per side |
| Post washer vs bore | Standard M2 washer OD > wheel DD bore | Washer cannot fall through bore |
| Washer fits on shaft | Washer ID clears shaft for assembly | Assembly constraint |
| Screw captures washer | Screw head OD > washer ID | Washer retained by screw |

---

## 6. LH/RH Mirror Symmetry

These tests verify that the left-hand variant is an exact geometric mirror of the right-hand variant, with no dimensional distortion introduced by the mirroring process.

### Configuration

| Check | What is verified | Acceptance |
|---|---|---|
| LH hand setting | LH config has Hand.LEFT | Exact |
| LH worm hand | LH worm is left-hand thread | Exact |
| Dimension preservation | All non-hand dimensions identical (frame, post, peg, CD, wheel) | Exact |

### Frame Geometry

| Check | What is verified | Acceptance |
|---|---|---|
| Bounding box sizes match | RH and LH frame X, Y, Z extents identical | Within 0.01mm |
| Volume preserved | Mirror does not change frame volume | Within 0.1 mm^3 |
| X-coordinates reflected | LH min.X = -RH max.X, LH max.X = -RH min.X | Within 0.01mm |
| Y, Z unchanged | Mirror does not affect Y or Z coordinates | Within 0.01mm |

### Assembly Components

| Check | What is verified | Acceptance |
|---|---|---|
| All component sizes match | Each mirrored component has same bbox dimensions as RH original | Within 0.1mm per axis |

This tests every component in a 1-gang assembly (frame, string post, wheel, peg head, washers, screws) to verify that the YZ-plane mirror preserves all dimensions.

---

## 7. Gear Mesh Validation (with STEP Files)

When reference STEP files for the worm and wheel are available, more detailed mesh checks are performed using boolean operations on the imported gear geometry.

| Check | What is verified | Acceptance |
|---|---|---|
| Mesh interference volume | Boolean intersection of positioned worm and wheel | Within manufacturing tolerance |
| Optimal mesh rotation | Wheel rotation angle that minimises interference | Deterministic (repeatable) and within one tooth pitch (0 to 360/num_teeth degrees) |
| Interference at optimal rotation | Residual interference after rotation optimisation | Within backlash or manufacturing tolerance |

---

## 8. Spec Section 9 Validation

A consolidated validation function checks all items from the engineering specification Section 9 checklist:

- Worm OD fits within cavity (7.8mm) with >= 0.4mm clearance
- Worm passes through entry hole
- All shaft/hole clearances correct
- Centre distance within 4-8mm range
- CD consistent with pitch diameter calculation (within 1mm, allowing for profile shift)
- Gear modules match (worm and wheel)
- M2 thread fits through DD bore
- Washer retains wheel

The validation produces a structured pass/fail report with at least 10 individual checks.

---

## Coordinate System Reference

All geometric tests use the player's-view coordinate system defined in the specification:

```
Z=0         Mounting plate (top, visible surface)
Z=-1.1      Inside surface of top plate (cavity ceiling)
Z=-8.9      Inside surface of bottom plate (cavity floor)
Z=-10.0     Bottom surface (inside headstock cavity)

X=0         Frame centreline (post axis)
+X          Worm entry side (RH variant)
-X          Peg bearing side (RH variant)

Y=0         Frame start
Y=145       Frame end (5-gang)
```

Post axis is at `housing_y - CD/2` (toward Y=0).
Worm axis is at `housing_y + CD/2` (toward Y=145).

---

## Known Marginal Dimensions

These parameters are within tolerance but have minimal margin. The test suite flags them with advisory warnings. Any parameter changes should be checked against these:

| Dimension | Current value | Minimum acceptable | Margin | Test advisory |
|---|---|---|---|---|
| DD section wall (AF to tap bore) | 0.45mm | 0.40mm | 0.05mm | Warning fires |
| Worm cavity clearance (per side) | 0.4mm | 0.2mm | 0.2mm | Passes |
| Post bearing clearance | 0.05mm | 0.04mm | 0.01mm | Passes |
| Peg bearing clearance | 0.05mm | 0.04mm | 0.01mm | Passes |
| Peg tap engagement (M2) | 3.0mm | 4.0mm (2D rule) | -1.0mm (below rule of thumb) | Warning fires |
| String post tap engagement (M2) | 4.0mm | 4.0mm (2D rule) | 0.0mm (at minimum) | Passes |
| Peg washer overlap | 0.475mm | 0.40mm | 0.075mm | Passes |

The two advisory warnings that fire during a test run are:
1. **DD wall thickness** — 0.45mm is marginal; recommended >= 0.5mm
2. **Peg tap depth** — 3.0mm is below the 2D rule of 4.0mm; acceptable because string tension provides primary retention

---

## Test Execution

All tests run via pytest. The full suite takes approximately 45 minutes due to expensive 3D boolean operations in the assembly and interference tests.

```bash
# Full suite (114 tests, ~45 min)
pytest tests/ -v --gear c13

# Fast parametric checks only (~30 sec)
pytest tests/test_wall_thickness.py tests/test_retention.py tests/test_parameters.py tests/test_validation.py -v

# Gear engagement and rotation clearance (~5 min)
pytest tests/test_gear_engagement.py tests/test_rotation_clearance.py -v --gear c13

# LH/RH symmetry (~3 min)
pytest tests/test_symmetry.py -v --gear c13

# Assembly interference (slow, builds full 3D assemblies, ~15 min)
pytest tests/test_assembly_validation.py tests/test_assembly.py -v --gear c13

# Frame and component geometry (~2 min)
pytest tests/test_frame.py -v
```

The `--gear` flag selects the gear profile. The default is `c13-10` (M0.5, 13-tooth, cylindrical worm). Different profiles may have different clearances and should each be validated independently.

### Test Modules

| Module | Tests | Type | Time |
|---|---|---|---|
| `test_parameters.py` | 17 | Parametric (no CAD) | Fast |
| `test_validation.py` | 17 | Parametric + STEP mesh | Medium |
| `test_wall_thickness.py` | 11 | Parametric + frame build | Medium |
| `test_retention.py` | 7 | Parametric | Fast |
| `test_gear_engagement.py` | 7 | Parametric + assembly build | Medium |
| `test_rotation_clearance.py` | 10 | Parametric + assembly build | Medium |
| `test_symmetry.py` | 7 | Assembly build + mirror | Medium |
| `test_frame.py` | 10 | Component build | Medium |
| `test_assembly_validation.py` | 16 | Full assembly + boolean ops | Slow |
| `test_assembly.py` | 4 | Full assembly + STEP export | Slow |

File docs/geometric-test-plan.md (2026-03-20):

# Geometric Test Plan: Proposed Additional Tests

This document describes new geometric and engineering validation tests to add to the test suite, grouped by engineering concern. Each entry describes the physical property being verified, the acceptance criterion, and the test approach.

## 1. Gear Engagement and Centre Distance

### 1.1 Worm Engagement Length vs Wheel Face Width

**What:** The worm thread must overlap the wheel's tooth face for the full face width. If the worm is shorter than the wheel, tooth contact is incomplete and load capacity drops.

**Criterion:** `worm.length >= wheel.face_width`

**Test approach:** Pure parametric check from config values. Also verify in the assembled geometry that the worm bounding box Y-extent overlaps the wheel bounding box Y-extent by at least `wheel.face_width - 0.5mm`.

### 1.2 Centre Distance Consistency (Parametric vs Geometric)

**What:** The actual Y-distance between the string post axis and peg head axis in the assembled model must match `gear.center_distance` from JSON.

**Criterion:** Measured axis-to-axis distance within 0.05mm of config CD (tighter than the current 2mm bbox-based tolerance).

**Test approach:** Instead of using bounding box centres (which are skewed by asymmetric features like the peg cap), extract the centre of cylindrical bearing faces. For the string post, use the bearing section cylinder centre. For the peg head, use the shaft bearing cylinder centre. Measure Y-distance between these two points.

### 1.3 Centre Distance Fits Within Frame Geometry

**What:** Both the post hole and worm entry hole must physically land within the housing walls, not extend beyond the frame width.

**Criterion:**
- Post axis at `housing_y - CD/2`: the post bearing hole (5.05mm) must not extend beyond the housing Y-extent (housing_center +/- housing_length/2).
- Worm axis at `housing_y + CD/2`: the worm entry hole (7.2mm) must not extend beyond the housing Y-extent.

**Test approach:** For each housing, compute the hole edge positions and verify they fall within `[housing_center - housing_length/2, housing_center + housing_length/2]`.

### 1.4 Gear Module Match

**What:** Worm and wheel modules must be identical for proper meshing.

**Criterion:** `worm.module == wheel.module` (already tested, but listed for completeness).

### 1.5 Wheel OD Fits in Cavity

**What:** The wheel tip diameter must be smaller than the internal cavity dimension so the wheel can rotate freely.

**Criterion:** `wheel.tip_diameter < frame.box_inner` with at least 0.3mm clearance.

**Test approach:** Parametric check. Also verify in assembled geometry that the wheel bounding box in X and Z stays within cavity inner walls.

## 2. Rotation and Clearance

### 2.1 Wheel Rotation Clearance (Swept Volume)

**What:** The wheel must be able to rotate through its full range without clipping the frame cavity walls at any angle. The wheel is not circular -- it has teeth -- so the tip circle may come close to cavity walls at certain orientations.

**Criterion:** At every 1-degree increment through 360 degrees, the rotated wheel must not intersect the frame solid by more than 0.01mm^3.

**Test approach:** Build a 1-gang assembly. For each rotation angle (0 to 360 in 5-degree steps for speed, then 1-degree steps near any close calls), rotate the wheel about its axis (Z-axis through the post centre), compute boolean intersection with the frame, and verify volume < 0.01mm^3.

**Simplified alternative:** Verify the wheel tip circle diameter + 2*tooth_addendum is less than the cavity dimension in both X and Z axes. This is a conservative bounding check that avoids expensive boolean operations.

### 2.2 Worm Rotation Clearance

**What:** The worm must rotate freely within the cavity. The cylindrical worm has a constant tip diameter, so it suffices to check that the worm tip circle clears the cavity in Z (vertical).

**Criterion:** `frame.box_inner - worm.tip_diameter >= 0.4mm` (0.2mm per side).

**Test approach:** Parametric check. For extra confidence, in the assembled model, rotate the peg head + worm by 90-degree increments about its axis and verify no intersection with the frame.

### 2.3 Peg Head Rotation Clearance (Cap vs Frame)

**What:** The peg head cap sits outside the frame and must not foul against adjacent housings or the frame end when rotated.

**Criterion:** The peg cap swept circle (8.5mm diameter) must not overlap with any adjacent housing structure or frame end section.

**Test approach:** Compute the peg cap centre position and verify that `cap_diameter/2` is less than the distance to the nearest frame wall or adjacent housing edge.

### 2.4 Multi-Gang Uniform Spacing

**What:** In a 5-gang assembly, all tuner-to-tuner spacings must be equal to `tuner_pitch`.

**Criterion:** For each adjacent pair of housings, the Y-distance between equivalent component centres equals `tuner_pitch` within 0.01mm.

**Test approach:** Build a 5-gang assembly. For each pair of adjacent string posts, measure Y-distance between bounding box centres. Verify all four spacings equal `tuner_pitch`.

## 3. Wall Thickness and Structural Integrity

### 3.1 Minimum Wall Around Post Bearing Hole (Top Plate)

**What:** The post bearing hole (5.05mm) is drilled through the 1.1mm top plate. The remaining annular ring of the mounting plate around the hole must have sufficient material.

**Criterion:** The frame outer dimension minus the hole diameter, divided by 2, gives the minimum wall: `(box_outer - post_bearing_hole) / 2 >= 2.0mm`. This should be at least 2mm for structural integrity.

**Test approach:** Parametric check from config values.

### 3.2 Minimum Wall Around Worm Entry Hole (Side Wall)

**What:** The worm entry hole (7.2mm) is drilled through a 10mm x 10mm side face. The remaining material above and below the hole is critical for frame rigidity.

**Criterion:** `(box_outer - worm_entry_hole) / 2 >= 1.0mm`. The hole must leave at least 1mm of material above and below.

**Test approach:** Parametric check. Also verify geometrically that the hole doesn't break through the top or bottom plates by checking `worm_entry_hole/2 + wall_thickness <= box_outer/2`.

### 3.3 Minimum Wall Around Peg Bearing Hole (Opposite Side Wall)

**What:** The peg bearing hole (4.05mm) on the opposite side wall. This is a smaller hole so less critical, but should still be checked.

**Criterion:** `(box_outer - peg_bearing_hole) / 2 >= 2.5mm`.

**Test approach:** Parametric check.

### 3.4 DD Section Wall Thickness (String Post)

**What:** The DD section of the string post has an M2 tapped hole (1.6mm drill) running axially through a 3.5mm diameter shaft with 0.5mm flats cut into it. The minimum wall between the tap bore and the flat surface is critical.

**Criterion:** `(dd_cut.across_flats - tap_bore_diameter) / 2 >= 0.4mm`. Currently: (2.5 - 1.6) / 2 = 0.45mm. This is marginal.

**Test approach:** Parametric check. Flag a warning if wall drops below 0.5mm.

### 3.5 DD Section Wall Thickness (Wheel Bore)

**What:** The wheel has a DD bore (3.5mm diameter with 0.5mm flats). The minimum wall between the DD bore flat and the wheel root circle determines whether the wheel hub is structurally sound.

**Criterion:** `(wheel.root_diameter - wheel.bore.diameter) / 2 >= 0.5mm`. The hub wall from bore OD to tooth root must have sufficient material.

**Test approach:** Parametric check from gear JSON values.

### 3.6 Worm Thread Root to Shaft Core

**What:** The worm thread is cut into the peg head shaft. The root diameter defines the remaining core. The shaft bearing section must not be larger than the root diameter or the thread form would be incomplete at the bearing transition.

**Criterion:** `peg_head.shaft_diameter <= worm.root_diameter`. Currently 4.0mm <= 4.3mm.

**Test approach:** Parametric check.

### 3.7 Housing Wall Integrity After All Drilling

**What:** Each housing has four holes drilled through it (top, bottom, two sides). After all boolean operations, the housing walls must still form a continuous rigid box. No two holes should overlap or break through into each other.

**Criterion:** Build a single-housing frame and verify it has at least 6 distinct face groups (top, bottom, 4 sides minus holes). Verify the frame volume is within expected range (solid box minus expected hole volumes minus cavity).

**Test approach:** Build the frame, compute volume, compare against analytical estimate. The analytical volume = outer_box - inner_cavity - holes. If the actual volume is less than expected by more than 5%, a hole is cutting through a wall.

## 4. Retention and Assembly Constraints

### 4.1 Screw Thread Engagement Depth (String Post)

**What:** The M2 screw into the string post tap bore must have sufficient thread engagement for reliable retention under string tension.

**Criterion:** `thread_length >= 2 * thread_major_diameter`. For M2: engagement >= 4mm (2 * 2.0mm). Currently 4.0mm -- exactly at minimum.

**Test approach:** Parametric check.

### 4.2 Screw Thread Engagement Depth (Peg Head)

**What:** The M2 screw into the peg head tap bore.

**Criterion:** `peg_head.tap_depth >= 2 * 2.0mm = 4.0mm`. Currently 3.0mm -- below the 2D rule of thumb. Flag as a note (acceptable because string tension provides the primary retention force for the peg, not the screw).

**Test approach:** Parametric check with advisory warning.

### 4.3 Washer Coverage Over Bearing Hole

**What:** Retention washers must overlap the bearing hole edge sufficiently to prevent pull-through under load.

**Criterion:**
- Peg washer: `(washer_od - peg_bearing_hole) / 2 >= 0.5mm`. Currently (5.5 - 4.05) / 2 = 0.725mm.
- Post washer: washer OD > wheel bore diameter.

**Test approach:** Parametric check.

## 5. LH/RH Symmetry

### 5.1 Mirror Geometry Verification

**What:** The LH assembly must be an exact mirror of the RH assembly. All bounding box dimensions must match; only X-coordinates should be negated.

**Criterion:** For each component, `LH.bbox.size == RH.bbox.size` within 0.01mm. LH component X-centres should equal `-1 * RH component X-centres`.

**Test approach:** Build both RH and LH 1-gang assemblies. Compare bounding box dimensions for each part. Verify X-coordinate reflection.

## Priority Order for Implementation

1. **3.4 DD section wall thickness** -- most critical, currently marginal at 0.45mm
2. **1.2 Centre distance (geometric)** -- tighten the existing 2mm tolerance test
3. **3.2 Wall around worm entry hole** -- large hole in small section
4. **2.1 Wheel rotation clearance** -- functional correctness
5. **1.1 Worm engagement length** -- gear performance
6. **3.7 Housing wall integrity** -- structural validation
7. **1.3 CD fits within housing** -- layout check
8. **2.4 Multi-gang spacing** -- manufacturing accuracy
9. **4.1-4.3 Retention checks** -- assembly robustness
10. **5.1 LH/RH symmetry** -- variant correctness
11. **2.2-2.3 Worm and peg rotation** -- less critical (mostly parametric)
12. **3.1, 3.3, 3.5, 3.6** -- supplementary wall checks

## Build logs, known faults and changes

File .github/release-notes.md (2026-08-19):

Parametric CAD outputs for the 5-gang tuning machine, gear profile `c13-10`
(cylindrical worm, M0.5, 13-tooth wheel, 20° pressure angle, 6.25mm centre distance).

Built with:

```
python scripts/build.py --hand both --gear c13-10 -n 5 --label-frames no --format both
```

Validated against the `sent/ptype` baseline by `scripts/check_production.py`.

## Artifacts

**Assemblies** (all parts positioned)
- `assembly_5gang_rh.step` / `assembly_5gang_lh.step`
- `assembly_5gang.glb` — coloured, for 3D viewers

**Components** (STEP + STL)
- Frame RH/LH, 5-gang, unlabelled for CNC
- String post (symmetric — one part for both hands)
- Peg head RH/LH
- Wheel RH/LH

**Engineering drawings** (A3, RH shown — LH is the mirror image)
- `tuner_drawings.pdf` — all 5 sheets
- Per-sheet PDFs, plus `drawings_dxf_svg.zip` with the DXF/SVG sources

All dimensions 1:1 scale, production tolerance.

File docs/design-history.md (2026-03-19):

# Design History: Gib Tuners Mk2

## Phase 1: Foundation (Jan 29, 2026)

**PR #1 — Initial parametric frame**
- Established coordinate system: Z=0 at mounting plate, frame extends into -Z
- Parametric 1–N housing support with symmetric 10mm ends
- RH default: worm entry on +X, peg bearing on -X; LH is mirror

**PR #2 — String post redesign & 7.5mm wheel**
- Replaced E-clip groove retention with M2 tap bore from bottom (screw retention)
- Adopted 7.5mm OD wheel, 13-tooth, M0.5, 5.75mm center distance
- Frame set to 10x10x1mm box section
- Added DD (double-D) section on string post for wheel engagement

**PR #3 — Peg head construction & gear consistency**
- Peg head built by importing reference STEP, cutting at Z=0, adding new 3.5mm shaft
- Worm positioned butted against shoulder at Z=0
- Shaft: worm(7.8mm) + gap(0.2mm) + bearing wall(1.0mm) + clearance(0.1mm) = 9.1mm
- Frame adjusted to 10.35mm outer, 1.1mm wall

**PR #5 — Worm-wheel mesh positioning**
- Post/wheel axis at Y=0, worm axis at Y=+5.75mm (center distance)
- Worm centered in 8.15mm cavity with 0.175mm clearance each side

**PR #7 — Mesh rotation optimization**
- 14.75° worm rotation eliminates gear mesh interference at assembly Z-offset

**PR #9 — Frame dimensions corrected**
- Reverted to 10mm box outer, 1mm wall (eliminated all 1-gang interference)

## Phase 2: Gear Profile Evolution (Jan 30 – Feb 1, 2026)

**PR #13 — Globoid worm support**
- Added Z-axis alignment modes: AUTO (centered for cylindrical, aligned for globoid)
- New enums: WormType (CYLINDRICAL, GLOBOID), WormZMode (AUTO, CENTERED, ALIGNED)

**PR #16 — Bearing tolerances tightened for string tension**
- Bearing clearance reduced from +0.2mm to +0.05mm (reamed holes)
- Post bearing: 4.2→4.05mm, peg bearing: 4.0→3.85mm
- Reduced post tilt under 100N load from ~11° to ~3°

**PR #17 — Switch to M0.6 balanced profile**
- Gear module M0.5→M0.6, ratio 13:1→10:1
- Peg shaft increased 3.5→4.0mm for stronger M2 tap wall (0.95→1.2mm)
- All bearing holes now derived from component dimensions + 0.05mm clearance
- Switched to M2.5 washer with M2 screw (3x better peg retention, 0.25→0.75mm overlap)

**PR #20 — Axial play & retention mechanism**
- Post bearing axial play: 0.2mm (frame floats between clamping surfaces)
- Peg bearing axial play: 0.2mm
- DD cut clearance: 0.1mm (M2 screw clamps wheel to shoulder)
- Wall thickness declared fixed manufacturing constraint at 1.1mm

**PR #25 — Tighter post bearing play**
- Post bearing axial play reduced 0.2→0.1mm, bearing length 1.3→1.2mm

## Phase 3: Manufacturing Refinement (Feb 1–2, 2026)

**PR #27 — Wall thickness fixed at 1.1mm**
- Corrected from 1.0mm — this is the brass box section stock dimension, non-negotiable

**PR #31 — M2 tap depth optimized**
- Reduced M2 tap from 4mm to 3mm depth
- Improved worm wall thickness: 0.59→0.75mm (safety factor 8.1x→10.9x)
- String tension pulls worm into frame, so screw just holds in place when unloaded

**PR #32 — Wheel inlet hole redesigned**
- Reduced from 8mm to 5.1mm (4.9mm M2 washer + 0.2mm tolerance)
- Key insight: wheel enters sideways from open frame end, not through bottom hole
- Assembly order: Worm first → Wheel (sideways) → Post (DD engages wheel bore)

**PR #34 — BH11-CD gear configuration**
- M0.6 globoid worm, 11-tooth, hobbed profile

## Phase 4: Jig Design (Feb 4–6, 2026)

**PR #35 — Cutting jig**
- U-channel (10.3x10mm) with saw guide slots and kerf compensation
- Fixed locating plug + moveable end stop with M5 heat-set inserts

**PR #39 — Drilling jig**
- 2-part clamshell for drilling all 26 holes in an N-gang frame
- M14 stepped bushing pockets with 5mm minimum rim
- Dynamic wall extension per gear profile

**PR #41 — Hardware downsized M5→M3**
- Bolt clearance 5.5→3.4mm, insert OD 6.4→5.0mm
- Heat-set insert depth matched to actual insert height (4mm)

**PR #43 — Prototype drilling mode**
- Prototype: simple through-holes, 30mm wide, 8mm slab (for marking positions)
- Production: M14 stepped bushing pockets, 40mm wide, 14mm slab

**PR #44 — Heat-set insert interference fit**
- Pocket diameter reduced 5.0→4.7mm (0.3mm interference for knurling grip)
- Inserts were falling out at nominal 5.0mm

**PR #46 — Clamping plug end stop**
- Cavity extended 4mm past nominal frame length
- 10x10mm plug seats in channel, accommodates up to 4mm length variation

## Phase 5: String Post Detail & DD Fit (Feb 6–7, 2026)

**PR #47 — String post cap detail**
- Added 0.25mm fillet to cap top and bottom edges
- 3 decorative concentric V-grooves on cap top (0.33x0.33mm, outer OD 6mm)
- String post bearing increased 4.0→5.0mm; frame hole auto-derives to 5.05mm

**PR #50 — BH11-CD-FX gear profile**
- Positive profile shift (+0.3), worm relief groove
- Center distance 5.6→6.2mm, shallower teeth, stronger roots

**PR #54 — DD slip fit for compression retention**
- DD shaft undersized 0.1mm for slip fit (3.4/2.4mm AF vs 3.5/2.5mm bore)
- Bottom gap increased 0.1→0.5mm for compression travel
- Wheel positioned in clamped state: top against bearing shoulder, gap at bottom
- Washer+screw now clamps wheel via compression, not tight interference

## Phase 6: C13 Gear Profile (Feb 9, 2026)

**PR #55 — Three new gear profiles with manufacturing proposal**
- c11: Cylindrical, 25° pressure angle (standard)
- cyl11: Cylindrical, 20° pressure angle (optimized for batch production)
- trim: Globoid with virtual hobbing (premium option)
- Recommended CZ121 brass (machining), PB102 phosphor bronze (wheels)

**PR #57 — C13 adopted as preferred profile**
- M0.5, 13-tooth, 20° pressure angle, cylindrical worm
- Centre distance 6.25mm
- 1.02mm rim thickness (vs 0.8mm for cyl11) — more robust for hobbing
- Profile shift +0.3 for stronger tooth roots

**PR #58 — C13 shaft diameter override**
- Peg shaft set to 4.5mm (matches c13 worm root diameter for smooth transition)

**PR #60 — Manufacturing proposal rewritten for c13**
- Single recommended path (removed globoid A/B options)
- Finer pitch M0.5 = smoother feel, 13:1 ratio = finer tuning resolution

## Phase 7: Final Refinements (Feb 9–11, 2026)

**PR #62 — C13-10 configuration & core shaft fix**
- C13 gears with 1.0mm wall thickness and 7.7mm gear width for manufactured frames
- Core shaft undercut 0.1mm to prevent coincident surfaces eating worm teeth

**PR #64 — Decorative frame engraving**
- Rope-border inspired engraving on top plate
- Two border grooves (1mm and 2mm from edge) with 45° diagonal hatching
- Chevron pattern where short-end diagonals meet at centerline

**PR #65 — Swept worm peg head**
- Regenerated c13-10 STEP files from swept worm tool (cleaner geometry vs 36-section loft)
- Relief groove at bearing end filled for stronger M2 tap region
- Washer clearance (0.1mm) added to shaft protrusion beyond frame wall

## Key Design Decisions Summary

| Decision | Early | Final |
|---|---|---|
| Gear module | M0.5 → M0.6 → **M0.5 (c13)** | Back to finer pitch |
| Gear ratio | 13:1 → 10:1 → **13:1 (c13)** | Back to finer resolution |
| Worm type | Cylindrical → Globoid → **Cylindrical** | Simpler manufacturing |
| Frame box | 10→10.35→**10mm**, wall 1.0→**1.1mm** | Stock dimension fixed |
| Peg shaft | 3.5→4.0→**4.5mm** | Matches worm root |
| Retention | E-clip → **M2 screw + compression DD** | Simpler assembly |
| Wheel entry | Through bottom hole → **Sideways from open end** | Smaller hole, stronger frame |
| Bearing clearance | +0.2mm → **+0.05mm** | Tighter for string load |
| Jig hardware | M5 → **M3** | Proportionate to jig size |
| Jig insert fit | Nominal → **0.3mm interference** | Knurling needs grip |

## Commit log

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2026-01-28 Update spec for custom gears with DD cut bores
    Replace off-the-shelf gear modification approach with custom generated gears:
    - Globoid worm (7mm long, 2.5mm DD bore)
    - 12-tooth wheel (6mm wide, 3mm DD bore)
    - 25° pressure angle (was 20°)
    - Frame bearing hole reduced to 2.7mm for 2.5mm peg shaft
    DD cut bores eliminate need for broaching - flats milled on shafts instead.
    Different bore sizes (2.5mm vs 3mm) prevent incorrect assembly.
    Add gear STEP files and calculator parameters.
    [worm_m0.5_z1.step]
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2026-01-29 Fix frame orientation: mounting plate at Z=0, frame extends into -Z
    - Flip Z coordinate system so Z=0 is the mounting plate surface (visible
    from above when installed) and frame extends into -Z (into headstock)
    - Fix worm entry/bearing sides: RH tuner now has entry on RIGHT (+X),
    bearing on LEFT (-X), matching physical assembly orientation
    - Move R/L etching to inside surface of mounting plate (Z=-wall)
    - Fix wheel inlet holes to penetrate bottom surface (was 0.1mm short)
    - Add regression tests for Z orientation and wheel inlet holes
    - Document coordinate system convention in spec.md and CLAUDE.md
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2026-01-29 Fix wheel STEP loader to handle Solid return type
    import_step() can return Part, Solid, Compound, or list depending on
    the STEP file content. Handle all cases to fix CI failure.
2026-01-29 Redesign string post for M2 tap bore retention, update to 7.5mm wheel
    - Redesigned string post with M2 tap bore from bottom for screw retention
    (replaces previous E-clip groove design)
    - Updated gear parameters for 7.5mm wheel (13T, 5.75mm center distance)
    - Updated frame to 10×10×1mm box section (standard, pending real measurements)
    - Fixed R/L engraving to read correctly when viewed from below
    - Added post_wheel_assembly module for combined post+wheel geometry
    - Added visualization scripts for incremental assembly verification:
    - visualize_post.py: String post with color-coded sections
    - visualize_post_wheel.py: Post + wheel + hardware assembly
    - visualize_single_h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
    [wheel_m0.5_z13.step]
2026-01-29 Fix tuner_unit.py for M2 tap bore retention (removes E-clip references)
    Updated tuner_unit.py and hardware.py to work with the new string post
    design that uses M2 tap bore retention instead of E-clip groove:
    - Added create_wheel_retention_washer() and create_wheel_retention_screw()
    - Updated post positioning for new coordinate system (DD at Z=0)
    - Fixed worm Z position for frame orientation (Z=0 at top, -Z into cavity)
    - Replaced wheel_eclip with wheel_washer and wheel_screw
    - Updated debug_assembly.py to match new post layout
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2026-01-29 Update spec.md with Onshape peg head construction details
    Documented the ring/cap construction from Onshape JSON:
    - Ring created by revolve, then hollowed (headthicknessattop/2 = 1.2mm wall)
    - Bore cut at headjoinl + headouterd/2 + headinneroffset position
    - Updated dimensions to match Onshape variables
    Clarified peg head structure from outside to inside frame:
    - Button (8mm × 1mm) - decorative end
    - Ring (12.5mm OD) - finger grip
    - Join (3.5mm × 3mm) - connects ring to shaft
    - Cap (8mm × 1mm) - sits against frame, stops push-in
    - Entry shaft (6mm × 1.2mm) - through worm entry hole (6.2mm = 6.0 + 0.2 clearance)
    - Worm (6mm OD × 7mm) - in cavity
    - Bearing shaft (3.8mm × 2.4mm) - throug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
2026-01-29 Implement peg head using reference STEP file + new shaft
    Replace programmatic hollow sphere construction with STEP-based approach:
    - Import peghead-and-shaft.step, cut at Z=0 to keep ring/pip/cap/shoulder
    - Add new 3.5mm shaft (fits inside worm root 3.75mm)
    - Position worm STEP at Z=0 (butted against shoulder)
    - Add M2 tap hole (1.6mm × 4mm) at shaft end
    - Rotate -90° around Y for assembly orientation
    Shaft breakdown (9.1mm total from shoulder):
    - Worm zone: 7.8mm (0.1mm clearance each side in 8mm cavity)
    - Gap to frame end: 0.2mm
    - Bearing wall: 1.0mm
    - Washer clearance: 0.1mm
    [peghead-and-shaft.step]
2026-01-29 Fix spec/code consistency and regenerate gears at 7.8mm
    Consistency fixes:
    - Frame: box_outer 10.0→10.35mm, wall_thickness 1.0→1.1mm
    - Worm: docstring "globoid"→"cylindrical", length 7.8mm
    - spec.md: worm length 7mm→7.8mm, center distance calc 5.5→5.75mm
    Gear updates:
    - Add 7.5mm-cyl.json gear calculator config
    - Add scripts/regenerate_gears.py for STEP regeneration
    - Regenerate worm at 7.8mm (was 7.0mm)
    - Regenerate wheel with 3.5mm DD-cut bore
    [wheel_m0.5_z13.step]
2026-01-29 Fix failing tests after parameter updates
    - Update test expectations for frame dimensions (10.35mm, 1.1mm walls)
    - Handle ShapeList return from import_step in peg_head.py
    - Update validation.py to use shaft_diameter instead of bearing_diameter
    - Update worm length to 7.8mm in all JSON files and constants
2026-01-29 Fix peg head assembly positioning for correct worm-wheel mesh
    - Fix tuner_unit.py: position peg head with correct X (worm centered in
    cavity) and Y (center_distance from post) offsets
    - Fix tuner_unit.py: correct peg screw orientation so head is outside
    and shank threads into tap hole
    - Fix wheel.py: center placeholder wheel at Z=0 to match STEP convention
    - Add screw_length parameter to PegHeadParams
    - Add debug_peg_assembly.py visualization script
    - Clarify peg_head.py rotation comments
    The worm and wheel now mesh at the correct center distance (5.75mm)
    and fit properly through the frame holes.
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2026-01-29 Make gear JSON single source of truth, derive dependent params
    - Move gear JSON to config/worm_gear.json as canonical location
    - Auto-load gear params in create_default_config()
    - Derive dd_cut_length from wheel.face_width (they are the same)
    - Derive worm_entry_hole from worm.tip_diameter + clearance
    - Add validation that worm fits through entry hole
    - Add tests for derived parameter consistency
    - Remove obsolete 7.5mm-cyl.json and 75mm-globoid.json
2026-01-29 Add mesh rotation support and fix single-housing visualization
    - Add mesh_rotation_deg to GearParams (config/assembly.json)
    - Apply mesh rotation in tuner_unit.py for optimal wheel-worm alignment
    - Fix visualize_single_housing.py to use tuner_unit with correct positioning
    - Use moved() instead of locate() to preserve component positions
    - Add interference report to validate assembly (5.67mm³ total, all OK)
2026-01-29 Move experimental scripts to experiments/, add mesh rotation utilities
    Reorganize scripts:
    - Move debug and intermediate visualization scripts to scripts/experiments/
    - Keep main build and visualization scripts in scripts/
    Add mesh rotation and interference checking:
    - wheel.py: add calculate_mesh_rotation() for optimal gear alignment
    - validation.py: add check_wheel_worm_interference(), find_optimal_mesh_rotation()
    - gang_assembly.py: pass through worm_step_path parameter
    - test_validation.py: add tests for interference checking
    Add wormgear integration files:
    - reference/mesh_alignment_module.py: standalone module for gear projects
    - reference/WORMGEAR_INTEGRATION_PROMPT.md: integration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
2026-01-29 Add full N-gang assembly visualization script
    New script visualize_full_assembly.py:
    - Displays 1-5 gang assemblies with all components
    - Supports --hand left/right variants
    - Supports --num-housings 1-5
    - Supports --scale for prototyping
    - Includes per-tuner interference report
    - Uses --no-interference flag to skip slow checks
2026-01-29 Load mesh rotation from reference/mesh_alignment_m{module}.json
    - Add load_mesh_alignment() to load optimal rotation from wormgear output
    - Apply Z-offset correction using lead angle geometry:
    effective_axial_shift = z_offset × tan(lead_angle)
    z_correction = (effective_axial_shift / lead) × 360° / ratio
    - For z_offset=0.425mm: correction is +0.75° (14° → 14.75°)
    - Removes dependency on deprecated config/assembly.json
2026-01-29 Refactor assembly visualization to use shared gang_assembly module
    - gang_assembly.py: Add create_positioned_assembly(), position_tuner_at_housing(),
    check_interference(), run_interference_report(), COLOR_MAP
    - visualize_*.py: Simplify by using gang_assembly utilities
    - regenerate_gears.py: Run wormgear once (generates mesh alignment too)
    - wheel.py: Add calculate_mesh_rotation_analytical() for Z-offset correction
    [wheel_m0.5_z13.step]
2026-01-29 Fix frame parameters: 10mm box outer, 1mm wall thickness
    - box_outer: 10.35 → 10.0mm
    - wall_thickness: 1.1 → 1.0mm
    This eliminates all interference in 1-gang assembly.
2026-01-29 Add interference checking to assembly build with tests
    - Add check_interference parameter to create_positioned_assembly()
    - Add AssemblyInterferenceError exception raised when interference found
    - Add tests/test_assembly.py with 4 tests for interference checking
2026-01-29 Consolidate build scripts and add STL export fallback
    - Replace build_all.py and export_stl.py with unified build.py
    - Add --hand right|left|both (default: both) for L/R variants
    - Add --format stl|step|both (default: both) for output formats
    - Use mirror_for_left_hand() to create LH variants from RH geometry
    - String post exported once (symmetric, no L/R suffix)
    - Add OCP StlAPI_Writer fallback for complex geometry with degenerate faces
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2026-01-30 Improve animate.py: hardware, transparency, rotation fixes
    - Add washers and screws to animation
    - String post rotates with wheel (connected via DD cut)
    - Peg washer/screw rotate with peg head
    - RH wheel/post rotate clockwise, worm matches
    - Frame is transparent blue (30% alpha)
    - Fix animation reset bug by using 359.9° instead of 360°
    - Default duration 8 seconds for smoother viewing
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2026-01-30 Remove broken Blender export from animate.py
    The Blender export feature was not working correctly. Removed:
    - --export-blender CLI argument
    - b3d_to_trimesh helper function
    - GLB export and Blender script generation code
    The build plate generator (generate_print_plate.py) works correctly.
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2026-01-30 docs: sync spec.md with code parameters
    - Frame: 10.0mm box, 1.0mm wall (was 10.35/1.1)
    - Wheel face_width: 7.5mm (was 6.0mm)
    - DD cut length: 7.5mm to match wheel
    - String post total: 15.0mm (was 13.5mm)
    - Section 8 Z coords: fixed to match Section 2 convention
    - Worm type: now supports cylindrical or globoid
    https://claude.ai/code/session_016CdvsTsqcoxWfAyRtwqsF1
2026-01-30 feat: tighten bearing tolerances for 100N string tension
    Post and peg bearing holes reduced from +0.2mm to +0.05mm clearance:
    - Post bearing: 4.2mm → 4.05mm (reamed)
    - Peg bearing: 4.0mm → 3.85mm (reamed)
    Reduces post tilt under load from ~11° to ~3° max, improving
    gear mesh stability for wire-strung English guitar service.
    Updated:
    - Section 1a tolerance profiles (now shows bearing vs clearance)
    - Section 2 sandwich drilling pattern
    - Section 5 string post dimensions
    - Section 6 Phase 1 manufacturing
    - Section 9 validation checklist
    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
2026-01-31 feat: switch to balanced M0.6 gear config with derived bearing holes
    - Default gear config now M0.6, 10:1 ratio (was M0.5, 13:1)
    - Peg shaft increased to 4.0mm for stronger M2 tap wall (1.2mm vs 0.95mm)
    - All bearing holes now derived from component dimensions + 0.05mm clearance:
    - worm_entry_hole = shoulder_diameter + 0.05mm
    - peg_bearing_hole = shaft_diameter + 0.05mm
    - post_bearing_hole = bearing_diameter + 0.05mm
    - M2.5 washer with M2 screw for 3x better peg retention
    - Interference threshold scales with number of housings
    - Added --gear CLI flag to scripts for multi-config support
    - Reference STEP files updated for M0.6 gear geometry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
    [wheel_m0.6_z10.step]
2026-01-31 feat: add dacite dependency and tuner_config.json override support
    - Add dacite>=1.8.0 dependency for flexible JSON deserialization
    - Add load_tuner_config() for per-gear-config parameter overrides
    - Support frame, string_post, peg_head overrides via tuner_config.json
    - Overrides are applied before deriving bearing holes, so changing
    shaft_diameter or bearing_diameter correctly updates frame holes
    Example tuner_config.json:
    {
    "frame": {"box_outer": 11.0},
    "peg_head": {"shaft_diameter": 4.5},
    "string_post": {"bearing_diameter": 4.5}
    }
    Closes functionality gap from PR #14.
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2026-01-31 feat: require --gear flag and organize config directories
    - Make --gear required on build.py, viz.py, animate.py
    - Add --list-gears option to discover available configs
    - Move config/worm_gear.json to config/original/
    - Add example tuner_config.json for per-gear parameter overrides
    - Fix LH wheel mesh rotation (negate for mirrored geometry)
    - Update CI to use --gear balanced
    - Per-gear output directories (output/<gear>/)
2026-02-01 feat: add axial play parameters and interference checking to build
    - Add post_bearing_axial_play (0.2mm) for string post free rotation
    - Add peg_bearing_axial_play (0.2mm) for peg head free rotation
    - Add dd_cut_clearance (0.1mm) to ensure screw clamps wheel to shoulder
    - Remove redundant shaft_gap and washer_clearance from peg shaft formula
    - Derive bearing_length and dd_cut_length from config parameters
    - Add interference checking to build.py (runs before export)
    - Document sandwich mechanism in spec.md Section 5a
    - Document wall_thickness as manufacturing constraint in CLAUDE.md
    - Add BH gear config STEP files and geometry analysis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
    [worm_m0.6_z1.step]
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2026-02-01 fix: improve STL mesh quality and add shape validation
    - Add explicit BRepMesh tessellation with tight tolerances
    - Auto-repair small holes from null triangulation faces
    - Add check_shape_quality() and check_mesh_quality() validation functions
    - Add shape quality checks to all component creation functions
    - Default output format to STL (STEP may have non-manifold edges)
    Fixes mesh quality issues that caused Bambu Studio to report
    non-manifold edges (reduced from 743 to 0 for peg_head).
2026-02-01 feat: add validation for wheel/worm fitting in housing
    Add checks to warn if wheel or worm are too large for the housing:
    - Wheel fits inside housing: wheel tip diameter < frame box_inner
    - Wheel width fits in housing: wheel face_width < box_inner
    - Worm length fits across housing: worm length <= box_inner (spans cavity)
    - Worm fits through entry hole: worm tip diameter < entry_hole
    Note: Worm axis is perpendicular to frame length - it spans ACROSS
    the housing cavity through entry holes, not along the housing.
    Current clearances (bh profile):
    - Wheel diameter: 0.60mm (7.2mm in 7.8mm cavity)
    - Wheel width: 0.20mm (7.6mm in 7.8mm cavity) - tight!
    - Worm length: 0.00mm (7.8mm worm spans 7.8mm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
2026-02-01 fix: reduce post bearing axial play to 0.1mm
    Tighten the axial tolerance for the string post bearing section
    from 0.2mm to 0.1mm, reducing bearing length from 1.3mm to 1.2mm.
2026-02-01 fix: create LH frame with correct label instead of mirroring
    Mirroring the RH frame geometry caused the etched "R" label to appear
    as a backwards "R" on the LH frame. Now we create the LH frame directly
    with Hand.LEFT config, which correctly etches "L".
2026-02-01 fix: remove unnecessary frame mirroring in print plate generator
    The config is already created with the correct hand parameter, so
    mirroring the frame was duplicating the geometry flip and causing
    the etched label to be backwards. Frame now uses correct L/R label.
2026-02-01 docs: sync spec.md with current parameters.py values
    Update spec.md to match the current M0.6/10:1 gear configuration and
    corrected frame dimensions:
    Frame:
    - wall_thickness: 1.0mm → 1.1mm (fixed manufacturing constraint)
    - box_inner: 8.0mm → 7.8mm (computed)
    - worm_entry_hole: 6.2mm → 7.05mm (shoulder + clearance)
    - peg_bearing_hole: 3.85mm → 4.05mm
    Gear (M0.5/13:1 → M0.6/10:1):
    - Module: 0.5 → 0.6
    - Ratio: 13:1 → 10:1
    - Worm tip: 6.0mm → 7.0mm
    - Wheel tip: 7.5mm → 7.2mm
    - Center distance: 5.75mm → 5.9mm
    - Pressure angle: 25° → 20°
    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
2026-02-01 fix: use 0.01mm linear tolerance for STL tessellation
    The previous 0.001mm tolerance caused non-manifold edges in peg head
    meshes with globoid worms (bh11-cd config). The tighter tolerance
    struggles with thin faces at thread roots, creating geometry that
    doesn't triangulate cleanly.
    0.01mm (10 microns) is still very fine for 3D printing while avoiding
    the tessellation failures.
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2026-02-02 feat: improve STL mesh repair with before/after reporting
    - Add pymeshfix for robust multi-hole mesh repair
    - Show mesh quality before attempting repair (NME count, holes)
    - Show quality after repair with method used (pymeshfix or fan)
    - Fix NME detection to include boundary edges (c != 2, not c > 2)
    - Add mesh-repair optional dependency group
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2026-02-02 fix: reduce M2 tap depth to 3mm for better wall thickness
    - Change tap_depth from 4.0mm to 3.0mm
    - Change screw_length from 4.0mm to 3.0mm (M2x3 screw)
    - String tension pulls worm into frame, screw just holds in place
    - Wall after tapping: 0.83mm (was 0.59mm with M2x4)
    - Safety factor: 10.9x (was 8.1x)
2026-02-02 fix: reduce wheel inlet hole from 8mm to 5.1mm
    Wheel enters cavity sideways from open frame end, not through bottom hole.
    The 5.1mm hole (4.9mm M2 washer + 0.2mm tolerance) only needs to clear
    the M2 washer/screw for post retention.
    Assembly constraints documented:
    - Worm MUST be installed before wheel (required for globoid meshing)
    - Wheel cannot be pre-attached to post (7.05mm OD > 4.05mm bearing hole)
    - Correct order: Worm → Wheel → Post
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2026-02-02 feat: add cutting jig for brass frame manufacturing
    Parametric CAD jig to hold brass box section and guide saw cuts:
    - U-channel (10.3mm x 10mm) holds brass flush with jig top
    - Saw guide slots with kerf compensation for housing boundaries
    - Fixed locating plug at Y=0, moveable end stop with plug at Y=145
    - M5 heat-set insert for end stop bolt
    Includes spec document with dimensions and comparison notes for
    future drilling jig design.
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2026-02-04 fix: remove remaining hardcoded gear references from tests
    - test_assembly.py: use gear_paths fixture from conftest.py instead of local override
    - test_validation.py: allow profile shift deviation in center distance check
    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
2026-02-05 feat: add drilling jig, integrate both jigs with config system
    - Add drilling jig (clamshell + base plate) with M14 stepped bushing
    pockets, 5mm minimum rim, dynamic wall extension per gear profile
    - Refactor cutting jig to use config system (was hardcoded)
    - Both jigs now use --gear argument and read dimensions from JSON,
    matching build.py pattern
    - Add --num-housings override to both jigs for N-gang support
    - Move jig scripts from scripts/experiments/ to scripts/
    - Fix validation check #4: wheel inlet hole is for M2 washer clearance,
    not wheel OD (wheel slides in sideways from open frame end)
2026-02-05 fix: use M3 hardware for jig bolt/insert holes, output to gear subdirectory
    - Change bolt holes from M5 (5.5mm) to M3 (3.4mm clearance, 5.5mm
    socket head counterbore) in both cutting and drilling jigs
    - Change heat-set inserts from M5 (6.4mm OD) to M3 (5.0mm OD, 4.0mm
    deep) to match available hardware
    - Insert hole depth now matches actual insert height instead of
    oversized through-hole
    - Output STEP files to output/{gear}/ instead of flat output/
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2026-02-05 feat: add prototype mode to drilling jig (#43)
    * feat: add prototype mode to drilling jig, deepen insert pockets
    Drilling jig now supports --mode production|prototype:
    - production (default): M14 stepped bushing pockets, 40mm wide,
    full wall extension for bushing enclosure
    - prototype: simple through-holes at drill diameter, 30mm wide,
    3mm wall extension for structural support around side holes
    Both jigs: heat-set insert pockets deepened from 4mm to 9mm
    (4mm insert + 5mm clearance for push-in and bolt pass-through).
    * feat: improve jig printability and frame removal
    Cutting jig:
    - Add 45° chamfers to plug bottom edges (elimina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
2026-02-06 fix: undersize heat-set insert pockets for grip (5.0→4.7mm) (#44)
    Inserts were falling out because pocket matched insert OD exactly.
    Reduced to 4.7mm (0.3mm interference) so plastic melts around knurling.
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2026-02-07 feat: loosen DD fit for compression-based wheel retention
    Shift from interference-fit DD coupling to slip-fit DD with compression
    retention from M2 washer+screw:
    - Add dd_shaft_clearance (0.1mm): post DD 3.4mm/2.4mm AF vs bore 3.5mm/2.5mm AF
    - Increase dd_cut_clearance (0.1→0.5mm): more compression travel at wheel bottom
    - Position wheel in clamped state (top against bearing shoulder, gap at bottom)
    - Update calculate_worm_z ALIGNED mode to match new wheel center
    - Update spec.md DD dimensions and derived lengths
    - Include updated bh11-cd-fx config (regenerated STEP + analysis)
    Validation: 16/16 assembly checks pass on both bh11-cd and bh11-cd-fx.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
    [worm_m0.6_z1.step]
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2026-02-09 feat: add c13 gear profile and fix peg head boolean fusion for cylindrical worms
    The c11/c13 cylindrical worm STEPs produce degenerate zero-volume artifacts
    during OCCT boolean union, returning ShapeList instead of Solid. This broke
    interference checks (reporting 734mm³ phantom interference) and downstream
    geometry operations.
    Fix: use worm root diameter for core shaft (ensures volumetric overlap with
    worm STEP), add 0.1mm boundary overlaps for reliable fusion, and filter out
    degenerate shapes from boolean results.
    [wheel_m0.5_z13.step, wheel_m0.6_z11.step]
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2026-02-09 fix: prevent OCCT from consuming worm teeth during boolean fusion
    Core shaft radius was exactly equal to worm root radius, creating
    coincident surfaces that caused OCCT to eliminate the teeth. Undercut
    core by 0.1mm so shaft surface is inside the worm solid.
    Also adds c13-10 config (1.0mm wall, 7.7mm gear width).
    [wheel_m0.5_z13.step]
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2026-02-11 fix: swept worm peg head merge — fill relief groove and extend shaft
    Update peg head to work with new swept worm STEP geometry:
    - Load relief_groove_radius from worm_gear.json to size core shaft
    - Fill bearing-end relief groove to strengthen M2 tap hole bore
    - Add volume guard in _heal_shape() to prevent ShapeFix destroying valid solids
    - Include washer_clearance (0.1mm) in bearing wall length for shaft protrusion
    Also includes regenerated c13-10 wheel/worm STEP files from swept worm tool.
    [wheel_m0.5_z13.step]
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2026-06-10 chore: track session artifacts — assembly animation, manufacturer pack, gear test set
    - scripts/animate_assembly.py: step-by-step 1-gang assembly animation
    (bd_animation + OCP viewer), plus its rendered outputs assembly.gif,
    assembly.mp4 and turning.gif
    - sent/fixedv2/: the exact STEP/GLB/zip pack and order page sent to the
    manufacturer (provenance record of what was ordered)
    - config/c13-10/test/: gear-calculator test set for the c13-10 profile
    (design docs, geometry analysis, STEP/STL/3MF outputs)
    uv.lock.local-backup deliberately left untracked (local backup file).
    [frame_lh_5gang.step, frame_rh_5gang.step, peg_head_lh.step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]
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
